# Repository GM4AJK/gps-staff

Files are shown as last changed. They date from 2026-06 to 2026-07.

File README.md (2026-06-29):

# GPS Survey Staff

A DIY RTK GNSS survey staff -- a handheld device for centimetre-level accurate position surveying.

## What is this?

The system consists of two identical handheld units: one set up as a fixed base station, the other carried by the surveyor as a rover. The two communicate wirelessly so the rover can compute corrected, centimetre-accurate positions in real time (RTK -- Real-Time Kinematic positioning).

It's designed to be self-contained and portable -- battery powered, with an onboard display, simple button/encoder controls, and onboard logging of survey data for later processing.

## Project status

Active development. PCB v1.0 ordered 2026-06-25. Firmware bring-up ongoing on Nucleo dev boards.

## Documentation

| Location | Contents |
|---|---|
| [`sdd/`](sdd/) | System design: architecture, unit specs, BLE protocols, UI screen specs |
| [`docs/arch/`](docs/arch/) | Firmware architecture: RTCM3, OTA protocol, SX1262 driver, SD card |
| [`docs/datasheets/`](docs/datasheets/) | Component datasheets and reference documents |
| [`hardware/rtk/`](hardware/rtk/) | PCB electronics design: KiCad files, BOM, design notes |

## License

MIT — see [LICENSE](LICENSE). This project is provided for educational and personal use without warranty of any kind. No liability is accepted for any use of these designs, including use in safety-critical or commercial applications. Use at your own risk.

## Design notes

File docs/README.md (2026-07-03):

# Documents

A catalog of reference documents kept in this repo.

## GNSS coordinate transforms

| Document | Contents |
|---|---|
| [OSGB36_OSTN15_OSGM15.md](OSGB36_OSTN15_OSGM15.md) | How to generate the OSTN15/OSGM15 binary grid, verify it against OS test vectors, deploy it to the tablet SD card, and use `Ostn15Service` to convert ETRS89 → OSGB36/ODN at runtime |

## Future goals

| Document | Contents |
|---|---|
| [TEC.md](TEC.md) | Ionospheric TEC monitoring using the permanent base F9P — dual-frequency geometry-free combination, pierce point calculation, multipath separation, and real-time Three.js globe visualisation. Prerequisite checklist included. |

## Architecture (`arch/`)

System and firmware architecture documentation, with PlantUML diagrams.

| Document | Contents |
|---|---|
| [arch/README.md](arch/README.md) | System overview — hardware roles, data flow, firmware module map |
| [arch/sx1262.md](arch/sx1262.md) | SX1262 driver — bring-up sequence, interrupt model, full API |
| [arch/ota-protocol.md](arch/ota-protocol.md) | OTA protocol — packet format, ota_tx / ota_rx, timing analysis |
| [arch/rtcm3.md](arch/rtcm3.md) | RTCM3 framing — frame format, state machine, buffer pool, CRC24Q |
| [arch/sdcard.md](arch/sdcard.md) | SD card module — state machine, card-detect debounce, DMA transfer model, FatFS integration, D-cache maintenance |

## Datasheets (`datasheets/`)

| Document | Description |
|---|---|
| [Nucleo-F767ZI-Schematic.pdf](datasheets/Nucleo-F767ZI-Schematic.pdf) | Schematic for the Nucleo-F767ZI dev board (STM32F7), used for firmware bring-up before the custom PCB |
| [ANN-MB-00-Datasheet.pdf](datasheets/ANN-MB-00-Datasheet.pdf) | u-blox ANN-MB-00 (UBX-18049862) GNSS antenna datasheet -- the antenna specced for this project. [DigiKey product page](https://www.digikey.co.uk/en/products/detail/u-blox/ANN-MB-00/9817928) |
| [ZED-F9P-05B-Datasheet.pdf](datasheets/ZED-F9P-05B-Datasheet.pdf) | u-blox ZED-F9P-05B GNSS module datasheet -- the GNSS module specced for this project. [DigiKey product page](https://www.digikey.co.uk/en/products/detail/u-blox/ZED-F9P-05B/24708221) |
| [TPS63020-Datasheet.pdf](datasheets/TPS63020-Datasheet.pdf) | TI TPS63020 buck-boost regulator datasheet -- the regulator specced for this project. Order code `TPS63020DSJR` (14-pin VSON exposed-pad, tape-and-reel) confirmed to match. [DigiKey product page](https://www.digikey.co.uk/en/products/detail/texas-instruments/TPS63020DSJR/2353761) |
| [BQ24075-Datasheet.pdf](datasheets/BQ24075-Datasheet.pdf) | TI BQ24075 power path management / battery charger datasheet -- the chip specced for this project. Order code `BQ24075TRGTR` (16-pin VQFN 3x3, tape-and-reel) confirmed to match. [DigiKey product page](https://www.digikey.co.uk/en/products/detail/texas-instruments/BQ24075TRGTR/2202252) |
| [STM32F765VIT6-Datasheet.pdf](datasheets/STM32F765VIT6-Datasheet.pdf) | STMicroelectronics STM32F765VIT6 MCU datasheet -- the MCU specced for this project (LQFP100, base+rover unified design). [DigiKey product page](https://www.digikey.co.uk/en/products/detail/stmicroelectronics/STM32F765VIT6/6137842) |
| [Core1262-LF-Schematic.pdf](datasheets/Core1262-LF-Schematic.pdf) | Waveshare Core1262-LF module schematic (410-510MHz variant) -- the LoRa module specced for this project (covers the 433/434MHz ISM sub-band and 70cm amateur band under GM4AJK licence). Sourced from the [Waveshare wiki](https://www.waveshare.com/wiki/Core1262-868M) (covers the LF/HF family). Note: not available on DigiKey -- ordered via Amazon; double-check the listing is the **LF** (410-510MHz) variant, not the 868M/HF (863-870MHz) variant which does not cover the required bands |
| [SX1262-Datasheet.pdf](datasheets/SX1262-Datasheet.pdf) | Semtech SX1262 LoRa transceiver chip datasheet -- the RF chip on the Core1262-LF module. Sourced from the [Waveshare wiki](https://www.waveshare.com/wiki/Core1262-868M). See also the [libdriver/sx1262](https://github.com/libdriver/sx1262) open-source driver library |
| [um1974-stm32-nucleo144-boards-mb1137-stmicroelectronics-3.pdf](datasheets/um1974-stm32-nucleo144-boards-mb1137-stmicroelectronics-3.pdf) | STMicroelectronics UM1974 -- STM32 Nucleo-144 boards (MB1137) user manual. Reference for power supply options (Section 7.4), JP3/JP1 jumper configuration, and connector pinouts for the Nucleo-F767ZI bench board |
| [um2448-stlinkv3set-debuggerprogrammer-for-stm8-and-stm32-stmicroelectronics-1.pdf](datasheets/um2448-stlinkv3set-debuggerprogrammer-for-stm8-and-stm32-stmicroelectronics-1.pdf) | STMicroelectronics UM2448 -- ST-LINK V3SET debugger/programmer user manual. Reference for CN2/CN3 connector pinouts used when wiring to the Nucleo-F767ZI bench board |
| [SSD1309.pdf](datasheets/SSD1309.pdf) | Solomon Systech SSD1309 OLED display controller datasheet -- the controller for the I2C1 OLED module being added to the Nucleo-F767ZI sandbox |
| [LSM6DSOX.pdf](datasheets/LSM6DSOX.pdf) | STMicroelectronics LSM6DSOX accelerometer + gyroscope datasheet -- the IMU specced for tilt compensation and the bubble-level display, replacing the BNO085 |
| [LSM6DSRX-Datasheet.pdf](datasheets/LSM6DSRX-Datasheet.pdf) | STMicroelectronics LSM6DSRX accelerometer + gyroscope datasheet -- pin-compatible (LGA-14L) alternative to the LSM6DSOX with the same Machine Learning Core/FSM, considered after the LSM6DSOXTR went out of stock. WHO_AM_I reads 0x6B instead of the LSM6DSOX's 0x6C |
| [adafruit_LSM6DSOX_BOB.png](datasheets/adafruit_LSM6DSOX_BOB.png) | Adafruit LSM6DSOX breakout (#4438) schematic -- shows the I2C/SPI signals and address strapping for the breakout board |
| [LIS3MDL.pdf](datasheets/LIS3MDL.pdf) | STMicroelectronics LIS3MDL 3-axis magnetometer datasheet -- the magnetometer originally specced for azimuth/heading. **Now obsolete (no longer available to purchase)**; replaced by the MMC5603NJ -- see below. WHO_AM_I reads 0x3D, I2C address 0x1C or 0x1E depending on the SDO/SA1 pin |
| [MMC5603NJ_RevB_7-12-18.pdf](datasheets/MMC5603NJ_RevB_7-12-18.pdf) | MEMSIC MMC5603NJ 3-axis AMR magnetometer datasheet (Rev B, 2018-07-12) -- replacement for the obsolete LIS3MDL. ±30G FSR, 20-bit resolution (0.0625mG/LSB), 2mG RMS noise, ±1° heading accuracy, I²C fast mode (400kHz) / I3C, 1.62–3.6V supply. **Note:** data-ready interrupt is I3C only -- I²C mode requires polling `Status1.Meas_m_done`. Fixed I²C address (no address-select pin). Package is 0.8×0.8×0.4mm WLP -- requires reflow; see MMC560x-B prototyping board below for the PCB design approach. [DigiKey product page](https://www.digikey.co.uk/en/products/detail/memsic-inc/MMC5603NJ-B/10452797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) |
| [MMC560x-B_UG_RevA.pdf](datasheets/MMC560x-B_UG_RevA.pdf) | MEMSIC MMC560x-B Prototyping Board User Guide (Rev A) -- 22×12mm sub-board with MMC5603NJ pre-assembled and passive components fitted. Breaks out VDDIO, VDD3V, GND, SDA, SCL on 0.1" (2.54mm) pitch headers. Intended PCB design approach for the F765VIT carrier: mount on tall headers to (1) avoid hand-soldering the 0.8mm WLP die and (2) elevate the sensor above PCB-level magnetic interference sources (power traces, inductors) |
| [um1724-stm32-nucleo64-boards-mb1136-stmicroelectronics-4.pdf](datasheets/um1724-stm32-nucleo64-boards-mb1136-stmicroelectronics-4.pdf) | STMicroelectronics UM1724 -- STM32 Nucleo-64 boards (MB1136) user manual. Reference for power supply options (Section 7.5), JP5/JP6 (IDD) jumper configuration, and connector pinouts for the Nucleo-F446RE/G491RE bench boards |
| [Ofcom-IR-2030.pdf](datasheets/Ofcom-IR-2030.pdf) | Ofcom UK Interface Requirement (IR) 2030 -- licence-exempt Short Range Devices (SRDs). Reference for the 433/434MHz power/duty-cycle limits (Table 3.1, IR2030/1/10-12) used to confirm the LoRa link operates under the GM4AJK amateur licence rather than the SRD exemption (see `sdd/README.md`) |
| [um2397-stm32g4-nucleo32-board-mb1430-stmicroelectronics-5.pdf](datasheets/um2397-stm32g4-nucleo32-board-mb1430-stmicroelectronics-5.pdf) | STMicroelectronics UM2397 -- STM32 Nucleo-32 boards (MB1430) user manual. Reference for power supply, jumper configuration, and connector pinouts for the Nucleo-G431KB Fake-F9P boards |
| [USB3300-EZK-TR.pdf](datasheets/USB3300-EZK-TR.pdf) | Microchip USB3300 Hi-Speed USB ULPI PHY datasheet -- the external PHY specced for the rover USB OTG HS interface (480 Mbps MSC + CDC composite). QFN-32 (5x5mm). [DigiKey product page](https://www.digikey.co.uk/en/products/detail/microchip-technology/USB3300-EZK-TR/2355968) |
| [usb4105-spec.pdf](datasheets/usb4105-spec.pdf) | GCT USB4105-GF-A USB-C receptacle datasheet — mid-mount, top-entry, SMD, used as J1 (power/data in). |
| [USBLC6-2SC6.pdf](datasheets/USBLC6-2SC6.pdf) | STMicroelectronics USBLC6-2SC6 dual-line USB ESD protection datasheet — SOT-23-6, 0.5pF/line, 5.25V clamp. Selected for D2 (USB D+/D- protection), replacing the bulk-only PRTR5V0U2X. Single device covers both lines. |
| [KEM_T2076_T52X-530.pdf](datasheets/KEM_T2076_T52X-530.pdf) | Kemet/Yageo T52X/T530 KO-CAP polymer tantalum capacitor datasheet -- covers the T529P series (Miniature, substrate terminal). T529P106M010AAE200 (10µF 10V 0805/EIA-2012-10, 200mΩ ESR) selected for C16/C18/C20 bulk decoupling on STM32F765VIT VDD rails. Fail-open polymer cathode. -- the external PHY specced for the rover USB OTG HS interface (480 Mbps MSC + CDC composite). QFN-32 (5x5mm). [DigiKey product page](https://www.digikey.co.uk/en/products/detail/microchip-technology/USB3300-EZK-TR/2355968) |

## BNO085 (`datasheets/bno085/`)

Out-of-spec side project (not part of the LSM6DSOX+LIS3MDL tilt/azimuth design) -- restored from history for a fresh attempt at the BNO085 over I2C instead of SPI.

| Document | Description |
|---|---|
| [BNO085-Datasheet.pdf](datasheets/bno085/BNO085-Datasheet.pdf) | CEVA/Bosch BNO085 9-DOF IMU datasheet (BNO08X DS 1000-3927 v1.17). [DigiKey product page](https://www.digikey.co.uk/en/products/detail/ceva-technologies-inc/BNO085/9445940) |
| [Adafruit-BNO085-BOB-Schematic.png](datasheets/bno085/Adafruit-BNO085-BOB-Schematic.png) | Adafruit BNO085 9-DOF breakout (#4754, rev C) schematic -- shows the level-shifted SPI/I2C signals (SCK, MOSI, MISO, CS, INT) and P0/P1/BOOTP strapping options. Sourced from the [Adafruit Learning Guide](https://learn.adafruit.com/adafruit-9-dof-orientation-imu-fusion-breakout-bno085) |
| [SH-2-Reference-Manual.pdf](datasheets/bno085/SH-2-Reference-Manual.pdf) | CEVA SH-2 Reference Manual (1000-3625) -- defines the SH-2 sensor hub protocol used over SHTP by the BNO085: Set/Get Feature commands, the full sensor report ID table (e.g. `0x05` Rotation Vector, `0x08` Game Rotation Vector, `0x09` Geomagnetic Rotation Vector), and input report payload layouts (quaternion scaling, accuracy fields, etc.). Sourced from [ceva-ip.com](https://www.ceva-ip.com/wp-content/uploads/SH-2-Reference-Manual.pdf) |

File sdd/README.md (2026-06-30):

# Software and System Design

## Architecture

System-level design: unit roles, technology decisions, data flow, BLE protocols.

| Document | Contents |
|---|---|
| [architecture/SYSTEM.md](architecture/SYSTEM.md) | System overview — unit roles, technology decisions, data flow, RTK concepts |
| [architecture/BASE.md](architecture/BASE.md) | Base unit — implemented capabilities and pending work |
| [architecture/ROVER.md](architecture/ROVER.md) | Rover unit — implemented capabilities and pending work |
| [architecture/HANDHELD.md](architecture/HANDHELD.md) | Handheld/tablet — implemented capabilities and pending work |
| [architecture/GATT.md](architecture/GATT.md) | BLE GATT service and characteristic registry |

## Features

Numbered feature specifications and UI screen specs.

> **When adding a new spec file:** also add it to the `screens` array in
> [`features/00000-Overview.html`](features/00000-Overview.html) so it appears
> in the spec navigator.
>
> **When implementing a screen:** update
> [`features/completed-index.md`](features/completed-index.md) — tick off items
> as they are built and note anything implemented with fake/placeholder data so
> it gets revisited when the real hardware is live.

| Document | Contents |
|---|---|
| [features/00001-wifi-provisioning.md](features/00001-wifi-provisioning.md) | WiFi provisioning — all phases bench-verified |
| [features/00006-OperatingMode.html](features/00006-OperatingMode.html) | Operating Mode selector — 6 modes: Local RF, Rover NTRIP, Base via relay caster, Dual NTRIP, Direct TCP, Fixed Base Station; compact cards with no inline sub-selectors (sub-options live on each mode's config screen) |
| [features/00002-HomeScreen.html](features/00002-HomeScreen.html) | Home screen spec (1024×600 landscape) |
| [features/00003-BaseConfig-0.html](features/00003-BaseConfig-0.html) | Base Config — State 0: top-level mode selector (Survey-in / RTCM Streaming / Satellite View / config strip) |
| [features/00003-BaseConfig-1.html](features/00003-BaseConfig-1.html) | Base Config — State 1: normal view, network table |
| [features/00003-BaseConfig-2.html](features/00003-BaseConfig-2.html) | Base Config — State 2: password entry |
| [features/00003-BaseConfig-2-kbd.html](features/00003-BaseConfig-2-kbd.html) | Base Config — State 2 with virtual keyboard |
| [features/00003-BaseConfig-3.html](features/00003-BaseConfig-3.html) | Base Config — State 3: connecting (spinner) |
| [features/00003-BaseConfig-4.html](features/00003-BaseConfig-4.html) | Base Config — State 4: connection failed |
| [features/00003-BaseConfig-SurveyIn-A.html](features/00003-BaseConfig-SurveyIn-A.html) | Base Config — Survey-in State A: Ready (editable settings, Start button) |
| [features/00003-BaseConfig-SurveyIn-A-kbd.html](features/00003-BaseConfig-SurveyIn-A-kbd.html) | Base Config — Survey-in State A: Numeric keyboard (duration in minutes up to 5 digits; accuracy in metres; tab toggle between both fields) |
| [features/00003-BaseConfig-SurveyIn.html](features/00003-BaseConfig-SurveyIn.html) | Base Config — Survey-in State B: In Progress (progress ring, condition chips, live stats, cancel) |
| [features/00003-BaseConfig-SurveyIn-C.html](features/00003-BaseConfig-SurveyIn-C.html) | Base Config — Survey-in State C: Complete (full green ring, Begin RTCM Streaming button) |
| [features/00003-BaseConfig-Streaming.html](features/00003-BaseConfig-Streaming.html) | Base Config — RTCM Data (broadcast stats, RTCM message activity, rover connection + LoRa link quality) |
| [features/00003-BaseConfig-FixedPos.html](features/00003-BaseConfig-FixedPos.html) | Base Config — Fixed Position entry (monument/benchmark, OSGB36/WGS84) |
| [features/00004-BaseSatelliteView-1.html](features/00004-BaseSatelliteView-1.html) | Base Satellite View — sky plot (az/el, GPS+GLONASS), CN0 bar chart, fix status |
| [features/00005-AboutScreen-1.html](features/00005-AboutScreen-1.html) | About screen — product identity, firmware/hardware versions, the Wizard |
| [features/00007-RoverConfig-Mode1.html](features/00007-RoverConfig-Mode1.html) | Rover Config (Mode 1 — Local RF Link) — pole height entry, live RF link status (RSSI/SNR/frame count), F9P fix type; two dev states: Waiting / Receiving |
| [features/00008-Mode5-RemoteListener.html](features/00008-Mode5-RemoteListener.html) | Mode 5 Direct TCP — Remote Listener (whichever device stays on home WiFi): listen port config, router port-forward reminder, TCP connection status; two dev states: Idle / Connected |
| [features/00009-Mode5-MobileConnector.html](features/00009-Mode5-MobileConnector.html) | Mode 5 Direct TCP — Mobile Connector (whichever device is in the field on hotspot): remote hostname + port entry, Connect/Disconnect button, TCP stream stats; three dev states: Disconnected / Connecting / Connected |
| [features/00013-UsbStorageActive.html](features/00013-UsbStorageActive.html) | Tablet — USB Storage Active: MSC holding screen; SD card info (sessions/size/last file) read before FatFS unmount; amber Connected / green Ejected states; "Disconnect anyway…" confirmation guard; documents CDC↔MSC switching and FatFS mutual exclusion |
| [features/00010-StartSurveySession.html](features/00010-StartSurveySession.html) | Rover — Start Survey Session: filename (auto-suggested, FAT-safe), title (required), description (optional); log written to Tablet SD card directly (ESP32-S3 owns the SD slot — no UART extension needed) |
| [features/00011-RoverWorking.html](features/00011-RoverWorking.html) | Rover — Working Screen: live WGS84 position (7 dp lat/lon, 3 dp height MSL), fix quality block (No Fix / RTK Float / RTK Fix), RF corrections status, scrollable captured-points list (ID/label/lat/lon/hAcc), Capture button grabs next F9P epoch and appends row immediately; three dev states |

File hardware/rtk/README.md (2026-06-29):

# RTK PCB — Electronics Design

## PCB v1.0

- **Ordered:** 2026-06-25, JLCPCB. Tagged `PCB-v1.0` in git.
- **DigiKey BOM** ordered same date.
- **KiCad files:** `hardware/rtk/rtk/`
- **Component BOM:** [BOM.md](BOM.md)

### Board overview

| Property | Value |
|---|---|
| Layers | 4 (JLC04161H-7628 stackup) |
| Layer assignment | L1 top signal + components; L2 solid GND; L3 3.3V power plane; L4 bottom signal |
| RF traces | 50Ω microstrip on L1 (L2 GND reference); ~0.7mm trace width; JLCPCB controlled impedance |
| Design | Unified base + rover — single PCB, role selected by jumper at boot |
| Role-specific DNP | USB-C #1 (base: OTG FS) vs USB-C #2 + ULPI PHY (rover: OTG HS) |

### Unified PCB approach

Both units built from the same PCB. Mode selection:
- `PA0` (BASE_ROVER_MODE_SELECT): internal pull-up, link open = base, link to GND = rover
- Same STM32 firmware binary on both; mode gates peripheral init and code paths at runtime
- ESP32-S3 Zero firmware differs per role (base: WiFi NTRIP + BLE prov; rover: BLE GATT server)

---

## Schematic Connection Checklist

Consolidated list of every system wired on the schematic. Reference against the BOM and KiCad
to verify nothing is missed.

1. **ZED-F9P-05B** — UART1 (pins 42/43) → STM32 UART5 (nav + UBX config); UART2 (pins 26/27)
   → STM32 UART7 (PA8 RX ← F9P TXD2, PA15 TX → F9P RXD2) for RTCM input from LoRa;
   D_SEL (pin 47) → PE14 high (UART/I2C mode); RF_IN → GNSS SMA via 50Ω trace;
   1PPS → STM32 GPIO (log timestamping); power + decoupling.

2. **GNSS antenna (ANN-MB-00)** — SMA female through-hole; bias-T 3.3V LNA feed on RF line.

3. **LoRa (Core1262-LF / SX1262)** — dedicated SPI bus; BUSY checked before every transaction;
   DIO1/IRQ → STM32 GPIO; NRESET; separate SMA (433/434MHz).

4. **STM32F765VIT6** — UART (F9P + spare); 2× dedicated SPI (LoRa, IMU); SDMMC1 4-bit
   (PC8/D0, PC9/D1, PC10/D2, PC11/D3, PC12/CLK, PD2/CMD — fixed AF pins);
   I2C4 (PD12 SCL, PD13 SDA — display + IMU); USB OTG FS (PA11/PA12, base) or
   OTG HS + ULPI (rover); ADC (battery divider PA1); SWD.

5. **Power chain** — TPS63020 with D1 + C_SS soft-start on FB node; BQ24075 power-path
   (EN1/EN2/SYSOFF/nCE → STM32 GPIO outputs; nPGOOD/nCHG → STM32 GPIO inputs; TS → 10K to GND);
   LP103454-PCM-LD 2-wire battery connector (J3); 100K/100K battery voltage divider → PA1 ADC.

6. **USB-C (J1)** — single connector footprint, routed via USB3300 ULPI PHY (U8) to STM32
   OTG HS; CC1/CC2 5.1K pull-downs (R11/R12); USBLC6-2SC6 ESD (D2); USB3300 RST (PC1);
   24MHz TCXO (Y2); 12K RBIAS (R9); full decoupling.
   *(Base build: USB-C #2 + ULPI PHY fitted; USB-C #1 DNP. Both are HS-capable.)*

7. **IMU (LSM6DSOX/DSRX, U7)** — I2C4 (PD12/PD13); INT1 → PD14; INT2 → PD15.
   **Magnetometer (MMC5603NJ)** — sub-board via J11 (6-pin 0.1" header, I2C4 bus).

8. **SD card (J6)** — SDMMC1 4-bit bus (fixed AF pins above); card-detect → GPIO; well-decoupled VCC.

9. **STM32 backup domain (VBAT)** — wired directly to 3.3V rail; no coin cell.

10. **Config storage** — SD card file; no EEPROM fitted.

11. **OLED display (SSD1309)** — via J7 header; I2C4 bus (PD12 SCL, PD13 SDA); 0x3C/0x3D.
    On PCB v1.0. Driver bench-verified on F767ZI (task_display.c, ssd1309.c).

12. **Status LEDs** — LD3 (PD5, green) + LD4 (PD6, red): MCU open-drain + pull-ups R20/R21;
    LD1/LD2 hardwired to BQ24075 nPGOOD/nCHG.

13. **Mode-selection jumper** — PA0 GPIO input, internal pull-up; high = base, low = rover.

14. **BOOT0** — 2-pin header, 10K pull-down to GND; fitted = DFU bootloader.

15. **ESP32-S3 Zero (U5)** — spare STM32 UART; 3.3V power + decoupling; mode-select via
    PE2 (GP1) + PE3 (GP2/MODE_VALID). Base: WiFi NTRIP + BLE prov server.
    Rover: BLE GATT server to handheld.

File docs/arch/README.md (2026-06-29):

# GPS Staff — Firmware Architecture

## Overview

The GPS survey staff is a two-unit RTK GNSS system.  A **base station** is
placed at a known (or surveyed-in) position; a **rover** is the handheld
staff.  The base receives RTCM3 correction data from its ZED-F9P GNSS module
and broadcasts it to the rover over a 434 MHz radio link.  The rover feeds
the corrections to its own ZED-F9P to achieve centimetre-level relative
accuracy.

The target hardware is a unified STM32F765VIT6 PCB — **PCB v1.0 ordered
2026-06-25, ZED-F9P-05B ordered same date**.  Until hardware arrives, firmware
development runs on three Nucleo boards as bench stand-ins.

For system-level design decisions (component choices, data flow, unit roles)
see [`sdd/architecture/SYSTEM.md`](../../sdd/architecture/SYSTEM.md), which
includes the high-level block diagram ([system-overview.png](../../sdd/architecture/system-overview.png)).

---

## Bench Hardware Roles

| Board | Role | Key peripherals active |
|---|---|---|
| Nucleo-G431KB (×2) | **Fake F9P** — streams sample RTCM3 data from `firmware/data/` | UART1 @ 115200 — RTCM3 out (base mode) / in (rover mode) |
| Nucleo-F767ZI | **Base station** — bench-tethered, UART debug via PuTTY | UART2 @ 115200 RTCM3 in from G431; SPI2 → SX1262 GFSK TX; SDMMC SD card; I2C1 SSD1309 OLED |
| Nucleo-F446RE | **Rover** — portable, battery-powered, OLED-only UI | SPI2 → SX1262 GFSK RX; UART3 @ 115200 RTCM3 out to G431; I2C1 SSD1309 OLED |

The G431 boards talk to the "big" boards over UART patch cables, simulating
the UART link between the ZED-F9P and STM32F765 on the finished PCB.

---

## System Data Flow

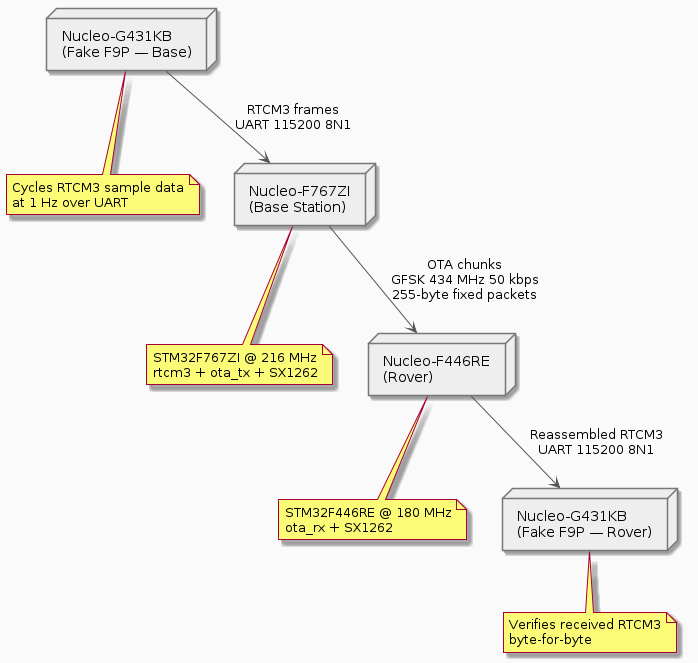
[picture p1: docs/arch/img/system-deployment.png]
System deployment


> **ToDo:** `img/system-deployment.puml` and `img/firmware-modules.puml` were drawn against the
> Nucleo bench stand-in configuration. Both need to be redrawn once PCB v1.0 is in hand and the
> bench boards retire. The replacement high-level block diagram is
> [`sdd/architecture/system-overview.png`](../../sdd/architecture/system-overview.png).

---

## Firmware Module Map

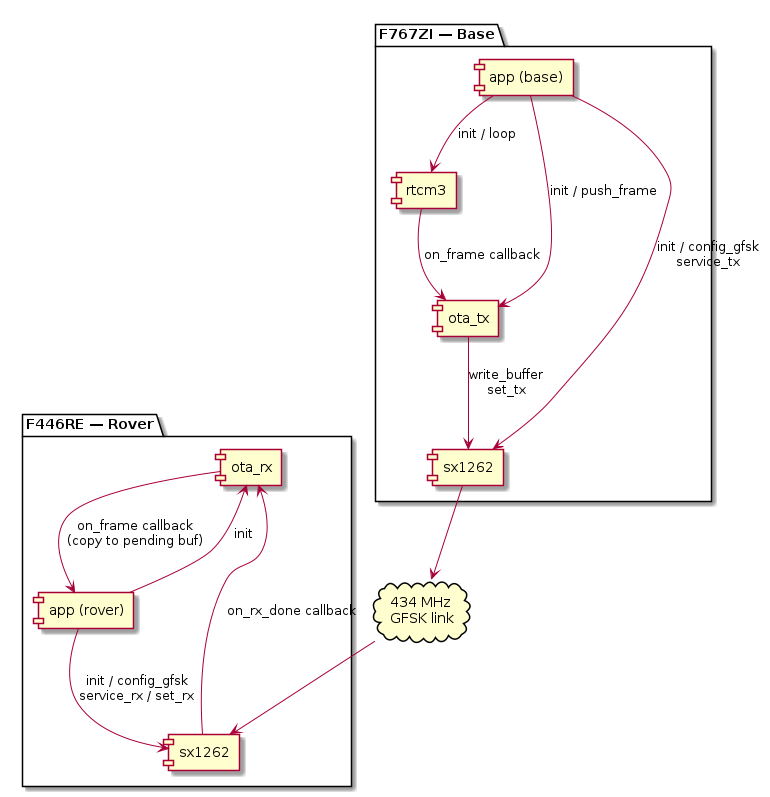
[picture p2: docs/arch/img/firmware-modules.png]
Firmware modules


---

## OTA Packet Format (summary)

Every radio packet is exactly **255 bytes** (fixed-length GFSK).  The first
five bytes are a header; the remaining 250 carry RTCM3 payload bytes.  See
[ota-protocol.md](ota-protocol.md) for the full description.

| Byte | Field | Notes |
|---|---|---|
| 0 | `type` | `0x01` = RTCM3 chunk |
| 1 | `seq` | Frame sequence number, 0–255 wrapping |
| 2 | `chunk_idx` | 0-based chunk index within the frame |
| 3 | `chunk_count` | Total chunks for this frame |
| 4 | `data_len` | Valid RTCM3 bytes in this chunk (1–250) |
| 5–254 | `data` | RTCM3 payload bytes; last chunk zero-padded |

---

## Document Index

| Document | Contents |
|---|---|
| **[sx1262.md](sx1262.md)** | SX1262 driver — architecture, GFSK bring-up, interrupt model, full API |
| **[ota-protocol.md](ota-protocol.md)** | OTA protocol — packet format, ota_tx chunking, ota_rx reassembly, timing |
| **[rtcm3.md](rtcm3.md)** | RTCM3 module — frame format, state machine, buffer pool, IRQ/loop split |
| **[sdcard.md](sdcard.md)** | SD card module — state machine, card-detect debounce, DMA transfer model, FatFS integration |

---

## Bench Status (as of 2026-06-25)

**Radio / RTCM link** — bench-verified and stable:
- GFSK link at 434 MHz, 50 kbps, 25 kHz deviation — 7–8× less air time per cycle than the earlier LoRa SF7/BW500 configuration
- G431 Fake-F9P-Rover holds **SYNCED** indefinitely, zero accumulating mismatches at 1064 bytes/cycle (1005 + 1074 + 1084 + 1094 + 1124 bytes)
- `SX1262_WITH_LOGGING` disabled on rover (F446RE) to keep the post-reception blocking window short; enabled on base (F767ZI) where timing pressure is absent

**SD card** — bench-verified on F767ZI:
- FatFS + SDMMC DMA, sequentially-numbered session files
- `FF_FS_NORTC` set — file timestamps will be wired to ZED-F9P UTC when F9P arrives

**IMU / magnetometer** — bench-verified on F446RE I2C1:
- LSM6DSOX accelerometer + gyroscope driver (PR #124)
- MMC5603NJ magnetometer driver replaces obsolete LIS3MDL (PR #129, heading unvalidated)
- Tilt fusion and soft-iron calibration: deferred pending PCB delivery

**Awaiting hardware:**
- ZED-F9P UART driver — ordered 2026-06-25
- PE2/PE3 mode-select GPIO — PCB v1.0 ordered 2026-06-25

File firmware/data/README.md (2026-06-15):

# Firmware Data

A catalog of binary/data files used by firmware for testing or simulation.

| File | Description |
|---|---|
| [CambridgeSensoriisSample.bin](CambridgeSensoriisSample.bin) | Recorded RTCM3 stream (2728 bytes, 39 frames: 1005/1074/1084 cycle, GPS+GLONASS MSM4), captured from the `CambridgeSensoriis` RTK2GO NTRIP mount. Intended as a canned playback payload for a Nucleo-based "fake F9P" base, to test the base->LoRa->rover transport pipeline without real GNSS hardware |

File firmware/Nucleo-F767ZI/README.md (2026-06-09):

# Nucleo-F767ZI Sandbox

A bare CubeMX project targeting the STM32F767ZI Nucleo board, used as a
"play pen" for developing and bench-testing modules before porting them
into `rtk-base`/`rtk-rover` (pin assignments, peripherals, etc. will
differ slightly between boards).

## Programming / debugging

The on-board ST-LINK has been physically cut away from this board (freed
up to program other STM32 targets). An external **ST-LINK V3 programmer**
is wired directly to the Morpho headers instead:

| MCU Pin | Signal | Role | Header / Pin | Prog |
|---|---|---|---|---|
| 3V3  | PWR | Power | CN11 pin 12 | CN2 Pin 1 |
| GND  | GND | Ground | CN11 pin 20 | CN2 Pin 20 |
| PA13 | SWDIO (TMS) | SWD data | CN11 pin 13 | CN2 Pin 7 |
| PA14 | SWCLK (TCK) | SWD clock | CN11 pin 15 | CN2 Pin 9 |
| NRST | Reset | SWD reset | CN11 pin 14 | CN2 Pin 15 |
| PB10 | USART3_TX → ST-LINK RX | VCP UART, MCU TX -> probe RX | CN10 pin 32 | CN3 Pin 2 |
| PD9  | USART3_RX ← ST-LINK TX | VCP UART, probe TX -> MCU RX | CN11 pin 67 | CN3 Pin 1 |

PA13/PA14/NRST are the MCU's native SWD pins. USART3_TX is on PB10
(CN10 pin 32) and USART3_RX is on PD9 (CN11 pin 67); both route through
to the external ST-LINK V3 VCP UART.

## Power supply (bench PSU)

With the ST-LINK section cut away there is no USB power. Two external
options (UM1974 Table 7):

| Input | Pin | Voltage | Max current | JP3 setting |
|---|---|---|---|---|
| E5V | CN11 pin 6 | 4.75–5.25 V | 500 mA | Pins 1–2 bridged |
| V_IN | CN8 pin 15 | 7–12 V | 800 mA @ 7 V | Pins 5–6 bridged |

**Use V_IN (CN8 pin 15)** — JP3 pins 5–6 are already bridged on this board
(confirmed from physical inspection), and CN8 pin 15 is the pin that has
previously been used.

Required jumper state before applying power:
- **JP3**: pins 5–6 bridged (V_IN position — already set)
- **JP1**: remove jumper (OFF)

Set bench PSU to **7.0 V, 500 mA** current limit. The onboard LD1117
regulates this to 5 V, which then feeds the 3.3 V LDO. The green LED LD6
lights when the board is correctly powered.

Full reference: UM1974 STM32 Nucleo-144 boards user manual,
Section 7.4 — `docs/datasheets/um1974-stm32-nucleo144-boards-mb1137-stmicroelectronics-3.pdf`

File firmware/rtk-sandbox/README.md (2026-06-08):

# rtk-sandbox

A CubeMX/CubeIDE reference project targeting the **STM32F765VIT6** — the exact MCU used on
the custom GPS staff PCB.

## Purpose

This project is **never flashed to a device**. Its sole purpose is to serve as a CubeMX
code-generation reference for the real target chip. When writing register-level peripheral
drivers for `rtk-base`, use this project to ask "what would CubeMX generate for this
peripheral on this exact MCU?" and read the output as a reference.

Useful for:
- Deriving register init sequences for peripherals not yet in `rtk-base`
- Checking pin alternate-function assignments on the F765VIT6 specifically
- Exploring clock configuration options via the CubeMX clock tree GUI
- Any other "what does the HAL do here?" questions before writing bare-metal code

## Relationship to other firmware projects

| Project | Target | Role |
|---|---|---|
| `rtk-base` | STM32F765VIT6 (custom PCB) | **Real firmware** — the only project ever flashed |
| `rtk-sandbox` | STM32F765VIT6 (custom PCB) | **CubeMX code reference** — this project |
| `Nucleo-F767ZI` | STM32F767ZI (Nucleo-144 board) | **Physical hardware sandbox** — bench bring-up of peripheral modules before porting to PCB |

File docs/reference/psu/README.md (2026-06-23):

# BOM and links

| Ref | PartNum | Link | Descr |
|-----|---|---|---|
| Rfbb | [CRCW0402137KFKED](https://www.vishay.com/docs/20035/dcrcwe3.pdf) | [DigiKey](https://www.digikey.co.uk/en/products/detail/vishay-dale/CRCW0402137KFKED/1178249) | Resistor 137k 1% 1/16W 0402 |
||| [Mouser](https://www.mouser.co.uk/ProductDetail/Vishay/CRCW0402137KFKED?qs=8wskyPz2qw2oEbG%2FMX%2Ft%2FQ%3D%3D) |
| C4 (CvinA) | EMK107B7104KA-T | [DigiKey](https://www.digikey.co.uk/en/products/detail/taiyo-yuden/emk107b7104ka-t/930592) | cap 100n 16v 0603 |
||| [Mouser](https://www.mouser.co.uk/ProductDetail/TAIYO-YUDEN/EMK107B7104KA-T?qs=I6KAKw0tg2ybqzX8hKPgfw%3D%3D) |
| Cin | [C1608X5R1A226M080AC](https://product.tdk.com/ja/search/capacitor/ceramic/mlcc/info?part_no=C1608X5R1A226M080AC) | [DigiKey](https://www.digikey.co.uk/en/products/detail/tdk/C1608X5R1A226M080AC/3661560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) | Cap 22uF 10v 0603 |
||| [Mouser](https://www.mouser.co.uk/ProductDetail/TDK/C1608X5R1A226M080AC?qs=dfay7wIA1uED3Fb1o4f9Dg%3D%3D) |
| Cout | [MSASJ21GBB5476MTNA01](https://ds.yuden.co.jp/TYCOMPAS/ut/detail?pn=MSASJ21GBB5476MTNA01&u=M) | [DigiKey](https://www.digikey.co.uk/en/products/detail/taiyo-yuden/MSASJ21GBB5476MTNA01/16662576) | Cap 47uF 6.3v 0805 (2012 metric) |
||| [Mouser](https://www.mouser.co.uk/ProductDetail/TAIYO-YUDEN/MSASJ21GBB5476MTNA01?qs=tlsG%2FOw5FFieGPnwRR3k%2FA%3D%3D) |
| L1 | [DFE201610E-1R0M=P2](https://pim.murata.com/en-eu/pim/details/?productCategoryId=inductor&partNum=DFE201610E-1R0M%23) | [DigiKey](https://www.digikey.co.uk/en/products/detail/murata-electronics/DFE201610E-1R0M-P2/7430535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) | Ind 1uH 2.7A 57mOhm 0806 (2016 metric) |
||| [Mouser](https://www.mouser.co.uk/ProductDetail/Murata-Electronics/DFE201610E-1R0M%3dP2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) |
| U1 | [TPS63020DSJR](https://www.ti.com/lit/ds/symlink/tps63020.pdf?ts=1782098349380) | [DigiKey](https://www.digikey.co.uk/en/products/detail/texas-instruments/TPS63020DSJR/2353761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) | IC TPS63020DSJR |
||| [Mouser](https://www.mouser.co.uk/ProductDetail/Texas-Instruments/TPS63020DSJR?qs=C44r%252BX3hXgL3LjjgiOMWew%3D%3D) |
| Rfbt | [CRCW0402768KFKED](https://www.vishay.com/docs/20035/dcrcwe3.pdf) | [DigiKey](https://www.digikey.co.uk/en/products/detail/vishay-dale/CRCW0402768KFKED/1178336) | Resistor 768K 1% 1/16W 0402 (1005 metric) Thick film |
||| [Mouser](https://www.mouser.co.uk/ProductDetail/Vishay/CRCW0402768KFKED?qs=CrYM0bloiFJM%252Bg4a2Fs2hQ%3D%3D) |
| J1,J2 | [USB4105-GF-A-060](https://gct.co/files/specs/usb4105-spec.pdf) | [DigiKey](https://www.digikey.co.uk/en/products/detail/gct/USB4105-GF-A-060/14559036) | USB C Recp |
| J3 | [B2B-PH-SM4-TB](https://www.jst-mfg.com/product/pdf/eng/ePH.pdf) | [DigiKey](https://www.digikey.co.uk/en/products/detail/jst-sales-america-inc/B2B-PH-SM4-TB/926641) | Connector JST Battery |
| C1 | [TAJR105M016RNJ](https://datasheets.kyocera-avx.com/TAJ.pdf) | [DigiKey](https://www.digikey.co.uk/en/products/detail/kyocera-avx/TAJR105M016RNJ/808789) | CAP 1u 16v Tant 0805 |
| C2, C3 | [TAJP475K016RNJ](https://datasheets.kyocera-avx.com/TAJ.pdf) | [DigiKey](https://www.digikey.co.uk/en/products/detail/kyocera-avx/TAJP475K016RNJ/3660895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) | CAP 4u7 16V tant 0805 |
| U2 | [TPS63020DSJR](https://www.ti.com/general/docs/suppproductinfo.tsp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) | [DigiKey](https://www.digikey.co.uk/en/products/detail/texas-instruments/TPS63020DSJR/2353761) | IC Buck TPS63020DSJR  |
| J6 | [MEM2052-00-195-00-A](https://gct.co/files/specs/mem2052-spec.pdf) | [DigiKey](https://www.digikey.co.uk/en/products/detail/gct/MEM2052-00-195-00-A/18091687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) | SD card Mini |
| PHY | [USB3300-EZK-TR](https://ww1.microchip.com/downloads/aemDocuments/documents/OTH/ProductDocuments/DataSheets/00001783C.pdf) | [DigiKey](https://www.digikey.co.uk/en/products/detail/microchip-technology/USB3300-EZK-TR/3873181) | PHU USB3300-EZK-TR |
| TCXO | [ASTX-H11-16.000MHZ-T](https://abracon.com/Oscillators/ASTX-H11.pdf) | [DigiKey](https://www.digikey.co.uk/en/products/detail/abracon-llc/ASTX-H11-16-000MHZ-T/3641095) | TCXO |
| D_ESD | PRTR5V0U2X,215 | DigiKey/Mouser — search PRTR5V0U2X | USB D+/D- dual-line ESD TVS, SOT-363, Nexperia. Clamp 5V, fits between USB-C connector and USB3300 DP/DM pins |

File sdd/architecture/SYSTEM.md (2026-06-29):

# System Architecture — GPS Survey Staff

## Overview

A DIY RTK GNSS survey staff built around the u-blox ZED-F9P-05B module on a custom carrier PCB.
Two identical PCBs — one configured as base station, one as rover — communicate via LoRa.
Centimetre-level relative accuracy is the target.

---

## System Diagram

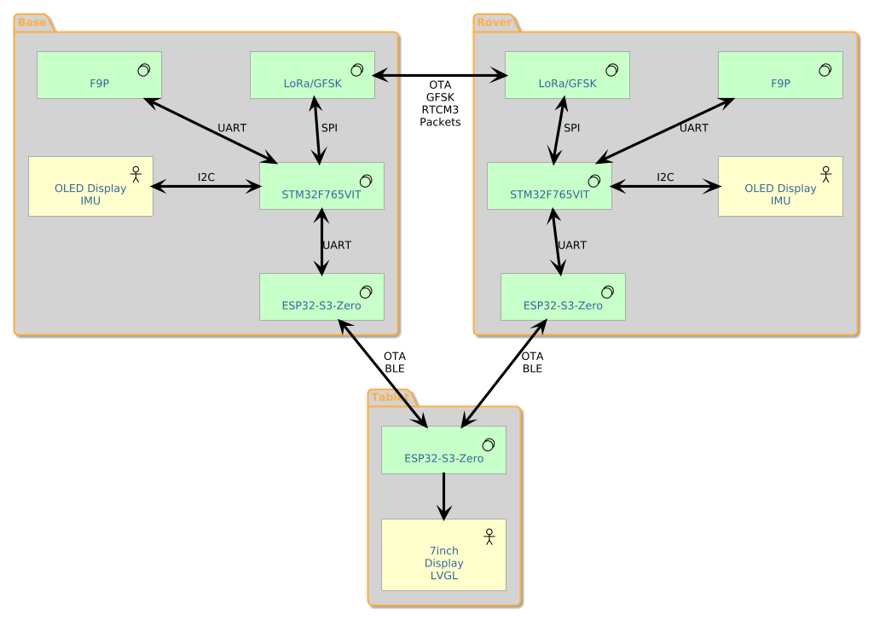
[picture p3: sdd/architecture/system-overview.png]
System overview block diagram


```
BASE STATION [identical PCB]          ROVER (staff/pole) [identical PCB]
+-------------------------+           +-------------------------+
|  ZED-F9P (base mode)    |           |  ZED-F9P (rover mode)   |
|  RTCM out on UART       |           |  receives RTCM, RTK fix |
+--------+----------------+           +--------+----------------+
         | UART                                | UART
+--------v----------------+  LoRa RTCM -->   +--------v----------------+
|   STM32F765VIT6         |  <-- LoRa CMD    |   STM32F765VIT6         |
|   RTCM reader, LoRa TX  |                  |   RTCM->F9P, SD log     |
|   survey-in control     |                  |   OLED: tilt/fix/status |
+--------+----------------+                  +--------+----------------+
         | UART (RTCM)                                | UART
+--------v----------------+                +----------v--------------+
|   ESP32-S3 Zero         |                |   ESP32-S3 Zero         |
|   WiFi → NTRIP caster   |                |   BLE 5.0 GATT server   |
|   BLE WiFi provisioning |                |   (position, status,    |
+--------+----------------+                |    command channel)     |
         v                                 +----------+--------------+
  NTRIP caster                                        | BLE
  (RTK2GO, Emlid, etc.)                   +----------v--------------+
                                          |   Handheld data         |
                                          |   collector             |
                                          |   4.3" ESP32-S3 (HH)   |
                                          |   7" ESP32-S3 (tablet)  |
                                          +-------------------------+
```

- Single PCB design; identical STM32 firmware on both units; mode (base/rover) selected by hardware jumper at boot
- Different ESP32-S3 Zero firmware per role — same module on both PCBs
- F9P handles all RTK computation onboard — STM32F7 is smart pipe + data logger

---

## Unit Roles

| Unit | Firmware | Role |
|---|---|---|
| Base station | `rtk-base` + `esp32-base` | Surveys-in, enters fixed mode, TX RTCM over LoRa; streams RTCM to NTRIP caster over WiFi in gateway mode |
| Rover (staff) | `rtk-base` (rover mode) + `esp32-base` (rover role) | Receives RTCM from Base, passes to F9P, logs RTK-corrected positions to SD card |
| Handheld (4.3") | `esp32-handheld` | Survey UI: position readout, WiFi provisioning for Base, session management |
| Tablet (7") | `esp32-tablet` (TBD, arriving ~2026-07-01) | Full-resolution survey UI on 1024×600 display |

For detailed implemented capabilities, see:
[BASE.md](BASE.md) · [ROVER.md](ROVER.md) · [HANDHELD.md](HANDHELD.md)

---

## Key Technology Decisions

### GNSS: ZED-F9P-05B

L1/L2 dual-frequency RTK module. Handles all RTK computation onboard; STM32 is a data pipe.
RTCM constellation: GPS + GLONASS only — reduces 1Hz stream from ~700 bytes (4-GNSS) to
~255-325 bytes, fitting 2 SX1262 LoRa packets instead of 3-4.

### MCU: STM32F765VIT6

100-pin LQFP, 2MB flash, 512KB RAM, 216MHz Cortex-M7. Same F7 family as the Nucleo-F767ZI
dev board — firmware port to PCB is pin reassignment only. Single unified PCB for both
base and rover; mode selected by jumper.

### Radio: SX1262 (Waveshare Core1262-LF, 410-510MHz)

22dBm output, -148dBm sensitivity — massively over-specified for 100m working range.
SF7/BW500: ~25ms time-on-air, ~2.5% duty cycle at 1Hz — within ISM no-duty-cycle sub-band
(434.04-434.79MHz, 10mW). Full 22dBm available under GM4AJK amateur licence on 70cm band.

**Regulatory basis:** The project at SF7/BW500/+22dBm does not fit IR2030/1/10 (10mW limit),
IR2030/1/11 (1mW limit), or IR2030/1/12 (BW ≤ 25kHz required for 100% duty cycle). Operation
is under the GM4AJK amateur radio licence on the 70cm band. See `docs/datasheets/Ofcom-IR-2030.pdf`.

### BLE / WiFi Coprocessor: ESP32-S3 Zero

Fitted on both PCBs (identical build); firmware differs by role.
Base: WiFi NTRIP gateway + BLE WiFi provisioning server.
Rover: BLE 5.0 GATT server to handheld (position, status, command channel).

### Power: TPS63020 + BQ24075

TPS63020 buck-boost gives stable 3.3V across full LiPo discharge curve.
BQ24075 provides power-path management — USB-C 5V charging and operation simultaneously,
no glitch on hot-plug. EN1/EN2 firmware-controlled for USB current negotiation.

### IMU: LSM6DSRX + MMC5603NJ

LSM6DSRX (6-DOF) for tilt; MMC5603NJ for magnetic heading.
Combined purpose: pole lean correction — computes horizontal offset of ground contact point
when pole is not perfectly vertical.

Lean correction (simplified):
```
gravity = normalize(accel_xyz)
tilt_angle = arccos(gravity.z)
tilt_azimuth = heading + arctan2(gravity.y, gravity.x)
offset = pole_height × sin(tilt_angle)
```

At 2m pole height: 1° lean = 35mm uncorrected error; IMU correction reduces residual to ~3.5mm.

MMC5603NJ replaces the obsolete LIS3MDL (no longer purchasable). Connected via MMC560x-B
sub-board (J11) — avoids hand-soldering the 0.8mm WLP die.

### Data Logging: SDMMC 4-bit + FatFS

SDMMC1 on fixed AF pins (PC8-12/PD2). 4-bit bus chosen for USB MSC read path throughput;
SD write at 1Hz is trivially low for any interface. FatFS + STM32 HAL SDMMC + DMA.

### Configuration Storage: SD Card

Config file on SD card (pole height, LoRa band, calibration coefficients). No EEPROM.
VBAT wired directly to 3.3V — backup domain available while powered, lost on power-off;
no cross-power-cycle retention needed since config is on SD.

---

## System Architecture — Three-Tier, Split-Brain App

### Three-tier hardware abstraction

Each field unit (Base and Rover) has the same two-chip structure:

```
┌─────────────────────────────────────────────────────────────────┐
│  HARDWARE LAYER — STM32F765VIT6                                  │
│  Owns all hardware buses. Exposes services and accepts commands  │
│  via UART protocol. Has no knowledge of BLE, app state or UI.   │
│                                                                  │
│  F9P (2× UART) · SX1262 (SPI) · SDMMC · I2C (OLED + IMU)      │
│  Power mgmt GPIO · Battery ADC · LEDs · USB OTG                 │
└───────────────────────┬─────────────────────────────────────────┘
                        │ UART — hardware abstraction protocol
┌───────────────────────▼─────────────────────────────────────────┐
│  APPLICATION LAYER — ESP32-S3-Zero                               │
│  Owns all application state and logic. Commands the STM32.      │
│  Consumes telemetry forwarded by STM32 (UBX parsed to simple    │
│  binary messages). Serves BLE GATT to the Tablet.               │
│                                                                  │
│  BASE: operating mode state machine · survey-in control ·       │
│        WiFi NTRIP gateway · BLE GATT server (Base Config)       │
│  ROVER: position/fix state · RTCM lock status ·                 │
│         BLE GATT server (Rover status to Tablet)                │
└─────────────────────────────────────────────────────────────────┘
```

The STM32 UART protocol is a **hardware abstraction boundary** — not byte-passing.
The STM32 exposes services (parsed GNSS data, LoRa TX, OLED rendering, IMU readings)
and accepts commands (start survey-in, send RTCM packet, show display message),
hiding all bus-level complexity (UBX framing, SPI timing, SDMMC DMA, I2C) from the
application layer entirely.

---

### Split-brain application across three ESP32-S3 devices

The application as experienced by the user is distributed across three ESP32-S3s:

```
┌──────────────────────────────────────────────────────────────┐
│  TABLET ESP32-S3  (4.3" handheld or 7" tablet)              │
│  UI layer — LVGL display, user interaction, screen routing.  │
│  Connects to Base ESP32 (BLE, temporary) for config.        │
│  Connects to Rover ESP32 (BLE, permanent) for live data.    │
└───────────┬──────────────────────────────┬───────────────────┘
            │ BLE (temporary, UI-driven)   │ BLE (permanent)
┌───────────▼───────────────┐  ┌───────────▼───────────────────┐
│  BASE ESP32-S3-Zero       │  │  ROVER ESP32-S3-Zero           │
│  App layer — base side.   │  │  App layer — rover side.       │
│  Operating mode s/m.      │  │  Fix quality, RTCM lock.       │
│  Survey-in control.       │  │  Position data relay.          │
│  GATT: Base Config svc.   │  │  GATT: Rover status svc.       │
│  WiFi NTRIP gateway.      │  │  Receives Base battery %       │
│                           │  │  via GFSK → STM32 → UART.     │
└───────────────────────────┘  └───────────────────────────────┘
```

No single ESP32 holds the complete application state — it is intentionally split:
- **Base ESP32** knows what the Base is doing (mode, survey-in progress, NTRIP status).
- **Rover ESP32** knows what the Rover is doing (RTK fix quality, RTCM lock, battery).
- **Tablet ESP32** knows what the user is doing (which screen, what they last tapped).

The Tablet is the only device that sees the full picture, assembled at runtime from
BLE data received from both field units. Each field unit's ESP32 is authoritative for
its own state only; neither talks directly to the other's ESP32.

State is held in ESP32 RAM only. All three units share power with their respective
STM32 (or have no STM32 in the Tablet's case). Power cycle = clean start on any unit;
no NVS persistence is required or expected.

---

## Firmware Projects

Three CubeIDE projects (STM32 hardware layer):

| Project | Target | Role |
|---|---|---|
| `rtk-base` | STM32F765VIT6 (custom PCB) | Hardware layer — base and rover mode in one binary |
| `rtk-sandbox` | STM32F765VIT6 (custom PCB) | CubeMX code reference — never flashed |
| `Nucleo-F767ZI` | STM32F767ZI (Nucleo-144) | Hardware sandbox — bench-test peripherals before porting |

Three IDF projects (ESP32 application layer):

| Project | Target | Role |
|---|---|---|
| `esp32-base` | ESP32-S3-Zero | Base application layer — GATT server, WiFi NTRIP, mode state machine |
| `esp32-handheld` | ESP32-S3 4.3" | Tablet UI layer — LVGL, BLE client to Base + Rover |
| `esp32-tablet` | ESP32-S3 7" | Tablet UI layer (higher resolution) — same role as handheld |

Note: there is no separate `esp32-rover` project yet — Rover ESP32 firmware is TBD.

CubeMX owns in `rtk-base`: clock tree, mode-select GPIO, debug UART, SWO. Everything
else is application-owned, initialised at register level. No `MX_*_Init()` beyond
those four. The app reads the mode jumper at boot and brings up only the peripherals
the physical assembly has.

Full STM32 firmware module documentation: [`docs/arch/`](../../docs/arch/)

---

## Status Beacon Protocol

**Terminology used throughout this section:**
- **Long-haul link** — the link the remote device uses to send data (RF in Mode 1, TCP internet in Mode 5). Carries RTCM and status beacons.
- **Short-haul link** — local BLE between a field unit's ESP32 and the Tablet.

The remote device (Base in Mode 1 / Mode 5A, Rover in Mode 5B) sends a small
status packet every **10 seconds** over the long-haul link. This is the mechanism
by which the Tablet's status bar shows remote battery %.

### Transport

| Mode | Direction | Mechanism |
|---|---|---|
| Mode 1 (RF) | Base → Rover (long-haul) | Interleaved in GFSK stream alongside RTCM. Rover STM32 deframes it and routes to Rover ESP32 via UART (`MSG_STATUS_BEACON`). Rover ESP32 forwards to Tablet over short-haul BLE GATT notify. |
| Mode 5 (TCP) | Remote → Mobile (long-haul) | Sent in reverse direction on the same open TCP socket. Mobile ESP32 receives directly — no STM32 involvement. Tablet reads via short-haul BLE from the mobile ESP32. |
| Modes 2/3/4 | — | No long-haul link between devices. Status bar shows `—` for remote device. |

### Framing

Status packets are interleaved with RTCM bytes on the same byte stream (RF or TCP).
RTCM3 packets are identified by sync byte `0xD3`. Status packets use a distinct magic
that cannot occur as a valid RTCM3 sync:

```
┌────────┬────────┬────────┬──────────────────────┬────────┐
│ 0xAA   │ 0x55   │ LEN    │ PAYLOAD (LEN bytes)  │ CRC-8  │
│ magic0 │ magic1 │ uint8  │                      │        │
└────────┴────────┴────────┴──────────────────────┴────────┘
```

The RTCM/status deframer checks each sync byte: `0xD3` → RTCM path, `0xAA` (+`0x55` confirmation) → status path.

### Payload (~8 bytes)

| Offset | Field | Type | Notes |
|---|---|---|---|
| 0 | `device_id` | uint8 | `0x01` = Base, `0x02` = Rover |
| 1 | `battery_pct` | uint8 | 0–100, from STM32 ADC |
| 2 | `fix_type` | uint8 | `0` = none, `1` = float, `2` = RTK fix |
| 3–4 | `hacc_mm` | uint16 LE | Horizontal accuracy from UBX-NAV-PVT (mm) |
| 5 | `rtcm_rate` | uint8 | RTCM messages/sec output (0 if not streaming) |
| 6–7 | `uptime_s` | uint16 LE | Seconds since power-on |

Total wire size: 2 (magic) + 1 (len) + 8 (payload) + 1 (CRC) = **12 bytes**.

### Local battery — same path, different source

The local device (Rover in Mode 1 / Mode 5A, Base in Mode 5B) also has a battery
that needs to reach the Tablet. It runs the same `task_battery` on its own STM32 and
the value travels via the **short-haul** path only:

```
Local STM32  →  UART  →  Local ESP32  →  BLE  →  Tablet
(g_battery_pct)         (stores as local_batt_pct)
```

The local ESP32 therefore holds **two** battery values for the Tablet:

| Field | Source |
|---|---|
| `local_batt_pct` | Own STM32 `g_battery_pct` via intra-board UART |
| `remote_batt_pct` | Long-haul status beacon → own STM32 → intra-board UART |

Both are exposed as separate fields in the BLE GATT characteristic so the Tablet
can populate the Base and Rover battery slots in the status bar independently.

### Timing and fault tolerance

- Transmitted every 10 s in the inter-epoch gap (RTCM is 1 Hz; ≥900 ms of dead air available).
- Tablet status bar goes grey and shows `—` if 3 consecutive packets are missed (30 s timeout).
- A missed packet does not trigger any alert or retry.

---

## RTK Concepts

- **Code-phase** (consumer GPS): ~1-5m — noise floor cannot be corrected below ~1m
- **Carrier-phase** (RTK): mm measurement noise — resolves integer ambiguity for cm positions
- **RTK base position**: affects *absolute* accuracy only, not *relative* accuracy between points
  - Unknown base: cm relative accuracy, offset absolute position
  - Known base (benchmark / NTRIP): cm absolute accuracy in OS datum
- **NTRIP**: UK correction networks available (OS Net) for absolute coordinate accuracy

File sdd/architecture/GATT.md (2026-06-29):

# GATT Service Registry

All BLE services and characteristics used across the GPS Staff system.
Assign new UUIDs here first to avoid collisions.

---

## UUID Registry

| UUID | Assigned to |
|---|---|
| 0xAB00 | ~~RTCM Bridge Service~~ — retired; RTCM flows over GFSK (SX1262), not BLE |
| 0xAB01 | ~~RTCM Bridge — data characteristic~~ — retired |
| 0xAC00 | WiFi Provisioning Service |
| 0xAC01 | WiFi Provisioning — AP list characteristic |
| 0xAC02 | WiFi Provisioning — credential write characteristic |
| 0xAC03 | WiFi Provisioning — connection result characteristic |
| 0xAD00 | Base Telemetry Service |
| 0xAD01 | Base Telemetry — BASE_OPERATING_MODE characteristic |
| 0xAD02 | Base Telemetry — SURVEY_IN_STATUS characteristic |
| 0xAD03 | Base Telemetry — SURVEY_IN_COMMAND characteristic |
| 0xAD04 | Base Telemetry — SET_SURVEY_PARAMS characteristic |
| 0xAD05 | Base Telemetry — GNSS_SAT_DATA characteristic |
| 0xAD06 | Base Telemetry — GNSS_FIX_STATUS characteristic |
| 0xAD07 | Base Telemetry — RTCM_STREAM_STATUS characteristic |
| 0xAD08 | ~~ROVER_LINK_STATUS~~ — removed; Base is a pure broadcaster, rover status flows Base←→Handheld directly |
| 0xAD09 | Base Telemetry — RTCM_STREAM_COMMAND characteristic |
| 0xAD0A | Base Telemetry — GFSK_RADIO_CONFIG characteristic |
| 0xAE00 | *reserved — next service block* |

---

## Service Definitions

### 0xAC00 — WiFi Provisioning

**Purpose:** Base advertises visible WiFi APs to the Handheld; Handheld returns selected SSID + password.

| Role | Device | Firmware |
|---|---|---|
| Peripheral (GATT server) | ESP32-S3 Zero — base role | `firmware/esp32-base` (`wifi_prov.c`) |
| Central (GATT client) | ESP32-S3 4.3" Handheld | `firmware/esp32-handheld` (`ble_base_client.c`) |

> Refactor note: changes to this service require updates to both `wifi_prov.c` (peripheral) on the base and `ble_base_client.c` + `wifi_provision.c` (central + UI) on the handheld.

#### 0xAC01 — AP List (Base → Handheld)

Properties: **NOTIFY**

Sent every 3 seconds. An AP count of 0 means no networks were found.

```
Byte 0:     AP count (uint8_t)
Per AP (repeated count times):
  Byte:     ssid_len (uint8_t, 0–32)
  N bytes:  SSID (not null-terminated)
  Byte:     rssi (int8_t cast to uint8_t)
  Byte:     auth_mode (uint8_t, see Auth Mode Values below)
```

#### 0xAC02 — Credentials (Handheld → Base)

Properties: **WRITE** (confirmed)

Sent once when the user taps Connect. Empty password string = open network.

```
Byte 0:     ssid_len (uint8_t, 0–32)
N bytes:    SSID
Byte:       pwd_len (uint8_t, 0–64)
M bytes:    password
```

#### 0xAC03 — Connection Result (Base → Handheld)

Properties: **NOTIFY**

Sent once when a connection attempt completes (success or failure). Re-sent as a 3-second heartbeat while Base remains connected (allows Handheld to detect already-provisioned Base on connect).

```
Byte 0:     status
              0 = connected (success)
              1 = wrong password
              2 = network not found
              3 = connection timed out
              4 = other error
Bytes 1–33: SSID null-terminated (32 chars max + null; zero-filled if shorter)
Byte 34:    RSSI of connected AP (int8_t as uint8_t; 0 if status ≠ 0)
Bytes 35–38: IP address (uint32_t little-endian; 0.0.0.0 if status ≠ 0)
```

#### Auth Mode Values

Mirrors `wifi_auth_mode_t` from ESP-IDF. Defined as `PROV_AUTH_*` in `ble_base_client.h`.

| Value | Meaning |
|---|---|
| 0 | Open (no password) |
| 1 | WEP |
| 2 | WPA |
| 3 | WPA2 |
| 4 | WPA/WPA2 mixed |
| 5 | Enterprise |
| 6 | WPA3 |
| 7 | WPA2/WPA3 mixed |

---

---

## 0xAD00 — Base Telemetry Service

**Purpose:** Exposes live Base operating state, GNSS telemetry, and survey-in
control to the Handheld. All readable characteristics must be polled on every
fresh BLE connection (see Reconnect / State Discovery below).

| Role | Device | Firmware |
|---|---|---|
| Peripheral (GATT server) | ESP32-S3 Zero — base role | `firmware/esp32-base` |
| Central (GATT client) | ESP32-S3 Tablet / Handheld | `firmware/esp32-tablet` / `esp32-handheld` |

### State ownership

**All application state lives in the ESP32-S3-Zero — not the STM32.**

The STM32F765 is a smart pipe: it parses UBX frames from the F9P and forwards
condensed binary messages to the ESP32 over UART, and executes commands the ESP32
sends back (start/cancel SVIN, write UBX-CFG-TMODE3, enable LoRa TX). It has no
knowledge of BLE, GATT, or operating mode.

The ESP32 synthesises `BASE_OPERATING_MODE` from two inputs:
  1. F9P telemetry forwarded by the STM32 (SVIN active/valid, fix type, etc.)
  2. Its own command state (e.g. "I sent Start SVIN → mode = 0x01").

State is held in ESP32 RAM only. The STM32 and ESP32 share the same power supply;
if the Base is switched off, all state is lost and the system performs a clean start
on next power-on. No NVS persistence is required or expected.

---

### Reconnect / State Discovery

The HH ↔ Base BLE connection is **temporary and UI-driven** — it is established
when the user opens Base Config and dropped on exit. The tablet may also have been
powered off entirely. Either way, the tablet has no knowledge of what the Base has
been doing since the connection was last open.

**On every fresh connection, the tablet must:**
1. Read `BASE_OPERATING_MODE` (0xAD01) — single byte, immediate.
2. Navigate to the appropriate screen based on the value (see table below).
3. Subscribe to notifications for whichever characteristics the current screen needs.
4. Read those characteristics immediately after subscribing to get current values
   (do not wait for the first notify; it may take up to 1 s).

This sequence handles tablet power cycles, normal UI re-entry, and long gaps between
Base Config visits identically — no special "reconnect" code path is needed.

**Do NOT** infer Base state by combining multiple characteristics and applying logic.
`BASE_OPERATING_MODE` is the single source of truth; the Base STM32/ESP32 owns it.

---

### 0xAD01 — BASE_OPERATING_MODE

Properties: **READ + NOTIFY** (notify on mode transition)

Single byte. Owned and updated by the Base ESP32 application layer. The ESP32
synthesises the value from F9P telemetry forwarded by the STM32 (SVIN active/valid,
fix type) combined with its own command state (e.g. "I sent Start SVIN"). The STM32
has no knowledge of this characteristic.

```
0x00  Idle            No active mode, no valid position held.
                      → BaseConfig-0: all cards enabled, position banner = None
0x01  Survey-in active  F9P SVIN running.
                      → Navigate to BaseConfig-SurveyIn.html, State B (in progress)
                      → BaseConfig-0: RTCM Data card disabled
0x02  Survey-in complete  Valid surveyed position held (SVIN valid=1).
                      → Navigate to BaseConfig-SurveyIn.html, State C (complete)
                      → BaseConfig-0: position banner = Survey-in, RTCM Data enabled
0x03  Fixed position set  Monument/benchmark coordinates stored.
                      → BaseConfig-0: position banner = Monument, RTCM Data enabled
0x04  RTCM streaming active  Base is broadcasting corrections over LoRa.
                      → BaseConfig-0: RTCM Data card highlighted / active
0xFF  Initialising    STM32 not yet reported mode (ESP32 just booted).
                      → Show spinner; retry read after 2 s
```

---

### 0xAD02 — SURVEY_IN_STATUS

Properties: **READ + NOTIFY** (1 Hz while active; last value readable at any time)

```
Byte  0     active   uint8   1 = survey-in currently running on F9P
Byte  1     valid    uint8   1 = survey-in complete (both conditions met)
Bytes 2–5   dur      uint32  elapsed duration, seconds (little-endian)
Bytes 6–9   obs      uint32  position observations accumulated
Bytes 10–13 meanAcc  uint32  current mean position accuracy, mm
Bytes 14–15 minDur   uint16  configured target duration, seconds
Bytes 16–19 minAcc   uint32  configured target accuracy, mm
```

**minDur and minAcc must be included** so a freshly-connected tablet can display
the correct targets without a separate parameter read. The STM32 echoes the values
it last wrote to the F9P via UBX-CFG-VALSET.

Source: UBX-NAV-SVIN from Base F9P, parsed by Base STM32, forwarded over UART to ESP32.

---

### 0xAD03 — SURVEY_IN_COMMAND

Properties: **WRITE NO RESPONSE**

```
0x01  Start   Begin survey-in with parameters from SET_SURVEY_PARAMS (0xAD04).
              STM32 writes UBX-CFG-VALSET to F9P then enables TMODE3.
              Ignored if active=1 already.
0x02  Cancel  Stop survey-in. STM32 sends UBX-CFG-TMODE3 mode=0 to F9P.
              BASE_OPERATING_MODE transitions to 0x00 (Idle) or 0x02 if valid.
```

---

### 0xAD04 — SET_SURVEY_PARAMS

Properties: **WRITE NO RESPONSE** (send before SURVEY_IN_COMMAND 0x01)

```
Bytes 0–1   minDur   uint16  target duration, seconds (180–600 recommended)
Bytes 2–5   minAcc   uint32  target accuracy, mm (e.g. 3000 = 3.0 m)
```

---

### 0xAD05 — GNSS_SAT_DATA

Properties: **NOTIFY** (1 Hz; not readable — too large, always from latest notify)

One record per tracked satellite (up to 20). Each record is 7 bytes:

```
Byte 0   gnssId    uint8   0=GPS, 6=GLONASS
Byte 1   svId      uint8   satellite number within constellation
Byte 2   elev      uint8   elevation, degrees (0–90)
Bytes 3–4 azim     uint16  azimuth, degrees (0–359, little-endian)
Byte 5   cno       uint8   carrier-to-noise, dBHz (0–50 typical)
Byte 6   flags     uint8   bit 0 = usedInFix
```

Source: UBX-NAV-SAT from Base F9P. F9P must have NAV-SAT enabled at 1 Hz.

---

### 0xAD06 — GNSS_FIX_STATUS

Properties: **READ + NOTIFY** (1 Hz)

```
Byte  0     fixType   uint8   0=no fix, 3=3D, 4=GNSS+DR, 5=Time only
Byte  1     carrSoln  uint8   0=none, 1=RTK float, 2=RTK fixed
Byte  2     numSV     uint8   satellites used in fix
Bytes 3–4   pDOP      uint16  pDOP × 100 (little-endian)
Bytes 5–6   hDOP      uint16  hDOP × 100
Bytes 7–10  iTOW      uint32  GPS time of week, ms
```

RTK float = fixType≥3 + carrSoln=1. RTK fixed = fixType≥3 + carrSoln=2.
Source: UBX-NAV-PVT from Base F9P.

---

### 0xAD07 — RTCM_STREAM_STATUS

Properties: **READ + NOTIFY** (1 Hz while streaming; single READ returns current snapshot)

```
Byte  0     streaming   uint8   1 = actively broadcasting over LoRa; 0 = idle
Byte  1     msg_mask    uint8   bit 0 = RTCM 1005 seen in last 2 s
                                bit 1 = RTCM 1074 seen in last 2 s
                                bit 2 = RTCM 1084 seen in last 2 s
Bytes 2–3   byte_rate   uint16  bytes/sec forwarded to LoRa (5 s rolling average)
Byte  4     pkt_rate    uint8   RTCM packets/sec (5 s rolling average)
Byte  5     _pad        uint8   reserved, 0
Bytes 6–9   total_pkts  uint32  total packets forwarded since Base boot (little-endian)
Bytes 10–13 total_bytes uint32  total bytes forwarded since Base boot (little-endian)
```

Source: Base STM32 counters (RTCM framer / LoRa TX path), forwarded to ESP32 over UART.
Session counters reset on power cycle (not persisted).

---

### 0xAD08 — ~~ROVER_LINK_STATUS~~ (removed)

Removed: the Base is a pure GFSK broadcaster with no concept of connected rovers —
there may be zero, one, or many, or the receiver may be an NTRIP caster rather than
a rover. Rover status (fix quality, RSSI, battery) flows directly between the Rover
ESP32 and the Handheld over BLE; it does not route through the Base.

---

### 0xAD09 — RTCM_STREAM_COMMAND

Properties: **WRITE NO RESPONSE**

```
0x01  Stop streaming    BASE_OPERATING_MODE → 0x02 (position held, not streaming).
                        STM32 stops forwarding RTCM packets to LoRa TX.
0x02  Resume streaming  BASE_OPERATING_MODE → 0x04. Valid only if mode was 0x02.
                        Ignored if no valid position is held.
```

---

### 0xAD0A — GFSK_RADIO_CONFIG

Properties: **READ + WRITE** (no notify — config changes are infrequent)

Same 18-byte layout for both READ response and WRITE command.
On WRITE, STM32 reconfigures SX1262 immediately and persists to STM32 flash.
Tablet confirms the write by issuing a READ after ~200 ms and updating the display.

```
Bytes  0–3   freq_hz    uint32   carrier frequency, Hz (e.g. 434000000 = 434.000 MHz)
Byte   4     tx_power   int8     TX power, dBm. UI presents 6 fixed levels:
                                 −17 (min/test), 0 (1 mW, default), +10 (10 mW),
                                 +14 (25 mW), +17 (50 mW), +22 (158 mW, max batt drain).
                                 Wire value is raw dBm int8; SX1262 PA_CONFIG limits apply.
Bytes  5–8   bit_rate   uint32   GFSK bit rate, bps (e.g. 9600)
Bytes  9–12  sync_word  uint32   sync word, big-endian
                                 e.g. 0x00906F26 for the 3-byte word 0x906F26
                                 Base and Rover must share the same value.
Bytes 13–14  freq_dev   uint16   frequency deviation, Hz (READ only; STM32 calculates
                                 as bit_rate / 2 for BT=0.5 Gaussian, modulation index β=1.0;
                                 ignored on WRITE)
Bytes 15–18  rx_bw      uint32   SX1262 RX bandwidth, Hz (READ only; STM32 selects the
                                 nearest available step above 2×freq_dev + bit_rate;
                                 ignored on WRITE)
```

**GFSK collision note:** The F9P outputs RTCM on the GPS timepulse (~1 Hz, UTC-aligned).
Two nearby base stations therefore transmit simultaneously with GPS-clock precision,
causing repeated RF collisions regardless of sync word. Sync word prevents a rover
accepting packets from the wrong base; it does not prevent the RF collision itself.
Mitigation: assign different frequencies to co-located bases.
LoRa spread-spectrum would be more collision-tolerant; GFSK is used here for duty-cycle
efficiency (7–8× less airtime, critical under ETSI EN 300 220 10% limit on 433/434 MHz).

---

## Planned Services (not yet assigned)

| Proposed service | Peripheral | Central | Connection lifetime | Notes |
|---|---|---|---|---|
| Rover status + Base battery relay | ESP32 Rover | Handheld | Permanent (always in proximity) | Position fix, RTCM lock, rover battery; Base battery % piggybacked after arriving over GFSK from Base → Rover STM32 → Rover ESP32 → BLE → HH. RTCM flowing = Base operational; battery is the only health data RTCM doesn't carry |
| Base Config channel | ESP32 Base | Handheld | Temporary — HH connects on entering Base Config UI, drops on exit | WiFi provisioning (0xAC00 already exists), future config commands; user must be in proximity by definition |

### Connection lifetime notes

- **HH ↔ Rover**: permanent connection while HH is powered. Rover is always in the user's hand/pocket.
- **HH ↔ Base**: temporary, UI-driven. `ble_base_client.c` must suppress auto-rescan outside of Base Config screen — reconnect is always initiated by the user entering that UI section, never automatic.
- **Base battery in the field**: Base battery % flows Base STM32 → GFSK → Rover STM32 → Rover ESP32 → BLE → HH. RTCM flowing already confirms Base is alive; battery % is the only additional data needed.

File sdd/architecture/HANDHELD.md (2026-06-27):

# Handheld Unit — Implemented Capabilities

Covers `firmware/esp32-handheld`.

> BLE services: see [GATT.md](GATT.md) for UUIDs, wire formats, and peripheral/central roles.

---

## ESP32-S3 4.3" Touch Display (firmware/esp32-handheld)

| Capability | Status | Notes |
|---|---|---|
| RGB LCD display | Done PR #190 | 800×480, portrait via LVGL 270° rotation, 480×800 in software |
| GT911 touch | Done PR #191 | I2C GPIO8/9, addr 0x5D, bench verified |
| LVGL 8.4 stack | Done PR #190 | Tear-avoidance mode 3, core 1, lvgl_port_lock/unlock |
| Widget pattern | Done PR #199 | One widget per .c/.h, state in struct, timer context via user_data |
| Battery indicator widget | Done PR #199 | Charging animation, LV_SYMBOL_CHARGE bolt, batt_indicator.c/h |
| WiFi scanner widget | Done PR #200 | AP list sorted by RSSI, channel + auth type, 15s scan cycle (sandbox only — not in main build) |
| Partition table (1.5MB app) | Done PR #200 | SINGLE_APP_LARGE — sufficient for NimBLE + LVGL (792KB) |
| VS Code IntelliSense | Done PR #197 | c_cpp_properties.json → build/compile_commands.json |
| NimBLE central (BLE client) | Done PR #209 | Scans for GPS-Base, subscribes to 0xAC01 AP list, writes creds to 0xAC02 |
| WiFi provisioning UI | Done PR #209 | AP list from Base, password entry via LVGL keyboard, credential send; bench-verified |
| Connection result UI | Done PR #215 | Subscribes to 0xAC03; success shows green SSID+RSSI+IP; failure shows red reason + restores AP list |
| Home screen | Done PR #218 | GPS-Staff logo (400×600 RGB565, centred on white background), "Base" and "Rover" buttons at bottom; permanent start screen |
| Base Config menu | Done PR #218 | Dark header bar + back-to-home navigation; "WiFi Settings" (active), "Survey-in Settings" and "Fix Selection" (greyed stubs, TBD) |
| Panel navigation | Done PR #218 | Panel-based: home → base_config → wifi_provision; batt indicator created last, floats above all panels; BLE background callbacks no longer force wifi_provision visible |

---

## Pending / In Spec

| Feature | Spec |
|---|---|
| BLE connection to Rover (position/status display) | Future spec |
| BLE command/config channel to Rover | Future spec |
| Survey-in Settings screen | Awaiting F9P delivery |
| Fix Selection screen | Awaiting F9P delivery |
| Main survey UI screens | Pending UI design |

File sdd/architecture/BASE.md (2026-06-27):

# Base Unit — Implemented Capabilities

Covers both `firmware/esp32-base` (base role) and `firmware/Nucleo-F767ZI-FreeRTOS` / `firmware/rtk-base` (STM32 base role).

> BLE services: see [GATT.md](GATT.md) for UUIDs, wire formats, and peripheral/central roles.

---

## ESP32-S3 Zero (firmware/esp32-base)

| Capability | Status | Notes |
|---|---|---|
| Role selection at boot | Done | GP1 open = base, GP1 GND = rover; 500ms timeout then direct GPIO read |
| BLE peripheral (GPS-Base) | Done PR #216 | Advertises "GPS-Base"; GAP connect/disconnect hooks wifi_prov; RTCM bridge removed — RTCM flows over GFSK |
| WiFi scan + BLE advertise (unprovisioned) | Done PR #206 | GATT svc 0xAC00 chr 0xAC01 NOTIFY; AP list every 3s sorted by RSSI; empty list when no APs found |
| Credential receive from HH | Done PR #209 | 0xAC02 WRITE; decodes SSID+password |
| WiFi connect + NVS storage | Done PR #215 | State machine: SCANNING→CONNECTING→CONNECTED; credentials in NVS namespace wifi_prov; reconnects on boot |
| Connection result notify | Done PR #215 | 0xAC03 NOTIFY; one-shot result + 3s heartbeat when connected; SSID+RSSI+IP on success |

## STM32 (firmware/Nucleo-F767ZI-FreeRTOS / rtk-base)

| Capability | Status | Notes |
|---|---|---|
| FreeRTOS scaffold | Done | app_init/app_loop/app_1ms hooks, flags.c IRQ bridge |
| SSD1309 OLED display | Done | Queue-driven task_display.c; clear/string/flush API; I2C1 mutex-protected |
| SX1262 GFSK TX | Done | Interrupt-driven DIO1, active bench mode |
| RTCM3 framing + OTA | Done | RTCM3_BUF_COUNT=4; bump to 8 before adding display driver |
| FatFS SD card | Done | F767ZI bench-proven; FF_FS_NORTC set — needs GPS UTC when F9P arrives |
| LSM6DSOX IMU driver | Done PR #124 | I2C1 on F446RE bench |

---

## Pending / In Spec

| Feature | Spec |
|---|---|
| NTRIP RTCM streaming over WiFi | Future spec |
| PE2/PE3 mode-select GPIO (PCB) | Awaiting PCB delivery |
| ZED-F9P UART driver | Awaiting F9P delivery |

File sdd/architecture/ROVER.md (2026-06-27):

# Rover Unit — Implemented Capabilities

Covers both `firmware/esp32-base` (rover role) and `firmware/rtk-rover` (STM32 rover role).

> BLE services: see [GATT.md](GATT.md) for UUIDs, wire formats, and peripheral/central roles.

---

## ESP32-S3 Zero (firmware/esp32-base — rover role)

| Capability | Status | Notes |
|---|---|---|
| Role selection at boot | Done | GP1 GND = rover; same binary as base |
| BLE role | Pending | BLE central to Handheld (status/position stream) — future spec; RTCM bridge over BLE removed, RTCM flows over GFSK |

## STM32 (firmware/rtk-rover)

| Capability | Status | Notes |
|---|---|---|
| FreeRTOS scaffold | Done | Mirrors rtk-base structure |
| SX1262 GFSK RX | Done | Interrupt-driven DIO1 |
| RTCM3 receive + framing | Done | |
| SSD1309 OLED display | Done | Status display, I2C |

---

## Pending / In Spec

| Feature | Spec |
|---|---|
| BLE link to Handheld (position/status stream) | Future spec |
| BLE link to Handheld (command/config channel) | Future spec |
| ZED-F9P UART driver + RTCM feed | Awaiting F9P delivery |
| MMC5603NJ magnetometer driver | Needed (LIS3MDL discontinued) |
| Tilt fusion / soft-iron calibration | Deferred |

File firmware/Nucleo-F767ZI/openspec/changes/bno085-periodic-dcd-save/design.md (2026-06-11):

## Context

`bno085_send_command()` already builds and sends the generic 12-byte SH-2
Command Request (0xF2) payload `{0xF2, cmd_seq, command, P0..P8}` on
`BNO085_CHANNEL_CONTROL`. `bno085_save_dcd()` and
`bno085_set_me_calibration()` both follow the pattern: send the command,
then call `bno085_read_command_response()` to wait for and parse the
matching Command Response (0xF1).

Per SH-2 Reference Manual section 6.4.7, Configure Periodic DCD Save
(0x09) is different: "There is no response to this command." The command
takes a single parameter byte P0 (`0x00` = enable, `0x01` = disable
periodic DCD save); P1..P8 are reserved.

## Goals / Non-Goals

**Goals:**
- Provide `bno085_set_periodic_dcd_save()` to enable/disable periodic DCD
  save, following the existing `bno085_send_command()` pattern.
- Enable periodic DCD save at startup in `app_init()`, alongside the
  existing ME calibration enable, as part of the forum-suggested
  calibration recipe.

**Non-Goals:**
- Not attempting the "Simple Calibration" (turntable, 0x0C) command in
  this change - that requires a structured 180-degree motion sequence
  that's impractical with the current breadboard bench setup.
- Not adding a way to read back whether periodic DCD save is enabled
  (the SH-2 manual gives no response/query for this command).

## Decisions

- **No response read**: unlike `bno085_save_dcd()` and
  `bno085_set_me_calibration()`, `bno085_set_periodic_dcd_save()` does
  not call `bno085_read_command_response()` - per the manual, the device
  sends nothing back. The function returns as soon as
  `bno085_send_command()` succeeds.
- **Function signature**: `bno085_set_periodic_dcd_save(bno085_t *p,
  uint8_t enable)` mirrors `bno085_set_me_calibration()`'s style of
  taking plain enable flags. `enable` is mapped to P0 as `enable ? 0x00 :
  0x01` (note the inverted sense vs. a typical "1 = on" flag, matching
  the SH-2 command encoding directly, documented in the Doxygen comment).
- **Wiring**: `app_init()` calls `bno085_set_periodic_dcd_save(&bno, 1)`
  right after the existing `bno085_set_me_calibration()` call, printing
  `bno085_set_periodic_dcd_save OK` or the failure status over USART3,
  matching the style of the other `app_init()` feature-enable blocks.

## Risks / Trade-offs

- [No response means a failed/ignored command is indistinguishable from
  success at the protocol level] -> Mitigation: `bno085_send_command()`'s
  return value still confirms the SPI transfer succeeded; deeper
  verification (e.g. confirming calibration data was actually persisted)
  is out of scope and would require power-cycling and re-checking
  `bno085_get_me_calibration()` status, which can be a manual bench step.
- [This may not resolve the underlying stuck `status=0` issue] ->
  Mitigation: this is an incremental diagnostic step per the forum
  recipe; if it doesn't help, the finding will be documented (as with
  prior changes) and further options (e.g. Simple Calibration 0x0C)
  considered separately.

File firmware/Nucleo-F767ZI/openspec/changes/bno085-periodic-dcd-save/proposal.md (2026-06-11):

## Why

The bno085-magnetic-field-report change confirmed that both the Rotation
Vector's and Magnetic Field Calibrated report's `status` fields remain
stuck at `0` (Unreliable), despite plausible sensor readings and motion,
with ME calibration enabled via `bno085_set_me_calibration()`. Community
research (Adafruit BNO085 forum thread on calibration/performance) points
to ME calibration enable plus Configure Periodic DCD Save (0x09) together
as a working recipe for getting the calibration accuracy/status classifier
to progress. We want to add the periodic DCD save command as the next
diagnostic step.

## What Changes

- Add `BNO085_COMMAND_DCD_PERIODIC_SAVE` (`0x09`) constant to `bno085.h`.
- Add `bno085_set_periodic_dcd_save(bno085_t *p, uint8_t enable)` to
  `bno085.c`, sending a Configure Periodic DCD Save command via
  `bno085_send_command()`. Per SH-2 Reference Manual section 6.4.7, this
  command has **no response** - `bno085_read_command_response()` is not
  called.
- Wire a call enabling periodic DCD save (`enable=1`) into `app_init()`,
  alongside the existing ME calibration enable call, printing the send
  result over USART3.

## Capabilities

### New Capabilities
- `bno085-periodic-dcd-save`: enabling the SH-2 Configure Periodic DCD
  Save (0x09) command to automatically persist dynamic calibration data.

### Modified Capabilities
(none)

## Impact

- `Core/Inc/bno085.h`: new constant and function declaration.
- `Core/Src/bno085.c`: new `bno085_set_periodic_dcd_save()` function.
- `Core/Src/app.c`: `app_init()` enables periodic DCD save at startup.

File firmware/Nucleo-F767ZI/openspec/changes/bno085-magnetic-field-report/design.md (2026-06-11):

## Context

The driver already implements the same pattern for the Rotation Vector
(0x05) report (`bno085-rotation-vector-report`):
`bno085_set_feature()` enables a report at a given interval,
`bno085_read_rotation_vector()` reads input reports via
`bno085_read_response()` and matches on a Base Timestamp Reference
(0xFB, §7.2.1, 5 bytes) followed by the Rotation Vector report (0x05),
and `bno085_print_rotation_vector()` prints the parsed fields using the
fixed-point `bno085_format_q()` helper (newlib-nano lacks `%f`
support).

The Magnetic Field Calibrated (0x03) input report (§6.5.16.2) has the
same shape: `{Report ID, sequence, status, delay, X LSB/MSB, Y LSB/MSB,
Z LSB/MSB}` - 10 bytes, Q point 4, units uTesla. Preceded by the same
5-byte Base Timestamp Reference, the full SHTP packet is `4 (header) +
5 (base timestamp) + 10 (mag field) = 19` bytes, with the report ID
byte at `cmd_buf[9] == 0x03`.

## Goals / Non-Goals

**Goals:**
- Enable and read the Magnetic Field Calibrated report alongside the
  existing Rotation Vector report, using the same driver patterns.
- Print field magnitude (x/y/z in uT) and `status` so it can be
  compared against the phone-magnetometer baseline (~25-65 uT, "High"
  accuracy) and against the Rotation Vector's `status`/`accuracy`.

**Non-Goals:**
- No new SH-2 command plumbing - this reuses
  `bno085_set_feature()`/`bno085_read_response()` exactly as-is.
- No automatic interpretation/diagnosis in firmware (e.g. flagging
  "interference detected") - this is a manual bench diagnostic, the
  human reads the printed values.
- Magnetic Field Uncalibrated (0x0F) is out of scope.

## Decisions

- **Mirror the Rotation Vector struct/function shapes exactly**: add
  `bno085_magnetic_field_t` (`sequence`, `status`, `x`/`y`/`z` as
  `int16_t`, plus `x_f`/`y_f`/`z_f` floats) and a `magnetic_field`
  field on `bno085_t`, matching `bno085_rotation_vector_t`'s layout and
  naming conventions.
- **Reuse `bno085_format_q()`** for printing x/y/z (Q point 4) - no new
  formatting helper needed.
- **Single combined Q point constant** `BNO085_MAGNETIC_FIELD_Q_POINT`
  (4), matching the naming of `BNO085_ROTATION_VECTOR_Q_POINT`.
- **Separate `bno085_set_feature()` call** for report ID 0x03 in
  `app_init()`, same 50000us (20Hz) interval as Rotation Vector, added
  immediately after the existing Rotation Vector Set Feature call.
- **Print format**: `mag: x=<uT> y=<uT> z=<uT> seq=<n> status=<0-3>\r\n`,
  matching the `rv: ...` line's style, printed directly after the `rv:`
  line in `app_loop()`.

## Risks / Trade-offs

- [Risk] Enabling a second 20Hz report doubles the SPI/INT traffic the
  driver must service in `app_loop()`, which already reads Rotation
  Vector every iteration → Mitigation: both reads happen in the same
  500ms loop iteration as before; if INT/SPI throughput becomes an
  issue this would surface as `HAL_ERROR`/`HAL_TIMEOUT` returns, which
  are already handled by skipping the print for that iteration.
- [Risk] The diagnostic may show the magnetometer itself is fine
  (status reaching 2/3, plausible field magnitude) while Rotation
  Vector's status/accuracy remains stuck - in which case the root cause
  lies elsewhere (e.g. accel/gyro calibration, or a fusion-level issue)
  → Mitigation: this change's purpose is exactly to narrow down which
  case applies; either outcome is a useful result and will inform the
  next follow-up.

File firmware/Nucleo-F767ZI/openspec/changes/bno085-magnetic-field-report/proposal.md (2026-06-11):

## Why

The `bno085-me-calibration` change enabled accel/gyro/mag dynamic
calibration and confirmed (via `bno085_get_me_calibration()`) that the
enables persist on-chip. Despite this, and despite ~1 minute of varied
3D motion on the bench, the Rotation Vector (0x05) report's `status`
and `accuracy` fields stayed pinned at `0` ("Unreliable") and `pi`
radians (the worst-case/default value) throughout - never fluctuating
even briefly, which is more "stuck" than reports of bad setups in the
community (where `status` is typically observed to fluctuate between
0-3 with motion).

A community thread (Adafruit forums, "BNO085 calibration and
performance") repeatedly points to the magnetometer as the limiting
factor for Rotation Vector accuracy, and recommends independently
reading the Magnetic Field Calibrated (0x03) report - both its field
magnitude (Earth's field is ~25-65 uT) and its own `status` byte - to
diagnose whether the issue is magnetometer-specific (e.g. local
magnetic interference from nearby ferrous/metal components) versus a
broader fusion/calibration problem.

This change adds that diagnostic: reading and printing the Magnetic
Field Calibrated report alongside the existing Rotation Vector output,
so the two can be compared directly on the bench.

## What Changes

- Enable the Magnetic Field Calibrated (0x03) report via the existing
  `bno085_set_feature()` in `app_init()`, at the same 20 Hz interval
  used for Rotation Vector.
- Add `bno085_read_magnetic_field()`: reads an SH-2 Magnetic Field
  Calibrated (0x03) input report (preceded by a Base Timestamp
  Reference, as with Rotation Vector) and parses `status` and the
  x/y/z field components (Q point 4, units uT) into a new
  `bno085_magnetic_field_t` struct on `bno085_t`.
- Add `bno085_print_magnetic_field()`: prints the parsed status and
  x/y/z field values (in uT, to 4 decimal places using the existing
  `bno085_format_q()`-style fixed-point formatting) over USART3.
- Wire `bno085_read_magnetic_field()` /
  `bno085_print_magnetic_field()` into `app_loop()` alongside the
  existing Rotation Vector read/print.

## Capabilities

### New Capabilities
- `bno085-magnetic-field-report`: enabling, reading, and printing the
  SH-2 Magnetic Field Calibrated (0x03) input report.

### Modified Capabilities
- (none)

## Impact

- `Core/Inc/bno085.h` / `Core/Src/bno085.c`: new
  `BNO085_REPORT_ID_MAGNETIC_FIELD` constant, new
  `bno085_magnetic_field_t` struct and `magnetic_field` field on
  `bno085_t`, new `bno085_read_magnetic_field()` and
  `bno085_print_magnetic_field()` functions.
- `Core/Src/app.c`: `app_init()` enables the Magnetic Field Calibrated
  report; `app_loop()` reads and prints it alongside Rotation Vector.

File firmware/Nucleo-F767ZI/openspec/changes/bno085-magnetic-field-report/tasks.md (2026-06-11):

## 1. Constants and struct fields

- [x] 1.1 Add `BNO085_REPORT_ID_MAGNETIC_FIELD` (`0x03`) and
      `BNO085_MAGNETIC_FIELD_Q_POINT` (`4`) constants to `bno085.h`.
- [x] 1.2 Add `bno085_magnetic_field_t` struct (`sequence`, `status`,
      `x`/`y`/`z` as `int16_t`, `x_f`/`y_f`/`z_f` as `float`) and a
      `magnetic_field` field on `bno085_t` to `bno085.h`.

## 2. Read and print

- [x] 2.1 Implement `bno085_read_magnetic_field()` in `bno085.c`,
      mirroring `bno085_read_rotation_vector()`'s structure: loop
      `bno085_read_response()`, match on `cmd_len >= 19`,
      `cmd_buf[4] == BNO085_REPORT_ID_BASE_TIMESTAMP`, `cmd_buf[9] ==
      BNO085_REPORT_ID_MAGNETIC_FIELD`, then parse `cmd_buf[10..19)`.
- [x] 2.2 Implement `bno085_print_magnetic_field()` in `bno085.c`,
      mirroring `bno085_print_rotation_vector()` and reusing
      `bno085_format_q()`.
- [x] 2.3 Document both functions in `bno085.h` following the existing
      Doxygen-style comment conventions.

## 3. Wire-up and review

- [x] 3.1 In `Core/Src/app.c`'s `app_init()`, after the existing
      Rotation Vector `bno085_set_feature()` call, add a
      `bno085_set_feature()` call enabling report `0x03` at the same
      50000us interval, and print its result.
- [x] 3.2 In `Core/Src/app.c`'s `app_loop()`, call
      `bno085_read_magnetic_field()` and, on `HAL_OK`, call
      `bno085_print_magnetic_field()` alongside the existing Rotation
      Vector read/print.
- [x] 3.3 Bench-test on hardware: verify `mag: x=... y=... z=...
      seq=... status=...` lines are printed, that the field magnitude
      is plausible (~25-65 uT for Earth's field, comparable to the
      phone-magnetometer baseline), and observe whether `status`
      changes with motion (compare against the Rotation Vector's
      `status`/`acc`, which remained stuck at `0`/`pi`).

      Result: `mag:` lines print correctly; field magnitude settled
      around ~40-45uT (e.g. x=-41.6 y=1.8 z=-15.8), consistent with
      Earth's field and the phone-magnetometer baseline (~45-50uT).
      However `mag: status` is also stuck at `0`, exactly mirroring
      `rv: status`. Cross-checked our byte offsets/Q points and the
      ME calibration enable call against Adafruit's
      `sh2_SensorValue.c`/`sh2.c` (Adafruit_BNO08x library) — both
      match exactly, so this isn't a driver bug. Since the readings
      themselves are physically plausible, the stuck status=0 looks
      like a calibration-confidence-classifier issue rather than bad
      magnetometer data; left as a further follow-up investigation.

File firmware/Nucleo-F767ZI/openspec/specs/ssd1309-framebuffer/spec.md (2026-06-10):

## Purpose

SSD1309 OLED panel framebuffer, drawing primitives, and text rendering for
the Nucleo-F767ZI sandbox: a 1bpp RAM framebuffer mirroring the panel's
GDDRAM layout, pixel-level set/get and clear/fill operations, a dirty-flag
flush to push the framebuffer to the panel over I2C, and multi-font
monospace text rendering.

## Requirements

### Requirement: Framebuffer storage
The driver SHALL provide a 1bpp RAM framebuffer within `ssd1309_t`, organized
in the same page-major layout as SSD1309 GDDRAM (one byte per 8 vertical
pixels of a single column, bit 0 = top row of the page), sized to support
panels up to 128x64.

#### Scenario: Buffer sized for the configured panel
- **WHEN** a handle is initialized via `ssd1309_init()` with `height` and
  `width`
- **THEN** the driver uses the first `width * (height / 8)` bytes of the
  framebuffer for all drawing/flush operations on that handle

### Requirement: Clear and fill
The driver SHALL provide `ssd1309_clear()` to set every pixel in the
framebuffer to off, and `ssd1309_fill()` to set every pixel to a given
on/off color. Both operations SHALL mark the framebuffer dirty
unconditionally.

#### Scenario: Clear sets all pixels off
- **WHEN** `ssd1309_clear(p)` is called
- **THEN** `ssd1309_get_pixel(p, x, y)` returns "off" for every `x`, `y`
  within the panel bounds
- **AND** the framebuffer is marked dirty

#### Scenario: Fill sets all pixels to a color
- **WHEN** `ssd1309_fill(p, color)` is called with color "on"
- **THEN** `ssd1309_get_pixel(p, x, y)` returns "on" for every `x`, `y`
  within the panel bounds
- **AND** the framebuffer is marked dirty

### Requirement: Pixel set/get
The driver SHALL provide `ssd1309_set_pixel(p, x, y, color)` to set or clear
a single framebuffer pixel, and `ssd1309_get_pixel(p, x, y)` to read it back.
Coordinates outside the panel's `width`/`height` SHALL be silently ignored
(for `set_pixel`) or treated as off (for `get_pixel`), without modifying
out-of-bounds memory or returning garbage. `ssd1309_set_pixel()` SHALL mark
the framebuffer dirty only when it actually changes a pixel's value.

#### Scenario: Set and read back an in-bounds pixel
- **WHEN** `ssd1309_set_pixel(p, x, y, on)` is called with `0 <= x < width`
  and `0 <= y < height`
- **THEN** a subsequent `ssd1309_get_pixel(p, x, y)` returns "on"

#### Scenario: Setting a pixel to a new value marks the framebuffer dirty
- **WHEN** `ssd1309_set_pixel(p, x, y, color)` is called with an in-bounds
  `x`, `y` whose current value differs from `color`
- **THEN** the pixel's value is updated
- **AND** the framebuffer is marked dirty

#### Scenario: Setting a pixel to its current value does not mark dirty
- **WHEN** `ssd1309_set_pixel(p, x, y, color)` is called with an in-bounds
  `x`, `y` whose current value already equals `color`, and the framebuffer
  is not already dirty
- **THEN** the framebuffer remains not dirty

#### Scenario: Out-of-bounds set is a no-op
- **WHEN** `ssd1309_set_pixel(p, x, y, on)` is called with `x >= width` or
  `y >= height`
- **THEN** the framebuffer contents are unchanged
- **AND** the dirty state is unchanged

#### Scenario: Out-of-bounds get returns off
- **WHEN** `ssd1309_get_pixel(p, x, y)` is called with `x >= width` or
  `y >= height`
- **THEN** the function returns "off" without reading out-of-bounds memory

### Requirement: Flush framebuffer to panel
The driver SHALL provide `ssd1309_flush(p)`, which writes the entire
framebuffer to GDDRAM via page-addressing mode (one I2C data write per page,
preceded by a column-address-reset command write per page), using the
handle's stored I2C peripheral and 7-bit address, but only when the
framebuffer is marked dirty. `ssd1309_flush()` SHALL be callable any number
of times after `ssd1309_bringup()` has completed successfully.

#### Scenario: Flush is a no-op when not dirty
- **WHEN** `ssd1309_flush(p)` is called and the framebuffer is not marked
  dirty
- **THEN** no I2C transfers are performed
- **AND** the function returns `HAL_OK`

#### Scenario: Successful flush returns HAL_OK and clears dirty
- **WHEN** `ssd1309_flush(p)` is called while the framebuffer is marked
  dirty, after `ssd1309_bringup(p)` has returned `HAL_OK`, and the panel
  acknowledges all I2C transfers
- **THEN** for each page (0 to `height/8 - 1`) the driver resets the column
  address to 0 and writes that page's `width` framebuffer bytes to GDDRAM
  with the I2C data control byte (`0x40`)
- **AND** returns `HAL_OK`
- **AND** the framebuffer is no longer marked dirty

#### Scenario: I2C failure during flush is propagated and dirty remains set
- **WHEN** any I2C transfer during `ssd1309_flush(p)` fails (NACK, bus
  error, or timeout) while the framebuffer is marked dirty
- **THEN** `ssd1309_flush(p)` returns the corresponding non-`HAL_OK`
  `HAL_StatusTypeDef` from the failing `HAL_I2C_*` call without sending
  further pages
- **AND** the framebuffer remains marked dirty

### Requirement: Line drawing
The driver SHALL provide
`ssd1309_draw_line(p, x0, y0, x1, y1, color)` to draw a 1px-wide line
between `(x0, y0)` and `(x1, y1)` inclusive, using Bresenham's algorithm and
`ssd1309_set_pixel()` for each point along the line (so out-of-bounds points
are clipped per `ssd1309_set_pixel()` semantics).

#### Scenario: Draw a horizontal line
- **WHEN** `ssd1309_draw_line(p, 10, 5, 20, 5, on)` is called
- **THEN** `ssd1309_get_pixel(p, x, 5)` returns "on" for every `x` from 10 to
  20 inclusive

#### Scenario: Draw a vertical line
- **WHEN** `ssd1309_draw_line(p, 10, 5, 10, 15, on)` is called
- **THEN** `ssd1309_get_pixel(p, 10, y)` returns "on" for every `y` from 5 to
  15 inclusive

#### Scenario: Draw a diagonal line
- **WHEN** `ssd1309_draw_line(p, 0, 0, 5, 5, on)` is called
- **THEN** `ssd1309_get_pixel(p, n, n)` returns "on" for every `n` from 0 to
  5 inclusive

#### Scenario: Draw a line in either direction
- **WHEN** `ssd1309_draw_line(p, 20, 5, 10, 5, on)` is called (endpoints
  reversed relative to the horizontal-line scenario)
- **THEN** `ssd1309_get_pixel(p, x, 5)` returns "on" for every `x` from 10 to
  20 inclusive

#### Scenario: Draw a single-point line
- **WHEN** `ssd1309_draw_line(p, 10, 10, 10, 10, on)` is called
- **THEN** `ssd1309_get_pixel(p, 10, 10)` returns "on"

#### Scenario: Line endpoints outside the panel are clipped
- **WHEN** `ssd1309_draw_line(p, x0, y0, x1, y1, on)` is called with one or
  both endpoints outside `0..width-1` / `0..height-1`
- **THEN** only the in-bounds points along the line are set, per
  `ssd1309_set_pixel()`'s out-of-bounds-is-no-op behavior, and no
  out-of-bounds memory is written

### Requirement: Rectangle drawing
The driver SHALL provide
`ssd1309_draw_rect(p, x0, y0, x1, y1, fill, color)` to draw a rectangle with
corners `(x0, y0)` and `(x1, y1)` inclusive, in any corner order. When
`fill` is `false`, only the 1px-wide outline (four edges) is drawn. When
`fill` is `true`, every pixel within the rectangle is set to `color`. Both
cases are clipped per `ssd1309_set_pixel()` semantics.

#### Scenario: Draw a rectangle outline
- **WHEN** `ssd1309_draw_rect(p, 10, 10, 20, 15, false, on)` is called
- **THEN** `ssd1309_get_pixel(p, x, y)` returns "on" for every point on the
  four edges of the rectangle from `(10,10)` to `(20,15)`
- **AND** returns "off" for points strictly inside the rectangle (e.g.
  `(15, 12)`)

#### Scenario: Draw a filled rectangle
- **WHEN** `ssd1309_draw_rect(p, 10, 10, 20, 15, true, on)` is called
- **THEN** `ssd1309_get_pixel(p, x, y)` returns "on" for every `x` from 10
  to 20 and every `y` from 10 to 15 inclusive

#### Scenario: Corners given in reverse order
- **WHEN** `ssd1309_draw_rect(p, 20, 15, 10, 10, fill, color)` is called
  (corners reversed relative to the previous scenarios)
- **THEN** the result is identical to calling
  `ssd1309_draw_rect(p, 10, 10, 20, 15, fill, color)`

#### Scenario: Single-point rectangle
- **WHEN** `ssd1309_draw_rect(p, 10, 10, 10, 10, fill, on)` is called (with
  `fill` either `true` or `false`)
- **THEN** `ssd1309_get_pixel(p, 10, 10)` returns "on"

#### Scenario: Rectangle partially outside the panel is clipped
- **WHEN** `ssd1309_draw_rect(p, x0, y0, x1, y1, fill, on)` is called with
  one or more corners outside `0..width-1` / `0..height-1`
- **THEN** only the in-bounds points are set, per `ssd1309_set_pixel()`'s
  out-of-bounds-is-no-op behavior, and no out-of-bounds memory is written

### Requirement: Circle drawing
The driver SHALL provide
`ssd1309_draw_circle(p, x0, y0, r, fill, color)` to draw a circle centered at
`(x0, y0)` with radius `r`, using the midpoint circle algorithm. When `fill`
is `false`, only the 1px-wide outline is drawn. When `fill` is `true`, every
pixel within the disc is set to `color`. Both cases are clipped per
`ssd1309_set_pixel()` semantics.

#### Scenario: Draw a circle outline
- **WHEN** `ssd1309_draw_circle(p, 32, 32, 10, false, on)` is called
- **THEN** `ssd1309_get_pixel(p, x, y)` returns "on" for points on the
  circle's circumference (e.g. `(42, 32)`, `(22, 32)`, `(32, 42)`,
  `(32, 22)`)
- **AND** returns "off" for the center point `(32, 32)`

#### Scenario: Draw a filled circle
- **WHEN** `ssd1309_draw_circle(p, 32, 32, 10, true, on)` is called
- **THEN** `ssd1309_get_pixel(p, x, y)` returns "on" for the center point
  `(32, 32)` and for every point within the disc of radius 10 centered on
  `(32, 32)`

#### Scenario: Zero-radius circle draws a single point
- **WHEN** `ssd1309_draw_circle(p, 10, 10, 0, fill, on)` is called (with
  `fill` either `true` or `false`)
- **THEN** `ssd1309_get_pixel(p, 10, 10)` returns "on"
- **AND** no other pixels are set

#### Scenario: Circle partially outside the panel is clipped
- **WHEN** `ssd1309_draw_circle(p, x0, y0, r, fill, on)` is called with the
  circle's bounding box partially outside `0..width-1` / `0..height-1`
- **THEN** only the in-bounds points are set, per `ssd1309_set_pixel()`'s
  out-of-bounds-is-no-op behavior, and no out-of-bounds memory is written

### Requirement: Arrow drawing
The driver SHALL provide
`ssd1309_draw_arrow(p, x0, y0, x1, y1, size, color)` to draw a 1px-wide line
from `(x0, y0)` to `(x1, y1)` (as `ssd1309_draw_line()` does), plus a filled
triangular arrowhead at `(x1, y1)`. The arrowhead's two base corners are
located at approximately ±30° from the shaft's direction and at a distance
of `size + 2` pixels from the tip, giving an arrowhead base width of
approximately `size + 2` pixels. The arrowhead points away from
`(x0, y0)`, in any direction. All drawing is clipped per
`ssd1309_set_pixel()` semantics.

#### Scenario: Draw a horizontal arrow pointing right
- **WHEN** `ssd1309_draw_arrow(p, 10, 32, 30, 32, 6, on)` is called
- **THEN** `ssd1309_get_pixel(p, x, 32)` returns "on" for every `x` from 10
  to 30 inclusive
- **AND** pixels above and below `(30, 32)` near `x` slightly less than 30
  are also "on" (the filled arrowhead)

#### Scenario: Arrow direction follows the line in any orientation
- **WHEN** `ssd1309_draw_arrow(p, x0, y0, x1, y1, size, on)` is called with
  `(x1, y1)` in any direction relative to `(x0, y0)` (e.g. up, down,
  diagonal)
- **THEN** the shaft is drawn from `(x0, y0)` to `(x1, y1)`
- **AND** the filled arrowhead's apex is at `(x1, y1)`, with its base
  corners on `(x0, y0)`'s side, at approximately ±30° from the shaft
  direction

#### Scenario: Zero or negative size draws only the shaft
- **WHEN** `ssd1309_draw_arrow(p, x0, y0, x1, y1, size, on)` is called with
  `size <= 0`
- **THEN** the result is identical to calling
  `ssd1309_draw_line(p, x0, y0, x1, y1, on)`

#### Scenario: Arrow partially outside the panel is clipped
- **WHEN** `ssd1309_draw_arrow(p, x0, y0, x1, y1, size, on)` is called with
  the shaft or arrowhead partially outside `0..width-1` / `0..height-1`
- **THEN** only the in-bounds points are set, per `ssd1309_set_pixel()`'s
  out-of-bounds-is-no-op behavior, and no out-of-bounds memory is written

### Requirement: Triangle drawing
The driver SHALL provide
`ssd1309_draw_triangle(p, x0, y0, x1, y1, x2, y2, fill, color)` to draw a
triangle with vertices `(x0,y0)`, `(x1,y1)`, `(x2,y2)`. When `fill` is
`false`, only the 1px-wide outline (three edges) is drawn. When `fill` is
`true`, every pixel within the triangle is set to `color`. Both cases are
clipped per `ssd1309_set_pixel()` semantics.

#### Scenario: Draw a triangle outline
- **WHEN** `ssd1309_draw_triangle(p, 10, 10, 20, 10, 10, 20, false, on)` is
  called
- **THEN** `ssd1309_get_pixel(p, x, y)` returns "on" for every point on the
  three edges connecting `(10,10)`, `(20,10)`, and `(10,20)`
- **AND** returns "off" for points strictly inside the triangle (e.g.
  `(13, 13)`)

#### Scenario: Draw a filled triangle
- **WHEN** `ssd1309_draw_triangle(p, 10, 10, 20, 10, 10, 20, true, on)` is
  called
- **THEN** `ssd1309_get_pixel(p, x, y)` returns "on" for every point within
  the triangle bounded by `(10,10)`, `(20,10)`, and `(10,20)`, including its
  edges

#### Scenario: Vertex order does not matter
- **WHEN** `ssd1309_draw_triangle(p, x2, y2, x0, y0, x1, y1, fill, color)` is
  called with the same three vertices in a different order
- **THEN** the result is identical to calling
  `ssd1309_draw_triangle(p, x0, y0, x1, y1, x2, y2, fill, color)`

#### Scenario: Degenerate triangle with collinear or repeated vertices
- **WHEN** `ssd1309_draw_triangle(p, x0, y0, x1, y1, x2, y2, fill, on)` is
  called with all three vertices collinear (including the case where two or
  three vertices are identical)
- **THEN** the pixels along the line(s) connecting the distinct vertices are
  set to "on"
- **AND** no out-of-bounds memory is written

#### Scenario: Triangle partially outside the panel is clipped
- **WHEN** `ssd1309_draw_triangle(p, x0, y0, x1, y1, x2, y2, fill, on)` is
  called with one or more vertices outside `0..width-1` / `0..height-1`
- **THEN** only the in-bounds points are set, per `ssd1309_set_pixel()`'s
  out-of-bounds-is-no-op behavior, and no out-of-bounds memory is written

### Requirement: Polygon drawing
The driver SHALL provide a `ssd1309_point_t` struct
(`{ int16_t x; int16_t y; }`) describing a single vertex, and
`ssd1309_draw_polygon(p, points, num_points, fill, color)` to draw a closed
polygon through `points[0]..points[num_points-1]` (`num_points >= 3`). When
`fill` is `false`, only the 1px-wide outline is drawn: an edge between each
consecutive pair of points, plus a closing edge from `points[num_points-1]`
back to `points[0]`. When `fill` is `true`, every pixel within the polygon
(per the even-odd scanline fill rule) is set to `color`. Both cases are
clipped per `ssd1309_set_pixel()` semantics. Polygons with more than
`SSD1309_POLYGON_MAX_POINTS` vertices are not supported.

#### Scenario: Draw a polygon outline
- **WHEN** `ssd1309_draw_polygon(p, points, 4, false, on)` is called with
  `points` describing a square `(10,10)`, `(20,10)`, `(20,20)`, `(10,20)`
- **THEN** `ssd1309_get_pixel(p, x, y)` returns "on" for every point on the
  four edges of the square, including the closing edge from `(10,20)` back
  to `(10,10)`
- **AND** returns "off" for points strictly inside the square (e.g.
  `(15, 15)`)

#### Scenario: Draw a filled polygon
- **WHEN** `ssd1309_draw_polygon(p, points, 4, true, on)` is called with the
  same square as above
- **THEN** `ssd1309_get_pixel(p, x, y)` returns "on" for every point within
  the square, including its edges

#### Scenario: Filled non-convex polygon
- **WHEN** `ssd1309_draw_polygon(p, points, num_points, true, on)` is called
  with a non-convex (e.g. star or "L"-shaped) but non-self-intersecting
  polygon
- **THEN** the even-odd scanline fill sets pixels "on" for every point
  inside the polygon and leaves pixels in concave notches "off"

#### Scenario: Polygon partially outside the panel is clipped
- **WHEN** `ssd1309_draw_polygon(p, points, num_points, fill, on)` is called
  with one or more vertices outside `0..width-1` / `0..height-1`
- **THEN** only the in-bounds points are set, per `ssd1309_set_pixel()`'s
  out-of-bounds-is-no-op behavior, and no out-of-bounds memory is written

### Requirement: Monospace text rendering
The driver SHALL provide a `ssd1309_font_t` descriptor type describing a
fixed-width font: a flat glyph bitmap table, glyph pixel width, glyph pixel
height, per-character advance (in pixels), and the inclusive printable
character range it covers (`first_char`..`last_char`). Glyph bitmaps SHALL
be stored column-major, with `(glyph_height + 7) / 8` bytes per column, bit 0
of each byte being the top row of its 8-row chunk.

The driver SHALL provide at least three built-in fonts, each covering
printable ASCII `0x20`-`0x7E`:
- `font5x7`: 5x7 glyphs, 6px advance (the glyph bitmaps are unchanged from
  the original single-font implementation).
- `font8x8`: 8x8 glyphs, 9px advance.
- `font10x14`: 10x14 glyphs, 12px advance.

The driver SHALL provide
`ssd1309_draw_char(p, font, x, y, c, color)` to draw a single glyph from the
given font into the framebuffer with its top-left corner at `(x, y)`, and
`ssd1309_draw_string(p, font, x, y, str, color)` to draw a NUL-terminated
string using the given font, advancing the x position by `font->advance`
pixels per character with no wrapping.

#### Scenario: Draw a printable character in a given font
- **WHEN** `ssd1309_draw_char(p, font, x, y, c, on)` is called with `c`
  within `font->first_char`..`font->last_char`
- **THEN** the corresponding glyph bitmap from `font` is written into the
  framebuffer at `(x, y)` using `ssd1309_set_pixel()` semantics (including
  clipping at panel edges), covering `font->glyph_width` x
  `font->glyph_height` pixels

#### Scenario: Draw a string advances by the font's advance per character
- **WHEN** `ssd1309_draw_string(p, font, x, y, "AB", on)` is called
- **THEN** the glyph for `'A'` is drawn at `(x, y)` and the glyph for `'B'`
  is drawn at `(x + font->advance, y)`

#### Scenario: Out-of-range characters render blank
- **WHEN** `ssd1309_draw_char(p, font, x, y, c, color)` is called with `c`
  outside `font->first_char`..`font->last_char`
- **THEN** the framebuffer region for that character cell is left unchanged
  (no glyph pixels are set)

#### Scenario: The 5x7 font matches the original single-font glyphs
- **WHEN** `ssd1309_draw_char(p, &font5x7, x, y, c, on)` is called with `c`
  in `0x20`-`0x7E`
- **THEN** the glyph drawn is pixel-identical to the original single-font
  implementation's 5x7 bitmap for that character, drawn within a 6x8 cell

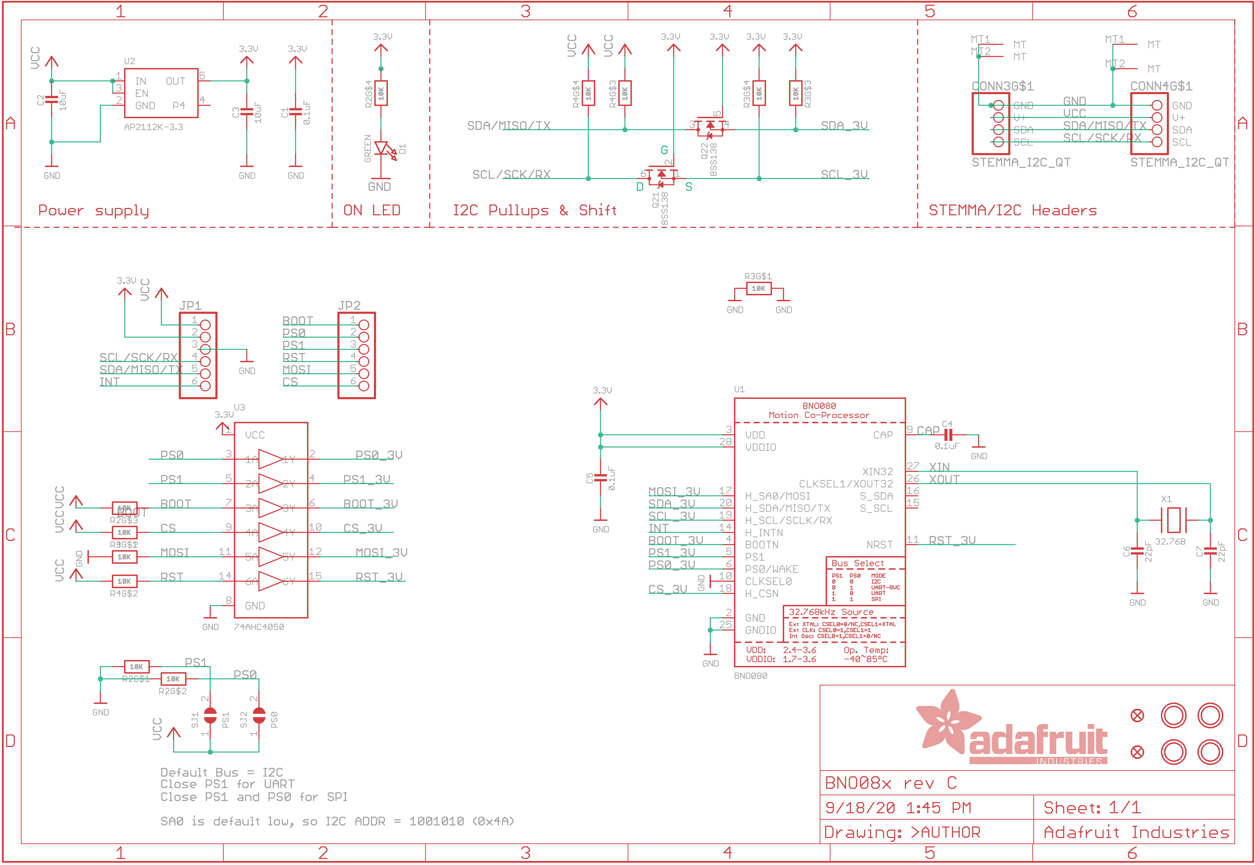
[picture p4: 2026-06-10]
docs/datasheets/bno085/Adafruit-BNO085-BOB-Schematic.png

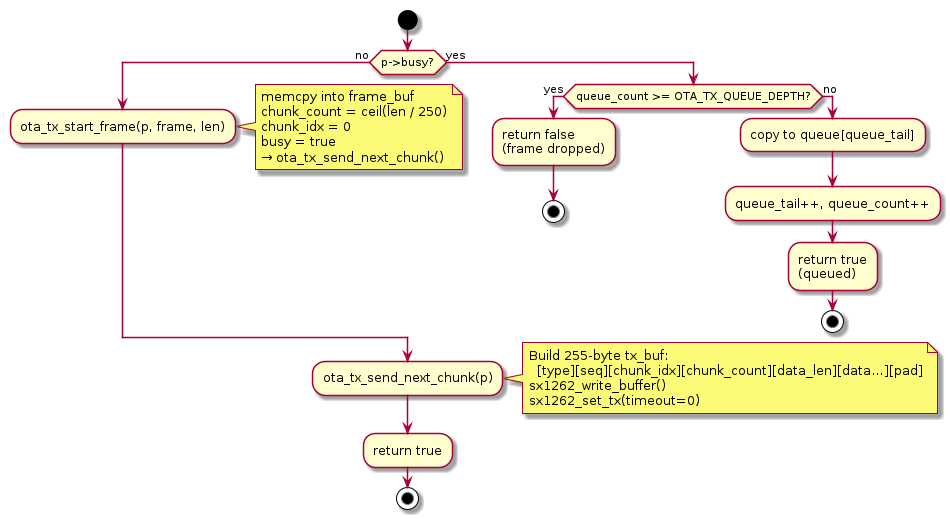
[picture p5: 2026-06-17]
docs/arch/img/ota-tx-push.png

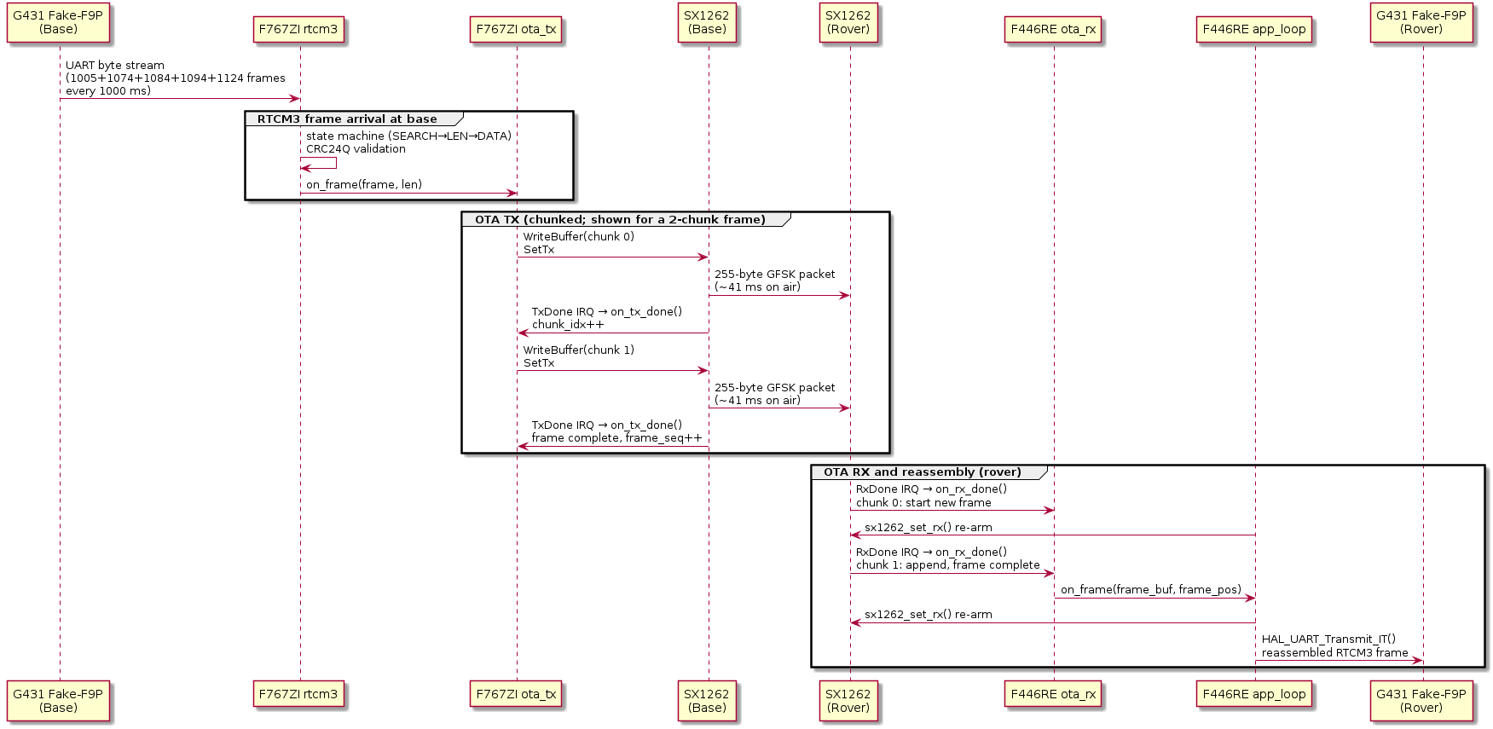
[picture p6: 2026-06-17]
docs/arch/img/ota-e2e.png

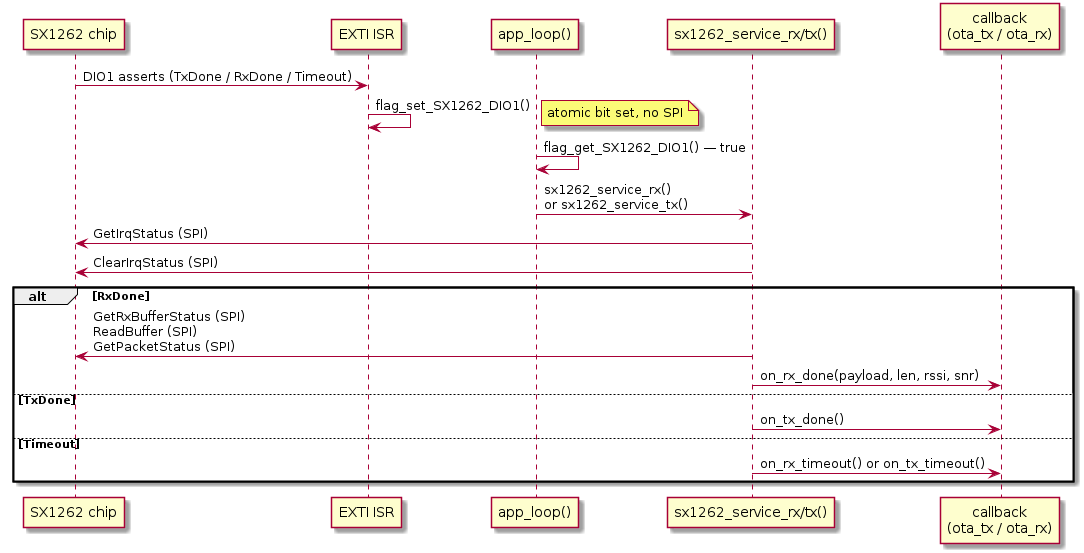
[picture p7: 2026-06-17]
docs/arch/img/dio1-interrupt-model.png

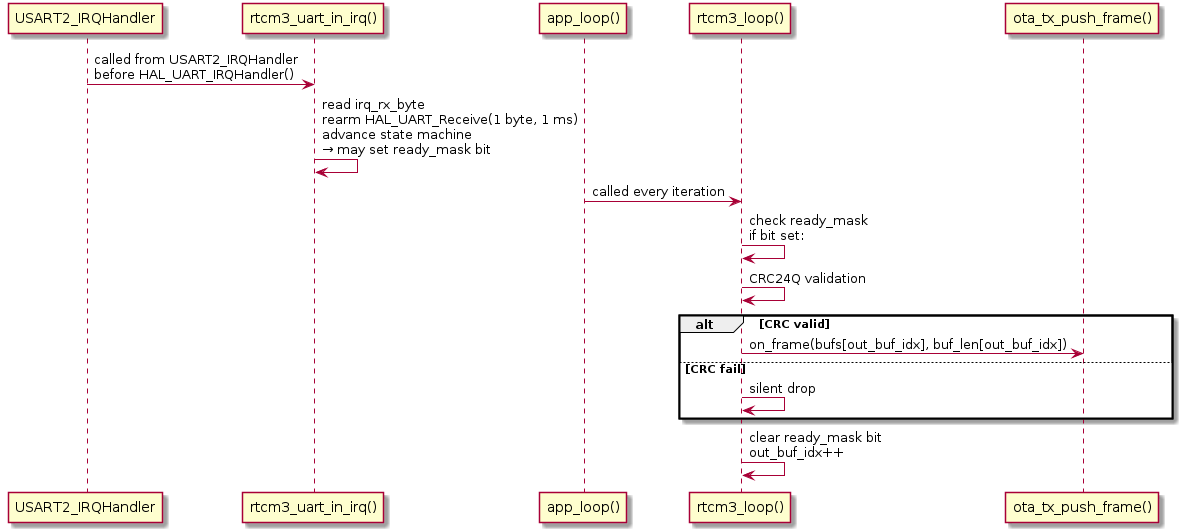
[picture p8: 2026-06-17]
docs/arch/img/rtcm3-irq-loop.png

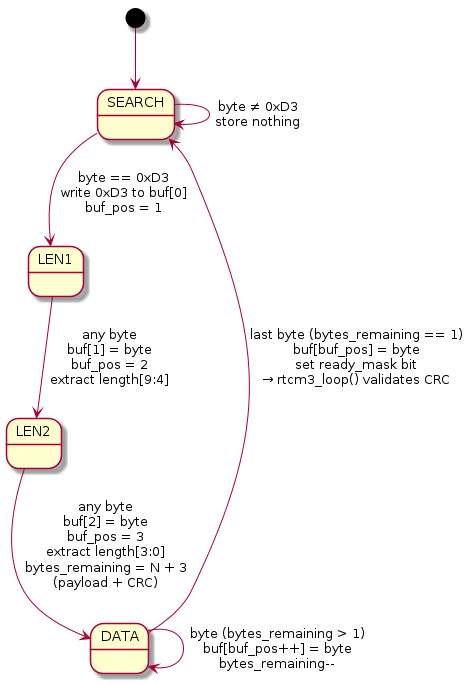
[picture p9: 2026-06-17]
docs/arch/img/rtcm3-state-machine.png

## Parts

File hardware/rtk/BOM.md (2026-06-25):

# Schematic BOM — rtk PCB

Generated from KiCad schematics. One row per reference designator.
**Purpose:** footprint audit before PCB layout — verify every footprint against the actual part's datasheet land pattern.

Key:
- **Footprint** — KiCad library:footprint as currently assigned in the schematic
- **⚠** — suspected issue, needs checking before layout

---

## Capacitors

| Ref | Value | Footprint | Sheet | Notes |
|-----|---|---|---|---|
| C1 | 1u | `C_0805_2012Metric_Pad1.18x1.45mm_HandSolder` | power | Tantallum (TAJR105M016RNJ) — verify 0805 land pattern matches AVX/Kyocera footprint |
| C2 | 4u7 | `C_0805_2012Metric_Pad1.18x1.45mm_HandSolder` | power | Tantalum (TAJP475K016RNJ) — same as C1 |
| C3 | 4u7 | `C_0805_2012Metric_Pad1.18x1.45mm_HandSolder` | power | Tantalum (TAJP475K016RNJ) — same as C1 |
| C4 | 100n | `C_0603_1608Metric_Pad1.08x0.95mm_HandSolder` | power | TPS63020 CvinA decoupling |
| C5 | 22u | `C_0603_1608Metric_Pad1.08x0.95mm_HandSolder` | power | TPS63020 Cin — part is C1608X5R1A226M080AC (0603/1608 metric) ✓ |
| C6 | 47u | `C_0805_2012Metric_Pad1.18x1.45mm_HandSolder` | power | TPS63020 Cout — part is MSASJ21GBB5476MTNA01 (0805/2012 metric) ✓ |
| C7 | 10n | `C_0603_1608Metric_Pad1.08x0.95mm_HandSolder` | zed-f9p-05b | VCC_RF decoupling |
| C8 | 100n | `C_0805_2012Metric_Pad1.18x1.45mm_HandSolder` | stm32f765vit | VDD decoupling |
| C9 | 100n | `C_0805_2012Metric_Pad1.18x1.45mm_HandSolder` | stm32f765vit | VDD decoupling |
| C10 | 100n | `C_0805_2012Metric_Pad1.18x1.45mm_HandSolder` | stm32f765vit | VDD decoupling |
| C11 | 100n | `C_0805_2012Metric_Pad1.18x1.45mm_HandSolder` | stm32f765vit | VDD decoupling |
| C12 | 100n | `C_0805_2012Metric_Pad1.18x1.45mm_HandSolder` | stm32f765vit | VDD decoupling |
| C13 | 100n | `C_0805_2012Metric_Pad1.18x1.45mm_HandSolder` | stm32f765vit | VDD decoupling |
| C14 | 100n | `C_0805_2012Metric_Pad1.18x1.45mm_HandSolder` | stm32f765vit | VDD decoupling |
| C15 | 100n | `C_0805_2012Metric_Pad1.18x1.45mm_HandSolder` | stm32f765vit | VDD decoupling |
| C16 | 10u | `C_0805_2012Metric_Pad1.18x1.45mm_HandSolder` | stm32f765vit | **T529P106M010AAE200** — Kemet KO-CAP polymer tant, 10µF 10V 0805, 200mΩ. Polarised symbol (C_Polarized_Small). ✓ |
| C17 | 100n | `C_0805_2012Metric_Pad1.18x1.45mm_HandSolder` | stm32f765vit | VDD decoupling |
| C18 | 10u | `C_0805_2012Metric_Pad1.18x1.45mm_HandSolder` | stm32f765vit | **T529P106M010AAE200** — same as C16 ✓ |
| C19 | 100n | `C_0805_2012Metric_Pad1.18x1.45mm_HandSolder` | stm32f765vit | VDD decoupling |
| C20 | 10u | `C_0805_2012Metric_Pad1.18x1.45mm_HandSolder` | stm32f765vit | **T529P106M010AAE200** — same as C16 ✓ |
| C21 | 100n | `C_0805_2012Metric_Pad1.18x1.45mm_HandSolder` | stm32f765vit | VDD decoupling |
| C22 | 100n | `C_0805_2012Metric_Pad1.18x1.45mm_HandSolder` | usb2hs | USB3300 decoupling |
| C23 | 100n | `C_0805_2012Metric_Pad1.18x1.45mm_HandSolder` | usb2hs | USB3300 decoupling |
| C24 | 100n | `C_0805_2012Metric_Pad1.18x1.45mm_HandSolder` | usb2hs | USB3300 decoupling |
| C25 | 100n | `C_0805_2012Metric_Pad1.18x1.45mm_HandSolder` | usb2hs | USB3300 decoupling |
| C26 | 100n | `C_0805_2012Metric_Pad1.18x1.45mm_HandSolder` | stm32f765vit | Decoupling |
| C27 | 100n | `C_0805_2012Metric_Pad1.18x1.45mm_HandSolder` | usb2hs | USB3300 decoupling |
| C28 | 470n | `C_0805_2012Metric_Pad1.18x1.45mm_HandSolder` | usb2hs | USB3300 VDD1.8 bulk |
| C29 | 470n | `C_0805_2012Metric_Pad1.18x1.45mm_HandSolder` | usb2hs | USB3300 VDD1.8 bulk |
| C30 | 100n | `C_0805_2012Metric_Pad1.18x1.45mm_HandSolder` | usb2hs | USB3300 decoupling |
| C31 | 10n | `C_0805_2012Metric_Pad1.18x1.45mm_HandSolder` | power | TPS63020 soft-start / inrush (C_SS) |
| C32 | 1u | `C_0805_2012Metric_Pad1.18x1.45mm_HandSolder` | stm32f765vit | STM32 VCAP_1 (internal LDO) |
| C33 | 1u | `C_0805_2012Metric_Pad1.18x1.45mm_HandSolder` | stm32f765vit | STM32 VCAP_2 (internal LDO) |
| C34 | 100n | `C_0603_1608Metric_Pad1.08x0.95mm_HandSolder` | zed-f9p-05b | V_BCKP decoupling |

---

## Resistors

| Ref | Value | Footprint | Sheet | Notes |
|-----|---|---|---|---|
| R1 | 1k13 | `R_0805_2012Metric_Pad1.20x1.40mm_HandSolder` | power | BQ24075 ISET |
| R2 | 1K5 | `R_0805_2012Metric_Pad1.20x1.40mm_HandSolder` | power | BQ24075 nPGOOD LED pull-up |
| R3 | 1K5 | `R_0805_2012Metric_Pad1.20x1.40mm_HandSolder` | power | BQ24075 nCHG LED pull-up |
| R4 | 1k18 | `R_0805_2012Metric_Pad1.20x1.40mm_HandSolder` | power | BQ24075 — check function |
| R5 | 46k4 | `R_0805_2012Metric_Pad1.20x1.40mm_HandSolder` | power | BQ24075 TMR |
| R6 | 1k | `R_0805_2012Metric_Pad1.20x1.40mm_HandSolder` | power | LED current limit |
| R7 | 768k | `R_0805_2012Metric_Pad1.20x1.40mm_HandSolder` | power | TPS63020 Rfbt (FB top) |
| R8 | 137k | `R_0805_2012Metric_Pad1.20x1.40mm_HandSolder` | power | TPS63020 Rfbb (FB bottom) |
| R9 | 12k | `R_0805_2012Metric_Pad1.20x1.40mm_HandSolder` | usb2hs | USB3300 RBIAS |
| R10 | 10K | `R_0805_2012Metric_Pad1.20x1.40mm_HandSolder` | usb2hs | USB3300 VBUS protect |
| R11 | 5k1 | `R_0805_2012Metric_Pad1.20x1.40mm_HandSolder` | power | USB-C CC1 pull-down |
| R12 | 5k1 | `R_0805_2012Metric_Pad1.20x1.40mm_HandSolder` | power | USB-C CC2 pull-down |
| R13 | NF or 82k5 | `R_0805_2012Metric_Pad1.20x1.40mm_HandSolder` | power | TPS63020 TS pin (NF or 82k5 to set threshold) |
| R14 | NF or 1M | `R_0805_2012Metric_Pad1.20x1.40mm_HandSolder` | power | TPS63020 bleed resistor (NF or 1M) |
| R15 | 1k | `R_0805_2012Metric_Pad1.20x1.40mm_HandSolder` | stm32f765vit | BOOT0 pull-down |
| R16 | 4k7 | `R_0805_2012Metric_Pad1.20x1.40mm_HandSolder` | stm32f765vit | I2C4 SDA pull-up |
| R17 | 4k7 | `R_0805_2012Metric_Pad1.20x1.40mm_HandSolder` | stm32f765vit | I2C4 SCL pull-up |
| R18 | 10k | `R_0805_2012Metric_Pad1.20x1.40mm_HandSolder` | zed-f9p-05b | ZED-F9P SAFEBOOT_N pull-up |
| R19 | 10k | `R_0805_2012Metric_Pad1.20x1.40mm_HandSolder` | zed-f9p-05b | ZED-F9P RESET_N pull-up |
| R20 | 1k5 | `R_0805_2012Metric_Pad1.20x1.40mm_HandSolder` | stm32f765vit | LD3 pull-up (PD5) |
| R21 | 1k5 | `R_0805_2012Metric_Pad1.20x1.40mm_HandSolder` | stm32f765vit | LD4 pull-up (PD6) |
| R22 | 100k | `R_0805_2012Metric_Pad1.20x1.40mm_HandSolder` | power | VBAT divider top — VBAT to VBAT_2 |
| R23 | 100k | `R_0805_2012Metric_Pad1.20x1.40mm_HandSolder` | power | VBAT divider bottom — VBAT_2 to GND → PA1 ADC1_IN1 |

---

## Inductors

| Ref | Value | Footprint | Sheet | Notes |
|-----|---|---|---|---|
| L1 | 1uH | `IND_DFE2016_2X1P6_MUR` | power | TPS63020 switching inductor — verify custom footprint matches DFE201610E-1R0M |
| L2 | 8n | `L_0402_1005Metric` | zed-f9p-05b | Bias-T RF choke — LQW15AN8N0G8ZD (Murata, 8.0nH ±2%, wire-wound 0402) [DigiKey](https://www.digikey.co.uk/en/products/detail/murata-electronics/LQW15AN8N0G8ZD/6799012) |

---

## Diodes / ESD / LED

| Ref | Value | Footprint | Sheet | Notes |
|-----|---|---|---|---|
| D1 | 1N4148W | `D_SOD-123` | power | TPS63020 inrush diode |
| D2 | USBLC6-2SC6 | `SOT-23-6` | usb2hs | USB D+/D- dual-line ESD TVS — replaced PRTR5V0U2X (bulk only). D3 removed (one chip covers both lines) ✓ |
| LD1 | LED | `LED_0805_2012Metric_Pad1.15x1.40mm_HandSolder` | power | **Green** — nPGOOD status |
| LD2 | LED | `LED_0805_2012Metric_Pad1.15x1.40mm_HandSolder` | power | **Red** — nCHG status |
| LD3 | LED | `LED_0805_2012Metric_Pad1.15x1.40mm_HandSolder` | stm32f765vit | **Green** — debug/status, PD5, open-drain, on at startup |
| LD4 | LED | `LED_0805_2012Metric_Pad1.15x1.40mm_HandSolder` | stm32f765vit | **Red** — debug/status, PD6, open-drain, on at startup |

---

## ICs / Modules

| Ref | Value | Footprint | Sheet | Notes |
|-----|---|---|---|---|
| U1 | BQ24075RGT | `VQFN-16-1EP_3x3mm_P0.5mm_EP1.6x1.6mm` | power | Battery charger / power path |
| U2 | TPS63020DSJR | `DSJ14_2P85X1P58` | power | Buck-boost — verify custom footprint matches VSON-14 land pattern in TPS63020 datasheet |
| U3 | STM32F765VITx | `LQFP-100_14x14mm_P0.5mm` | stm32f765vit | Main MCU |
| U4 | ZED-F9H-01B | `MOD54_ZED-F9H_UBL` | zed-f9p-05b | ⚠ **Part number: schematic says ZED-F9H-01B, project spec says ZED-F9P-05B** — confirm correct module |
| U5 | ESP32-S3-ZERO | `MODULE_ESP32-S3-ZERO` | stm32f765vit | BLE bridge module |
| U6 | CORE1262-868M | `XCVR_CORE1262-868M` | stm32f765vit | LoRa module — note: project uses LF (410-510 MHz) variant, confirm symbol/footprint match |
| U7 | LSM6DSOX | `PQFN50P250X300X86-14N` | stm32f765vit | IMU (accel + gyro) — order LSM6DSRXTR (Last Time Buy); LSM6DSOXTR is pin-compatible fallback when DSR unavailable |
| U8 | USB3300-EZK | `QFN-32-1EP_5x5mm_P0.5mm_EP3.45x3.45mm` | usb2hs | ULPI USB PHY |

---

## Connectors

| Ref | Value | Footprint | Sheet | Notes |
|-----|---|---|---|---|
| J1 | USB4105-GF-A | `USB4105_GCT` | power | USB-C receptacle (power in) |
| J3 | B2B-PH-SM4-TBLFSN | `CONN_B2B-PH-SM4-TBLFSN_JST` | power | Battery connector (JST PH 2-pin) |
| J4 | Conn_01x02_Pin | `PinHeader_1x02_P2.54mm_Vertical` | power | On/off switch header ✓ |
| J5 | Conn_Coaxial | `SMA_BAT_Wireless_BWSMA-KWE-Z001` | zed-f9p-05b | GNSS SMA |
| J6 | MEM2052-00-195-00-A_REVA | `GCT_MEM2052-00-195-00-A_REVA` | stm32f765vit | microSD card socket |
| J7 | Conn_01x04_Pin | `PinHeader_1x04_P2.54mm_Vertical` | stm32f765vit | Debug header |
| J8 | Conn_01x01_Pin | `PinHeader_1x01_P2.54mm_Vertical` | stm32f765vit | BOOT0 test point / header |
| J9 | Conn_01x08_Pin | `PinHeader_1x08_P2.54mm_Vertical` | stm32f765vit | Expansion / debug |
| J10 | Conn_01x02_Pin | `PinHeader_1x02_P2.54mm_Vertical` | stm32f765vit | Header |
| J11 | Conn_01x06_Pin | `PinHeader_1x06_P2.54mm_Vertical` | usb2hs | MMC5603NJ sub-board connector |

---

## Crystals / TCXOs

| Ref | Value | Footprint | Sheet | Notes |
|-----|---|---|---|---|
| Y1 | ASTX-H11-16.000MHZ-T | `XTAL_ASTX-H11-16.000MHZ-T` | stm32f765vit | STM32 HSE TCXO (16 MHz) |
| Y2 | ASTX-H11-24.000MHZ-T | `XTAL_ASTX-H11-16.000MHZ-T` | usb2hs | USB3300 TCXO (24 MHz) — footprint is the 16 MHz variant name but same physical package ✓ |

---

## Items not in schematic (expected from project spec)

| Part | Notes |
|---|---|
| MMC5603NJ | On MMC560x-B sub-board, connects via J11 — not placed as symbol |

---

## Issues to resolve before layout

| # | Ref | Issue |
|---|-----|---|
| 1 | D2 | ~~PRTR5V0U2X SOT-143~~ **Fixed** — USBLC6-2SC6 SOT-23-6, D3 removed ✓ |
| 2 | C16, C18, C20 | ~~Through-hole electrolytic footprint~~ **Fixed** — T529P106M010AAE200 polymer tant, 0805 HandSolder ✓ |
| 3 | U4 | ~~Symbol says ZED-F9H-01B~~ **Confirmed OK** — same symbol and footprint as ZED-F9P-05B ✓ |
| 4 | J4 | ~~No footprint~~ **Fixed** — on/off switch, PinHeader_1x02_P2.54mm_Vertical ✓ |
| 5 | R2, R3 | ~~Value query~~ **Confirmed OK** — BQ24075 nPGOOD/nCHG open-drain LED pull-ups, 1K5 correct ✓ |

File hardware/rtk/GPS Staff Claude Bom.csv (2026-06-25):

Country of Origin may be different at time of shipment.
The HTSUS and ECCN information shown is for informational purposes only and is not a representation or warranty as to the accuracy or reliability of these classifications. All information is provided "as is" and is subject to change without notice. Any use made of the information provided is without recourse to Digi-Key and at the user's risk.
Index | Manufacturer Part Number | Manufacturer Name | Description | Lead Time | Availability | Stock Status | Attrition % | Requested Quantity 1 | Pack Quantity 1 | Pack Type 1 | Digi-Key Part Number 1 | Unit Price 1 | Extended Price 1 | Minimum Order Quantity 1 | Customer Reference | Requested Part Number | Lead Weeks | Datasheet | Reference Designator | US Import Tariff | Note | Part Status | RoHS Status | REACH Status | Moisture Sensitivity Level (MSL) | ECCN | HTSUS | Country of Origin | Environmental Information | Original Part numbers | Unit of Measure | Image | Product Notes
1 | TAJR105M016RNJ | KYOCERA AVX | CAP TANT 1UF 20% 16V 0805 |  | 20,737 | In Stock |  | 1 | 1 | Cut Tape (CT) | 478-3050-1-ND | 0.30000 | £0.30 | 1 | C1 | TAJR105M016RNJ | 13 | https://datasheets.kyocera-avx.com/TAJ.pdf |  | - |  | Active | ROHS3 Compliant | REACH Unaffected | 1 (Unlimited) | EAR99 | 8532.21.0050 | El Salvador |  | C1 | Each | https://mm.digikey.com/Volume0/opasdata/d220001/medias/images/5557/478_Capacitor-Tan-Case-Code-R.jpg
2 | TAJP475K016RNJ | KYOCERA AVX | CAP TANT 4.7UF 10% 16V 0805 |  | 6,135 | In Stock |  | 2 | 2 | Cut Tape (CT) | 478-TAJP475K016RNJCT-ND | 0.80000 | £1.60 | 1 | C2, C3 | TAJP475K016RNJ | 25 | https://datasheets.kyocera-avx.com/TAJ.pdf |  | - |  | Active | ROHS3 Compliant | REACH Unaffected | 1 (Unlimited) | EAR99 | 8532.21.0050 | Czech Republic |  | C2,C3 | Each | https://mm.digikey.com/Volume0/opasdata/d220001/medias/images/2490/CERAMIC%20NULL%20SERIES%200805.jpg
3 | C1608X5R1A226M080AC | TDK | CAP CER 22UF 10V X5R 0603 |  | 1,530,197 | In Stock |  | 1 | 1 | Cut Tape (CT) | 445-9077-1-ND | 0.22000 | £0.22 | 1 | C5 | C1608X5R1A226M080AC | 24 | https://product.tdk.com/system/files/dam/doc/product/capacitor/ceramic/mlcc/catalog/mlcc_commercial_general_en.pdf |  | - |  | Active | ROHS3 Compliant | REACH Unaffected | 1 (Unlimited) | EAR99 | 8532.24.0020 | Japan | https://product.tdk.com/system/files/dam/doc/product/capacitor/ceramic/mlcc/rohs/mlccrohs_commercial_general_en.pdf|https://product.tdk.com/en/environment/index.html | C5 | Each | https://mm.digikey.com/Volume0/opasdata/d220001/derivates/6/003/121/213/cut-tape-render_web%28640x640%29.jpg
4 | MSASJ21GBB5476MTNA01 | Taiyo Yuden | CAP CER 47UF 6.3V X5R 0805 |  | 1,817 | In Stock |  | 1 | 1 | Cut Tape (CT) | 587-MSASJ21GBB5476MTNA01CT-ND | 0.24000 | £0.24 | 1 | C6 | MSASJ21GBB5476MTNA01 | 14 | https://mm.digikey.com/Volume0/opasdata/d220001/medias/docus/5731/MSR01_e.pdf |  | - |  | Active | ROHS3 Compliant | REACH Unaffected | 1 (Unlimited) | EAR99 | 8532.24.0020 | Malaysia |  | C6 | Each | https://mm.digikey.com/Volume0/opasdata/d220001/medias/images/4198/MFG_MSASJ21GBB5476MTNA01.jpg
5 | T529P106M010AAE200 | KEMET | CAP TANT POLY 10UF 10V 0805 |  | 84,669 | In Stock |  | 3 | 3 | Cut Tape (CT) | 399-17689-1-ND | 1.03000 | £3.09 | 1 | C16,C18,C20 | T529P106M010AAE200 | 18 | https://yageogroup.com/content/datasheet/asset/file/KEM_T2076_T52X-530 |  | - |  | Active | ROHS3 Compliant | REACH Unaffected | 3 (168 Hours) | EAR99 | 8532.21.0050 | Thailand |  | C16,C18,C20 | Each | https://mm.digikey.com/Volume0/opasdata/d220001/medias/images/533/MFG_T529.jpg
6 | STM32F765VIT6 | STMicroelectronics | IC MCU 32BIT 2MB FLASH 100LQFP |  | 4,652 | In Stock |  | 1 | 1 | Tray | 497-16631-ND | 15.94000 | £15.94 | 1 | U3 | STM32F765VIT6 | 30 | https://www.st.com/content/ccc/resource/technical/document/datasheet/group3/c5/37/9c/1d/a6/09/4e/1a/DM00273119/files/DM00273119.pdf/jcr:content/translations/e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 |  | - |  | Active | ROHS3 Compliant | REACH Unaffected | 3 (168 Hours) | 3A991A2 | 8542.31.0025 | Philippines |  | STM32F765VIT6 | Each | https://mm.digikey.com/Volume0/opasdata/d220001/medias/images/6249/497%7E1L_ME%7ET%7E100.jpg
7 | LSM6DSRXTR | STMicroelectronics | CONSUMER MEMS |  | 971 | In Stock |  | 2 | 2 | Cut Tape (CT) | 497-LSM6DSRXCT-ND | 3.67000 | £7.34 | 1 |  | LSM6DSRXTR | 24 | https://www.st.com/resource/en/datasheet/lsm6dsrx.pdf |  | - |  | Last Time Buy | ROHS3 Compliant | REACH Unaffected | 3 (168 Hours) | EAR99 | 8542.39.0070 | Italy |  | LSM6DSRXTR | Each | https://mm.digikey.com/Volume0/opasdata/d220001/derivates/6/003/237/368/497%7E14LGA-.86-2.5X3%7E%7E14_web%28640x640%29.jpg
8 | ZED-F9P-05B | u-blox | HIGH PRECISION GNSS MODULE W RTK |  | 577 | In Stock |  | 1 | 1 | Cut Tape (CT) | 672-ZED-F9P-05BCT-ND | 97.68000 | £97.68 | 1 | U4 | ZED-F9P-05B | 20 | https://content.u-blox.com/sites/default/files/documents/ZED-F9P-05B_DataSheet_UBXDOC-963802114-12824.pdf |  | - |  | Active | Unknown |  | 4 (72 Hours) | 7A994 | 8526.91.0020 | Austria |  | ZED-F9P-05B | Each | https://mm.digikey.com/Volume0/opasdata/d220001/derivates/6/003/214/065/MFG_ZED-F9P-05B-top-bottom_web%28640x640%29.jpg
9 | ASTX-H11-16.000MHZ-T | Abracon LLC | XTAL OSC TCXO 16.0000MHZ HCMOS |  | 1,443 | In Stock |  | 1 | 1 | Cut Tape (CT) | 535-12044-1-ND | 3.37000 | £3.37 | 1 | Y1 | ASTX-H11-16.000MHZ-T | 12 | https://abracon.com/Oscillators/ASTX-H11.pdf |  | - |  | Active | ROHS3 Compliant | REACH Unaffected | Not Applicable | EAR99 | 8542.39.0090 | Taiwan | https://abracon.com/uploads/resources/REACH-224-SVHC-Certificate-Rev-S-2022-06-17-ABRACON-LLC.pdf | ASTX-H11-16.000MHZ-T | Each | https://mm.digikey.com/Volume0/opasdata/d220001/derivates/6/002/633/817/ASTX-H11%20SERIES_web%28640x640%29.jpg
10 | ASTX-H11-24.000MHZ-T | Abracon LLC | XTAL OSC TCXO 24.0000MHZ HCMOS |  | 995 | In Stock |  | 1 | 1 | Cut Tape (CT) | 535-12046-1-ND | 3.37000 | £3.37 | 1 | Y2 | ASTX-H11-24.000MHZ-T | 12 | https://abracon.com/Oscillators/ASTX-H11.pdf |  | - |  | Active | ROHS3 Compliant | REACH Unaffected | Not Applicable | EAR99 | 8542.39.0090 | Taiwan | https://abracon.com/uploads/resources/REACH-224-SVHC-Certificate-Rev-S-2022-06-17-ABRACON-LLC.pdf | ASTX-H11-24.000MHZ-T | Each | https://mm.digikey.com/Volume0/opasdata/d220001/derivates/6/002/633/817/ASTX-H11%20SERIES_web%28640x640%29.jpg
11 | MEM2052-00-195-00-A | GCT | CONN MICRO SD CARD R/A SMD |  | 26,536 | In Stock |  | 1 | 1 | Cut Tape (CT) | 2073-MEM2052-00-195-00-ACT-ND | 0.85000 | £0.85 | 1 | J6 | MEM2052-00-195-00-A | 12 | https://gct.co/files/specs/mem2052-spec.pdf |  | - |  | Active | ROHS3 Compliant | REACH Unaffected | 1 (Unlimited) | EAR99 | 8536.69.4040 | China | https://gct.co/files/info/gct_certificate_of_compliance.pdf | MEM2052-00-195-00-A | Each | https://mm.digikey.com/Volume0/opasdata/d220001/medias/images/5022/MFG_MEM2052-00-195-00-A.jpg
12 | USB4105-GF-A | GCT | CONN RCP USB2.0 TYP C 16P SMD RA |  | 151,149 | In Stock |  | 1 | 1 | Cut Tape (CT) | 2073-USB4105-GF-ACT-ND | 0.59000 | £0.59 | 1 | J1 | USB4105-GF-A | 9 | https://gct.co/files/specs/usb4105-spec.pdf |  | - |  | Active | ROHS3 Compliant | REACH Unaffected | 1 (Unlimited) | EAR99 | 8536.69.4040 | China | https://gct.co/files/info/gct_certificate_of_compliance.pdf | USB4105-GF-A | Each | https://mm.digikey.com/Volume0/opasdata/d220001/medias/images/199/MFG_USB4105-GF-A.jpg
13 | B2B-PH-SM4-TB | JST Sales America Inc. | CONN HEADER SMD 2POS 2MM |  | 51,956 | In Stock |  | 1 | 1 | Cut Tape (CT) | 455-B2B-PH-SM4-TBCT-ND | 0.35000 | £0.35 | 1 | J3 | B2B-PH-SM4-TB | 25 | https://www.jst-mfg.com/product/pdf/eng/ePH.pdf |  | - |  | Active | ROHS3 Compliant | REACH Unaffected | 1 (Unlimited) | EAR99 | 8536.69.4040 | Malaysia |  | B2B-PH-SM4-TB | Each | https://mm.digikey.com/Volume0/opasdata/d220001/derivates/6/002/717/717/MFG_B2B-PH-SM4-TB%28LF%29%28SN%29_web%28640x640%29.jpg
14 | RNCP0805FTD1K50 | Stackpole Electronics Inc | RES 1.5K OHM 1% 1/4W 0805 |  | 27,807 | In Stock |  | 100 | 100 | Cut Tape (CT) | RNCP0805FTD1K50CT-ND | 0.00880 | £0.88 | 1 | R20, R21 | RNCP0805FTD1K50 | 21 | https://www.seielect.com/catalog/SEI-RNCP.pdf |  | - |  | Active | ROHS3 Compliant | REACH Unaffected | 1 (Unlimited) | EAR99 | 8533.21.0030 | Taiwan | https://www.seielect.com/catalog/SEI-RoHS_Compliance_Status.pdf|https://www.seielect.com/catalog/reach.pdf|https://www.seielect.com/catalog/sei-coc%20prop%2065.pdf | RNCP0805FTD1K50 | Each | https://mm.digikey.com/Volume0/opasdata/d220001/medias/images/4842/RNCP-Thin-Film-Chip-Resistor.jpg
15 | RNCP0805FTD1K00 | Stackpole Electronics Inc | RES 1K OHM 1% 1/4W 0805 |  | 155,577 | In Stock |  | 100 | 100 | Cut Tape (CT) | RNCP0805FTD1K00CT-ND | 0.00880 | £0.88 | 1 | R6 | RNCP0805FTD1K00 | 21 | https://www.seielect.com/catalog/SEI-RNCP.pdf |  | - |  | Active | ROHS3 Compliant | REACH Unaffected | 1 (Unlimited) | EAR99 | 8533.21.0030 | Taiwan | https://www.seielect.com/catalog/SEI-RoHS_Compliance_Status.pdf|https://www.seielect.com/catalog/reach.pdf|https://www.seielect.com/catalog/sei-coc%20prop%2065.pdf | RNCP0805FTD1K00 | Each | https://mm.digikey.com/Volume0/opasdata/d220001/derivates/6/003/121/213/cut-tape-render_web%28640x640%29.jpg
16 | CR0805-FX-4642ELF | Bourns Inc. | RES SMD 46.4K OHM 1% 1/8W 0805 |  | 19,479 | In Stock |  | 10 | 10 | Cut Tape (CT) | 118-CR0805-FX-4642ELFCT-ND | 0.02800 | £0.28 | 1 | R5 | CR0805-FX-4642ELF | 21 | https://bourns.com/docs/product-datasheets/cr.pdf?sfvrsn=574d41f6_14 |  | - |  | Active | ROHS3 Compliant | REACH Unaffected | 1 (Unlimited) | EAR99 | 8533.21.0030 | Taiwan | https://www.bourns.com/docs/Product-MDS/cr0805_mds.pdf|https://mm.digikey.com/Volume0/opasdata/d220001/medias/docus/6657/Bourns%20REACH%20247%20Jan%202025%20Statement.pdf|https://www.bourns.com/docs/rohs-cofc/crx_coc.pdf?sfvrsn=db3a74f6_10 | CR0805-FX-4642ELF | Each | https://mm.digikey.com/Volume0/opasdata/d220001/medias/images/505/CR0805-%282012-Metric%29.jpg
17 | CR0805-FX-1181ELF | Bourns Inc. | RES SMD 1.18K OHM 1% 1/8W 0805 |  | 24,792 | In Stock |  | 10 | 10 | Cut Tape (CT) | 118-CR0805-FX-1181ELFCT-ND | 0.02800 | £0.28 | 1 | R4 | CR0805-FX-1181ELF | 21 | https://bourns.com/docs/product-datasheets/cr.pdf?sfvrsn=574d41f6_14 |  | - |  | Active | ROHS3 Compliant | REACH Unaffected | 1 (Unlimited) | EAR99 | 8533.21.0030 | Taiwan | https://www.bourns.com/docs/Product-MDS/cr0805_mds.pdf|https://mm.digikey.com/Volume0/opasdata/d220001/medias/docus/6657/Bourns%20REACH%20247%20Jan%202025%20Statement.pdf|https://www.bourns.com/docs/rohs-cofc/crx_coc.pdf?sfvrsn=db3a74f6_10 | CR0805-FX-1181ELF | Each | https://mm.digikey.com/Volume0/opasdata/d220001/medias/images/505/CR0805-%282012-Metric%29.jpg
18 | CR0805-FX-1131ELF | Bourns Inc. | RES SMD 1.13K OHM 1% 1/8W 0805 |  | 23,449 | In Stock |  | 10 | 10 | Cut Tape (CT) | 118-CR0805-FX-1131ELFCT-ND | 0.02800 | £0.28 | 1 | R1 | CR0805-FX-1131ELF | 21 | https://bourns.com/docs/product-datasheets/cr.pdf?sfvrsn=574d41f6_14 |  | - |  | Active | ROHS3 Compliant | REACH Unaffected | 1 (Unlimited) | EAR99 | 8533.21.0030 | Taiwan | https://www.bourns.com/docs/Product-MDS/cr0805_mds.pdf|https://mm.digikey.com/Volume0/opasdata/d220001/medias/docus/6657/Bourns%20REACH%20247%20Jan%202025%20Statement.pdf|https://www.bourns.com/docs/rohs-cofc/crx_coc.pdf?sfvrsn=db3a74f6_10 | CR0805-FX-1131ELF | Each | https://mm.digikey.com/Volume0/opasdata/d220001/medias/images/505/CR0805-%282012-Metric%29.jpg
19 | CR0805-JW-512ELF | Bourns Inc. | RES SMD 5.1K OHM 5% 1/8W 0805 |  | 113,541 | In Stock |  | 10 | 10 | Cut Tape (CT) | 118-CR0805-JW-512ELFCT-ND | 0.01900 | £0.19 | 1 | R11, R12 | CR0805-JW-512ELF | 21 | https://bourns.com/docs/product-datasheets/cr.pdf?sfvrsn=574d41f6_14 |  | - |  | Active | ROHS3 Compliant | REACH Unaffected | 1 (Unlimited) | EAR99 | 8533.21.0030 | Taiwan | https://www.bourns.com/docs/Product-MDS/cr0805_mds.pdf|https://mm.digikey.com/Volume0/opasdata/d220001/medias/docus/6657/Bourns%20REACH%20247%20Jan%202025%20Statement.pdf|https://www.bourns.com/docs/rohs-cofc/crx_coc.pdf?sfvrsn=db3a74f6_10 | CR0805-JW-512ELF | Each | https://mm.digikey.com/Volume0/opasdata/d220001/medias/images/505/CR0805-%282012-Metric%29.jpg
20 | CR0805-FX-1003ELF | Bourns Inc. | RES SMD 100K OHM 1% 1/8W 0805 |  | 92,197 | In Stock |  | 10 | 10 | Cut Tape (CT) | CR0805-FX-1003ELFCT-ND | 0.02000 | £0.20 | 1 | R22, R23 | CR0805-FX-1003ELF | 21 | https://bourns.com/docs/product-datasheets/cr.pdf?sfvrsn=574d41f6_14 |  | - |  | Active | ROHS3 Compliant | REACH Unaffected | 1 (Unlimited) | EAR99 | 8533.21.0030 | Taiwan | https://www.bourns.com/docs/Product-MDS/cr0805_mds.pdf|https://mm.digikey.com/Volume0/opasdata/d220001/medias/docus/6657/Bourns%20REACH%20247%20Jan%202025%20Statement.pdf|https://www.bourns.com/docs/rohs-cofc/crx_coc.pdf?sfvrsn=db3a74f6_10 | CR0805-FX-1003ELF | Each | https://mm.digikey.com/Volume0/opasdata/d220001/medias/images/505/CR0805-%282012-Metric%29.jpg
21 | CR0603-FX-7683ELF | Bourns Inc. | RES SMD 768K OHM 1% 1/10W 0603 |  | 22,600 | In Stock |  | 10 | 10 | Cut Tape (CT) | 118-CR0603-FX-7683ELFCT-ND | 0.02000 | £0.20 | 1 | R7 | CR0603-FX-7683ELF | 21 | https://bourns.com/docs/product-datasheets/cr.pdf?sfvrsn=574d41f6_14 |  | - |  | Active | ROHS3 Compliant | REACH Unaffected | 1 (Unlimited) | EAR99 | 8533.21.0030 | Taiwan | https://www.bourns.com/docs/Product-MDS/cr0603_mds.pdf|https://mm.digikey.com/Volume0/opasdata/d220001/medias/docus/6657/Bourns%20REACH%20247%20Jan%202025%20Statement.pdf|https://www.bourns.com/docs/rohs-cofc/crx_coc.pdf?sfvrsn=db3a74f6_10 | CR0603-FX-7683ELF | Each | https://mm.digikey.com/Volume0/opasdata/d220001/medias/images/505/CR0603-%281608-Metric%29.jpg
22 | CR0805-FX-1373ELF | Bourns Inc. | RES SMD 137K OHM 1% 1/8W 0805 |  | 19,743 | In Stock |  | 10 | 10 | Cut Tape (CT) | 118-CR0805-FX-1373ELFCT-ND | 0.02800 | £0.28 | 1 | R8 | CR0805-FX-1373ELF | 21 | https://bourns.com/docs/product-datasheets/cr.pdf?sfvrsn=574d41f6_14 |  | - |  | Active | ROHS3 Compliant | REACH Unaffected | 1 (Unlimited) | EAR99 | 8533.21.0030 | Taiwan | https://www.bourns.com/docs/Product-MDS/cr0805_mds.pdf|https://mm.digikey.com/Volume0/opasdata/d220001/medias/docus/6657/Bourns%20REACH%20247%20Jan%202025%20Statement.pdf|https://www.bourns.com/docs/rohs-cofc/crx_coc.pdf?sfvrsn=db3a74f6_10 | CR0805-FX-1373ELF | Each | https://mm.digikey.com/Volume0/opasdata/d220001/medias/images/505/CR0805-%282012-Metric%29.jpg
23 | 1N4148W | SMC Diode Solutions | DIODE STANDARD 75V 250MA SOD123 |  | 233,593 | In Stock |  | 1 | 1 | Cut Tape (CT) | 1655-1N4148WCT-ND | 0.10000 | £0.10 | 1 | D1 | 1655-1N4148WTR-ND | 8 | https://www.smc-diodes.com/propdf/1N4148W%20N0571%20REV.E.pdf |  | - |  | Active | ROHS3 Compliant | REACH Affected | 1 (Unlimited) | EAR99 | 8541.10.0070 | China | https://www.smc-diodes.com/uploadfile/Declaration%20Letter%20for%20EU%20REACH-3.pdf|https://www.smc-diodes.com/uploadfile/ROHS%20Declaration%20Letter-4.pdf | 1655-1N4148WTR-ND | Each | https://mm.digikey.com/Volume0/opasdata/d220001/medias/images/6155/1655%7ESOD123%7E%7E2.jpg
24 | CR0805-FX-4701ELF | Bourns Inc. | RES SMD 4.7K OHM 1% 1/8W 0805 |  | 181,702 | In Stock |  | 10 | 10 | Cut Tape (CT) | CR0805-FX-4701ELFCT-ND | 0.02000 | £0.20 | 1 | R16, R17 | CR0805-FX-4701ELF | 21 | https://bourns.com/docs/product-datasheets/cr.pdf?sfvrsn=574d41f6_14 |  | - |  | Active | ROHS3 Compliant | REACH Unaffected | 1 (Unlimited) | EAR99 | 8533.21.0030 | Taiwan | https://www.bourns.com/docs/Product-MDS/cr0805_mds.pdf|https://mm.digikey.com/Volume0/opasdata/d220001/medias/docus/6657/Bourns%20REACH%20247%20Jan%202025%20Statement.pdf|https://www.bourns.com/docs/rohs-cofc/crx_coc.pdf?sfvrsn=db3a74f6_10 | CR0805-FX-4701ELF | Each | https://mm.digikey.com/Volume0/opasdata/d220001/medias/images/505/CR0805-%282012-Metric%29.jpg
25 | LQW15AN8N0G8ZD | Murata Electronics | FIXED IND 8NH 1.7A 50 MOHM SMD |  | 6,338 | In Stock |  | 1 | 1 | Cut Tape (CT) | 490-15587-1-ND | 0.13000 | £0.13 | 1 | L2 | LQW15AN8N0G8ZD | 21 | https://pim.murata.com/asset/pim4/inductor/JELF243A-9138_PDF_INDUCTOR |  | - |  | Active | ROHS3 Compliant | REACH Unaffected | 1 (Unlimited) | EAR99 | 8504.50.8000 | Japan |  | LQW15AN8N0G8ZD | Each | https://mm.digikey.com/Volume0/opasdata/d220001/medias/images/2323/LQW15A.jpg
26 | DFE201610E-1R0M=P2 | Murata Electronics | FIXED IND 1UH 2.7A 57 MOHM SMD |  | 54,354 | In Stock |  | 1 | 1 | Cut Tape (CT) | 490-18106-1-ND | 0.19000 | £0.19 | 1 | L1 | DFE201610E-1R0M=P2 | 21 | https://search.murata.co.jp/Ceramy/image/img/P02/J(E)TE243A-0001.pdf |  | - |  | Active | ROHS3 Compliant | REACH Unaffected | 1 (Unlimited) | EAR99 | 8504.50.8000 | Vietnam |  | DFE201610E-1R0M=P2 | Each | https://mm.digikey.com/Volume0/opasdata/d220001/derivates/6/002/840/747/LQM2MP%200806_web%28640x640%29.jpg
27 | USB3300-EZK | Microchip Technology | IC USB HOST/OTG PHY ULPI 32-QFN |  | 3,230 | In Stock |  | 1 | 1 | Tray | 638-1034-ND | 1.29000 | £1.29 | 1 | U8 | USB3300-EZK | 8 | https://ww1.microchip.com/downloads/aemDocuments/documents/OTH/ProductDocuments/DataSheets/00001783C.pdf |  | - |  | Active | ROHS3 Compliant | REACH Unaffected | 3 (168 Hours) | 3A991A2 | 8542.39.0070 | Taiwan | https://ww1.microchip.com/downloads/aemDocuments/documents/corporate-responsibilty/environmental/product-regulatory-information/Semiconductor_EnvCoC.pdf|https://ww1.microchip.com/downloads/aemDocuments/documents/corporate-responsibilty/environmental/product-regulatory-information/Microchip_REACH_Statement.pdf | USB3300-EZK | Each | https://mm.digikey.com/Volume0/opasdata/d220001/medias/images/4849/150_32-QFN.jpg
28 | GRM21BR72A474KA73L | Murata Electronics | CAP CER 0.47UF 100V X7R 0805 |  | 15,974 | In Stock |  | 10 | 10 | Cut Tape (CT) | 490-3326-1-ND | 0.17100 | £1.71 | 1 | C28, C29 | GRM21BR72A474KA73L | 17 | https://search.murata.co.jp/Ceramy/image/img/A01X/G101/ENG/GRM21BR72A474KA73-01.pdf |  | - |  | Active | ROHS3 Compliant | REACH Unaffected | 1 (Unlimited) | EAR99 | 8532.24.0020 | Japan |  | GRM21BR72A474KA73L | Each | https://mm.digikey.com/Volume0/opasdata/d220001/medias/images/5447/490-Ceramic-Capacitor-Tan-Field.jpg
29 | BQ24075RGTR | Texas Instruments | IC BATT CHG LI-ION 1CELL 16QFN |  | 1,894 | In Stock |  | 1 | 1 | Cut Tape (CT) | 296-38874-1-ND | 1.81000 | £1.81 | 1 | U1 | BQ24075RGTR | 6 | https://www.ti.com/general/docs/suppproductinfo.tsp?distId=10 |  | - |  | Active | ROHS3 Compliant | REACH Unaffected | 2 (1 Year) | EAR99 | 8542.39.0070 | China |  | BQ24075RGTR | Each | https://mm.digikey.com/Volume0/opasdata/d220001/medias/images/4117/296%7E4222419%7ERGT%7E16.JPG
30 | TPS63020DSJR | Texas Instruments | IC REG BUCK BST ADJ 3.5A 14VSON |  | 11,665 | In Stock |  | 1 | 1 | Cut Tape (CT) | 296-36491-1-ND | 2.48000 | £2.48 | 1 | U2 | TPS63020DSJR | 12 | https://www.ti.com/general/docs/suppproductinfo.tsp?distId=10 |  | - |  | Active | ROHS3 Compliant | REACH Unaffected | 1 (Unlimited) | EAR99 | 8542.39.0070 | China |  | TPS63020DSJR | Each | https://mm.digikey.com/Volume0/opasdata/d220001/medias/images/6295/296%7E4208212-3%7EDSJ%7E14.jpg
31 | RFPC-SMA27-F | GCT | SMA PCB MOUNT RA JACK |  | 7,522 | In Stock |  | 1 | 1 | Tray | 2073-RFPC-SMA27-F-ND | 1.69000 | £1.69 | 1 | J5 | RFPC-SMA27-F | 6 | https://mm.digikey.com/Volume0/opasdata/d220001/medias/docus/6130/RFPC-SMA27-F.pdf |  | - |  | Active | ROHS3 Compliant |  | Not Applicable | EAR99 | 8536.69.4010 | China |  | RFPC-SMA27-F | Each | https://mm.digikey.com/Volume0/opasdata/d220001/derivates/6/001/170/290/MFG_RFPC-SMA27-F_web%28640x640%29.jpg
32 | C0805C104K8RACTU | KEMET | CAP CER 0.1UF 10V X7R 0805 |  | 104,274 | In Stock |  | 100 | 100 | Cut Tape (CT) | 399-C0805C104K8RACTUCT-ND | 0.03800 | £3.80 | 1 |  | C0805C104K8RACTU | 21 | https://yageogroup.com/content/datasheet/asset/file/KEM_C1002_X7R_SMD |  | - |  | Active | ROHS3 Compliant | REACH Unaffected | 1 (Unlimited) | EAR99 | 8532.24.0020 | China |  | C0805C104K8RACTU | Each | https://mm.digikey.com/Volume0/opasdata/d220001/derivates/6/003/121/213/cut-tape-render_web%28640x640%29.jpg
33 | C0805C103K8RACTU | KEMET | CAP CER 10000PF 10V X7R 0805 |  | 10,909 | In Stock |  | 100 | 100 | Cut Tape (CT) | 399-14549-1-ND | 0.03730 | £3.73 | 1 |  | C0805C103K8RACTU | 21 | https://yageogroup.com/content/datasheet/asset/file/KEM_C1002_X7R_SMD |  | - |  | Active | ROHS3 Compliant | REACH Unaffected | 1 (Unlimited) | EAR99 | 8532.24.0020 | Mexico |  | C0805C103K8RACTU | Each | https://mm.digikey.com/Volume0/opasdata/d220001/derivates/6/003/121/213/cut-tape-render_web%28640x640%29.jpg
34 | SRV05-4A | SMC Diode Solutions | TVS DIODE 5VWM 17.5VC SOT23-6 |  | 56,131 | In Stock |  |  |  |  |  |  |  |  | U9 | 1655-SRV05-4ATR-ND | 24 | https://www.smc-diodes.com/propdf/SRV05-4A%20N1763%20REV.A.pdf |  | - |  | Active | ROHS3 Compliant | REACH Affected | 1 (Unlimited) | EAR99 | 8541.10.0080 | China | https://www.smc-diodes.com/uploadfile/Declaration%20Letter%20for%20EU%20REACH-3.pdf|https://www.smc-diodes.com/uploadfile/ROHS%20Declaration%20Letter-4.pdf | 1655-SRV05-4ATR-ND | Each | https://mm.digikey.com/Volume0/opasdata/d220001/medias/images/4955/1655%3BSOT23%3B%3B6.jpg
35 | CR0805-FX-1202ELF | Bourns Inc. | RES SMD 12K OHM 1% 1/8W 0805 |  | 22,709 | In Stock |  | 100 | 100 | Cut Tape (CT) | 118-CR0805-FX-1202ELFCT-ND | 0.00980 | £0.98 | 1 |  | CR0805-FX-1202ELF | 21 | https://bourns.com/docs/product-datasheets/cr.pdf?sfvrsn=574d41f6_14 |  | - |  | Active | ROHS3 Compliant | REACH Unaffected | 1 (Unlimited) | EAR99 | 8533.21.0030 | Taiwan | https://www.bourns.com/docs/Product-MDS/cr0805_mds.pdf|https://mm.digikey.com/Volume0/opasdata/d220001/medias/docus/6657/Bourns%20REACH%20247%20Jan%202025%20Statement.pdf|https://www.bourns.com/docs/rohs-cofc/crx_coc.pdf?sfvrsn=db3a74f6_10 | CR0805-FX-1202ELF | Each | https://mm.digikey.com/Volume0/opasdata/d220001/medias/images/505/CR0805-%282012-Metric%29.jpg

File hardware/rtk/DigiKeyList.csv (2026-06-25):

Quantity | Manufacturer Part Number | Customer Reference | Description
1 | TAJR105M016RNJ | C1 | Tantalum 1uF 16V 0805
2 | TAJP475K016RNJ | C2,C3 | Tantalum 4u7 16V 0805
1 | C1608X5R1A226M080AC | C5 | MLCC 22uF 10V X5R 0603
1 | MSASJ21GBB5476MTNA01 | C6 | MLCC 47uF 0805
3 | T529P106M010AAE200 | C16,C18,C20 | Kemet KO-CAP polymer tant 10uF 10V 0805
1 | DFE201610E-1R0M | L1 | TPS63020 switching inductor 1uH
1 | LQW15AN8N0G8ZD | L2 | Bias-T RF choke 8.0nH wire-wound 0402
1 | 1N4148W | D1 | Switching diode SOD-123
1 | USBLC6-2SC6 | D2 | USB ESD protection SOT-23-6
1 | BQ24075RGTR | U1 | Battery charger / power path VQFN-16
1 | TPS63020DSJR | U2 | Buck-boost regulator VSON-14
1 | STM32F765VIT6 | U3 | MCU Cortex-M7 2MB flash LQFP-100
1 | ZED-F9P-05B-00 | U4 | GNSS RTK module
1 | USB3300-EZK-TR | U8 | ULPI USB PHY QFN-32
1 | LSM6DSRXTR | U7 | IMU accel+gyro LGA-14
1 | USB4105-GF-A | J1 | USB-C receptacle
1 | B2B-PH-SM4-TB(LF)(SN) | J3 | JST PH 2-pin battery connector
1 | MEM2052-00-195-00-A | J6 | microSD card socket push-push
1 | ASTX-H11-16.000MHZ-T | Y1 | TCXO 16MHz STM32 HSE
1 | ASTX-H11-24.000MHZ-T | Y2 | TCXO 24MHz USB3300

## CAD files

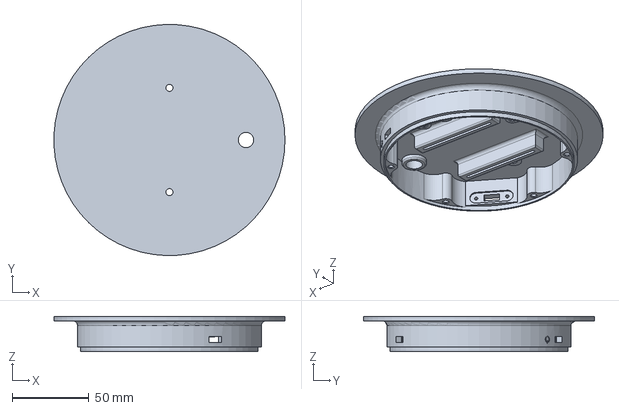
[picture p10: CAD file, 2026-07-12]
3d/GroundPlaneLowerCoverDisk-120.FCStd
150.7 x 150.7 x 23.0 mm

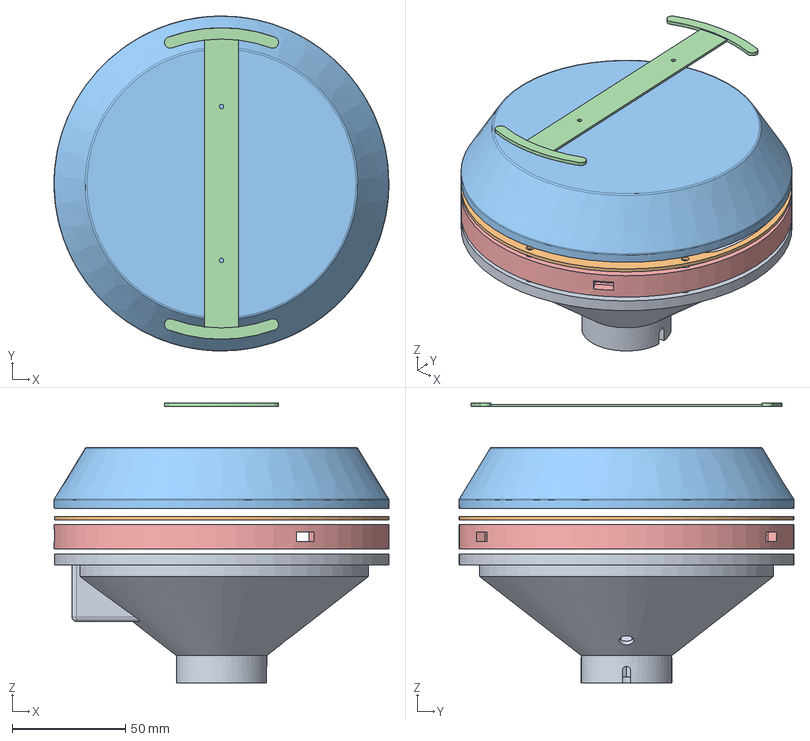
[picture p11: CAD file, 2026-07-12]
3d/AntennaCover-Brass4.FCStd
148.0 x 148.0 x 123.5 mm
BottomCover
ShimPlate
TopCover
GroundPlaneHoleMarkoutHelper
CarrierPlate

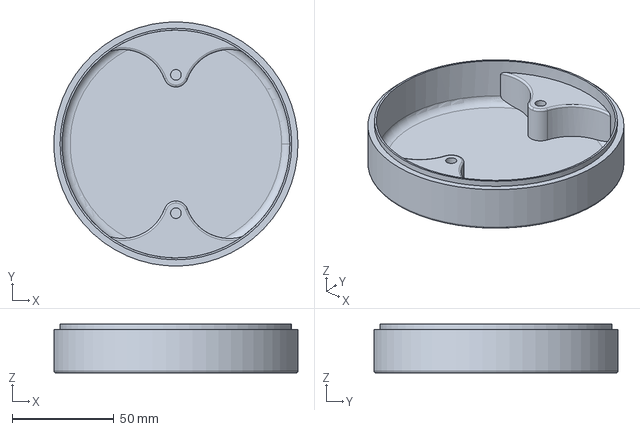
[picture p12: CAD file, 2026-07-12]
3d/AntennaCover-120.FCStd
119.9 x 120.0 x 24.0 mm

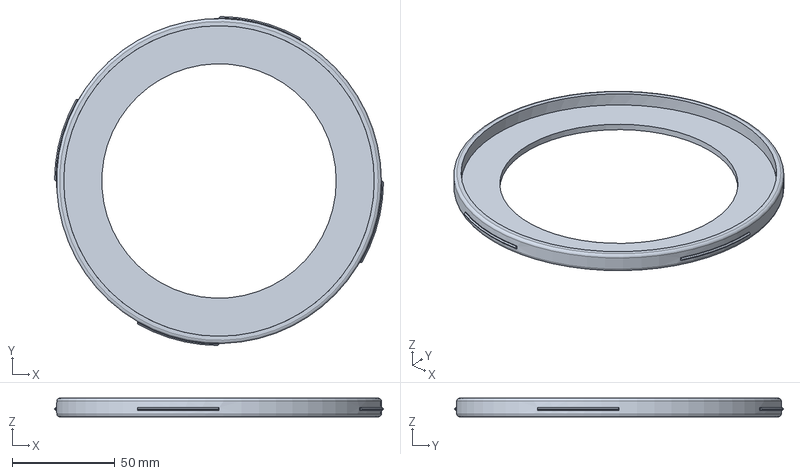
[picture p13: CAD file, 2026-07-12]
3d/GroundPlaneCoverDisk-120.FCStd
160.0 x 160.0 x 9.10 mm

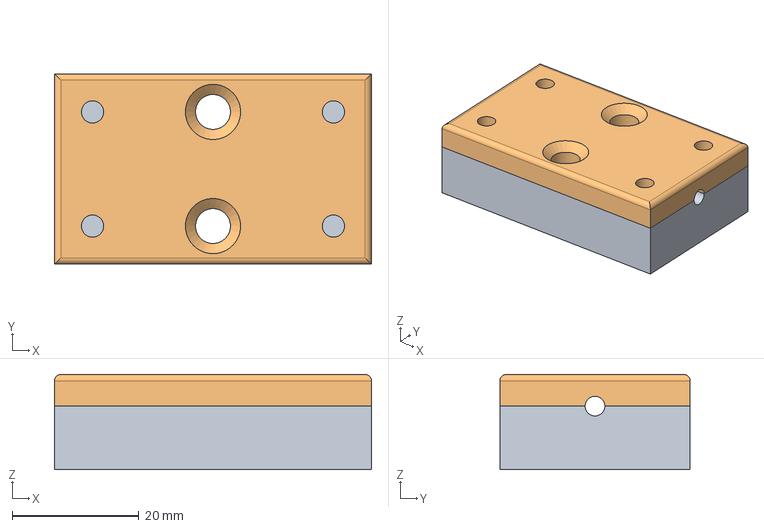
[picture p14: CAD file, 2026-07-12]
3d/RG174Clamp.FCStd
50.0 x 30.0 x 15.0 mm
LowerClamp
UpperClamp

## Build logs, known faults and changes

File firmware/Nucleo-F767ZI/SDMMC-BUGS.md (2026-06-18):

# STM32 SDMMC / FatFS Known Bugs and Fixes

This file documents root causes and fixes for CubeMX-generated SDMMC and
FatFS bugs discovered during development on the F767ZI sandbox board.
Each entry is tagged with a short ID so it can be cross-referenced from
source comments (e.g. `/* BUG-SDMMC-001 */`).

---

## BUG-SDMMC-001 — Boot crash when no SD card is inserted

**Symptom**
The board hits `Error_Handler()` immediately on every boot if no SD card is
in the slot.

**Root cause**
CubeMX generates `MX_SDMMC2_SD_Init()` which calls `HAL_SD_Init()` uncondi-
tionally. `HAL_SD_Init()` runs the full SD card power-up and enumeration
sequence (CMD0 → CMD8 → ACMD41/CMD41 → CMD2 → CMD3). If no card is present,
no response is received, the HAL returns `HAL_ERROR`, and the generated code
calls `Error_Handler()`.

**Fix**
Add a CD pin poll in `USER CODE BEGIN SDMMC2_Init 0` (the earliest USER CODE
slot, before any field assignments or HAL calls).  A single instantaneous read
is unreliable — if the card was re-inserted just before reset, the mechanical
CD contact may still be bouncing and reads HIGH even though the card is seated.
Poll for up to 50 ms so any bounce settles before deciding:

```c
/* USER CODE BEGIN SDMMC2_Init 0 */
{
    uint32_t t = HAL_GetTick();
    while (HAL_GPIO_ReadPin(SDMMC_CD_GPIO_Port, SDMMC_CD_Pin) == GPIO_PIN_SET) {
        if ((HAL_GetTick() - t) >= 50U)
            return;  /* No card after 50 ms — skip init. */
    }
}
/* USER CODE END SDMMC2_Init 0 */
```

`HAL_GetTick()` works here because `HAL_Init()` has already been called.
The 50 ms overhead only applies when no card is present.  When a card IS
seated the CD contact asserts within a few ms (typical contact bounce < 10 ms)
and the poll exits immediately.  When a card was just inserted during reset,
the 50 ms window lets the contact settle before the check completes.

The companion fix is BUG-SDMMC-005: `BSP_SD_Init()` (app.c override) never
calls `HAL_SD_Init()`.  Instead, `sd_late_init()` (called from `app_init()`
after `HAL_Delay(500)`) is the second and final chance to enumerate the card
while OTA is still not running.  If the card has not been enumerated by the
time `f_mount()` calls `BSP_SD_Init()`, `BSP_SD_Init()` returns `MSD_ERROR`
immediately without blocking.

**Affected section**
`Core/Src/main.c` → `MX_SDMMC2_SD_Init()`

---

## BUG-SDMMC-005 — Double HAL_SD_Init() blocks OTA for seconds on some cards

**Symptom**
When a card is present at boot and `f_mount()` is subsequently called, OTA
packets stop flowing for several seconds (or permanently if the card's ACMD41
loop takes long enough to let an in-progress TX complete while blocked).

**Root cause**
At boot, `MX_SDMMC2_SD_Init()` calls `HAL_SD_Init()` (after the CD-pin guard
passes), which runs the full SD power-up enumeration: CMD0 → CMD8 → ACMD41
loop → CMD2 → CMD3. This sets `hsd2.State = HAL_SD_STATE_READY`.

Later, when `f_mount()` is called from application code, FatFS calls
`disk_initialize()` → `BSP_SD_Init()`. The original `BSP_SD_Init()` override
(in app.c, replacing the `__weak` version) called `HAL_SD_Init()` again —
another full ACMD41 enumeration sequence. On the same card used during
development (test card) this second enumeration is fast (<100 ms), so OTA
was not visibly affected. On a different card (different brand or speed class),
the ACMD41 loop can take up to `SDMMC_CMDTIMEOUT` (5000 ms) to complete.
This blocks `app_loop()` during `app_tests()`, causing OTA to stall.

**Fix**
In `BSP_SD_Init()`, check `hsd2.State == HAL_SD_STATE_READY`. If true, the
card was already enumerated at boot; skip `HAL_SD_Init()` entirely and only
send CMD13 (GetCardState) to confirm the card is still responsive (~100 µs).
Only call `HAL_SD_Init()` when `hsd2.State == HAL_SD_STATE_RESET` (i.e., no
card was present at boot and this is the first-ever init).

```c
uint8_t BSP_SD_Init(void)
{
    extern SD_HandleTypeDef hsd2;
    if (BSP_SD_IsDetected() != SD_PRESENT)
        return MSD_ERROR_SD_NOT_PRESENT;
    if (hsd2.State == HAL_SD_STATE_READY) {
        return (HAL_SD_GetCardState(&hsd2) == HAL_SD_CARD_TRANSFER) ? MSD_OK : MSD_ERROR;
    }
    if (HAL_SD_Init(&hsd2) != HAL_OK) {
        HAL_SD_DeInit(&hsd2);
        return MSD_ERROR;
    }
    return MSD_OK;
}
```

**Affected section**
`Core/Src/app.c` → `BSP_SD_Init()` override

---

## BUG-SDMMC-002 — Card does not remount after eject and reinsertion

**Symptom**
After a card is physically removed and reinserted, `f_mount()` fails or the
filesystem is not accessible. The problem does not occur on a fresh power
cycle.

**Root cause**
*(Under investigation — to be confirmed with FatFS middleware enabled.)*
Likely candidates from prior experience with this hardware:
- `HAL_SD_Init()` is not re-called after insertion; the HAL handle state is
  left in `HAL_SD_STATE_READY` referencing the old card's RCA/CID.
- The SDMMC peripheral is not fully reset between eject and re-init; residual
  clock gating or CMD/DAT line state confuses the new card's power-up.
- FatFS `f_mount()` with `opt=1` (immediate mount) does not trigger a fresh
  `HAL_SD_Init()` if the HAL handle is already initialised.

**Fix**
*(Pending — to be documented once confirmed.)*

**Affected section**
TBD — likely `MX_SDMMC2_SD_Init()`, application card-detect handler, and/or
FatFS `diskio.c`.

---

## BUG-SDMMC-003 — HAL_SD_ERROR_RX_OVERRUN in polling mode (ClockDiv=0)

**Symptom**
`f_mount()` returns `FR_DISK_ERR (1)`. Adding `hsd2.ErrorCode` logging shows
`0x00000020 = HAL_SD_ERROR_RX_OVERRUN` — the SDMMC RX FIFO overflowed during
the first sector read.

**Root cause**
STM32F7 errata (ES0334): the SDMMC hardware flow-control feature is not
correctly implemented and must not be used. Without hardware flow control, the
CPU must drain the RX FIFO fast enough by polling to prevent overflow.
At ClockDiv=0 the SDMMC_CK is 24 MHz; in 4-bit mode data arrives at 12 MB/s,
filling the 128-byte FIFO in ~10.7 μs. Any interrupt latency or pipeline stall
can cause an overrun before the polling loop drains the FIFO.

**Fix**
Superseded by BUG-SDMMC-004: switching to 1-bit mode (which skips
`HAL_SD_ConfigWideBusOperation`) removes the 4-bit FIFO pressure entirely.
In 1-bit mode the FIFO fills 4× slower for the same SDMMC_CK, so ClockDiv=0
(24 MHz, ~3 MB/s) is safe in polling mode without any clock reduction needed.

If 4-bit mode is ever restored (once wiring is fixed), keep ClockDiv ≥ 6
(SDMMC_CK ≤ 8 MHz) for polling safety, or switch to the DMA template.

**DMA note (if 4-bit + full speed is ever needed)**
Enable "Use dma template" in CubeMX FatFS settings and configure DMA2 Stream 0
Channel 11 for SDMMC2. DMA removes the FIFO-drain constraint entirely and
allows ClockDiv=0 in 4-bit mode. Note: F7 D-Cache is enabled — add
`SCB_InvalidateDCache_by_Addr()` after DMA reads and
`SCB_CleanDCache_by_Addr()` before DMA writes in `sd_diskio.c` USER CODE
sections.

**Affected section**
`Core/Src/main.c` → `MX_SDMMC2_SD_Init()`

---

## BUG-SDMMC-004 — DATA_CRC_FAIL in 4-bit mode; D1/D2/D3 wiring fault on SD BOB

**Symptom**
After fixing BUG-SDMMC-003 (ClockDiv), `f_mount()` still returns
`FR_DISK_ERR (1)` with `hsd2.ErrorCode = 0x00000002 (HAL_SD_ERROR_DATA_CRC_FAIL)`.
Switching to 1-bit mode (override `BSP_SD_Init()` to skip
`HAL_SD_ConfigWideBusOperation()`) makes everything work: mount, write, read
all succeed.

**Root cause**
4-bit data CRC is calculated across all four DAT lines simultaneously by the
SDMMC hardware. A floating or disconnected DAT1, DAT2, or DAT3 line causes
corrupted data on that lane, failing the CRC on every block read. CMD/response
(which run on the CMD line only, in 1-bit mode during init) are unaffected, so
`HAL_SD_Init()` and `HAL_SD_ConfigWideBusOperation()` both return `HAL_OK`
— the fault is invisible until the first actual data transfer in 4-bit mode.

Affected pins: PG10 (SDMMC2_D1), PG11 (SDMMC2_D2), PG12 (SDMMC2_D3).
Check wiring from these Morpho header pins to the SD breakout board.

**Fix**
Inspect and re-seat the D1/D2/D3 wires on the SD breakout board. Once fixed,
remove the `BSP_SD_Init()` override in `Core/Src/app.c` to restore 4-bit mode.

As a workaround until the wiring is fixed (or if 1-bit mode is sufficient for
the application — ~570 KB/s at ClockDiv=40 is far more than needed for RTCM
logging), the override in `app.c` forces 1-bit mode:

```c
uint8_t BSP_SD_Init(void)  /* strong override of __weak in bsp_driver_sd.c */
{
    extern SD_HandleTypeDef hsd2;
    if (BSP_SD_IsDetected() != SD_PRESENT)
        return MSD_ERROR_SD_NOT_PRESENT;
    return (HAL_SD_Init(&hsd2) == HAL_OK) ? MSD_OK : MSD_ERROR;
}
```

**Affected section**
`FATFS/Target/bsp_driver_sd.c` → `BSP_SD_Init()` (override in
`Core/Src/app.c`)

---

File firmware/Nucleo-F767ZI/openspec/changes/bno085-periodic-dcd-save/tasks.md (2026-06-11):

## 1. Constants and declaration

- [x] 1.1 Add `BNO085_COMMAND_DCD_PERIODIC_SAVE` (`0x09`) constant to
      `bno085.h`, alongside `BNO085_COMMAND_SAVE_DCD` and
      `BNO085_COMMAND_ME_CALIBRATION`.
- [x] 1.2 Declare `bno085_set_periodic_dcd_save(bno085_t *p, uint8_t
      enable)` in `bno085.h` with a Doxygen comment documenting the
      `{enable ? 0x00 : 0x01, ...}` parameter mapping and the no-response
      behaviour per SH-2 Reference Manual section 6.4.7.

## 2. Implementation

- [x] 2.1 Implement `bno085_set_periodic_dcd_save()` in `bno085.c`:
      build `params = {enable ? 0x00 : 0x01, 0,0,0,0,0,0,0,0}`, call
      `bno085_send_command(p, BNO085_COMMAND_DCD_PERIODIC_SAVE, params)`,
      and return its result directly (no
      `bno085_read_command_response()` call).

## 3. Wire-up and review

- [x] 3.1 In `Core/Src/app.c`'s `app_init()`, after the existing
      `bno085_set_me_calibration()` call, add a call to
      `bno085_set_periodic_dcd_save(&bno, 1)` and print
      `bno085_set_periodic_dcd_save OK` (or the failure status) over
      USART3, following the existing feature-enable print style.
- [x] 3.2 Bench-test on hardware: verify
      `bno085_set_periodic_dcd_save OK` is printed at startup, and
      observe whether `rv: status` / `mag: status` change behaviour
      (over a longer run, and/or after a power cycle) compared to the
      stuck `status=0` baseline from bno085-magnetic-field-report.

      Result: `bno085_set_periodic_dcd_save OK` printed at startup,
      confirming the command sends successfully. `mag: status` remained
      stuck at `0` throughout a ~30-line run (field magnitude stable at
      ~38-40uT). One `seq` discontinuity (229 -> 7) was observed
      mid-run, possibly an internal sensor hub reset, but `status`
      stayed `0` on both sides of it. Periodic DCD save alone does not
      unstick the calibration confidence classifier; left as further
      follow-up (e.g. Simple/Turntable Calibration command 0x0C, which
      requires a structured 180-degree motion).

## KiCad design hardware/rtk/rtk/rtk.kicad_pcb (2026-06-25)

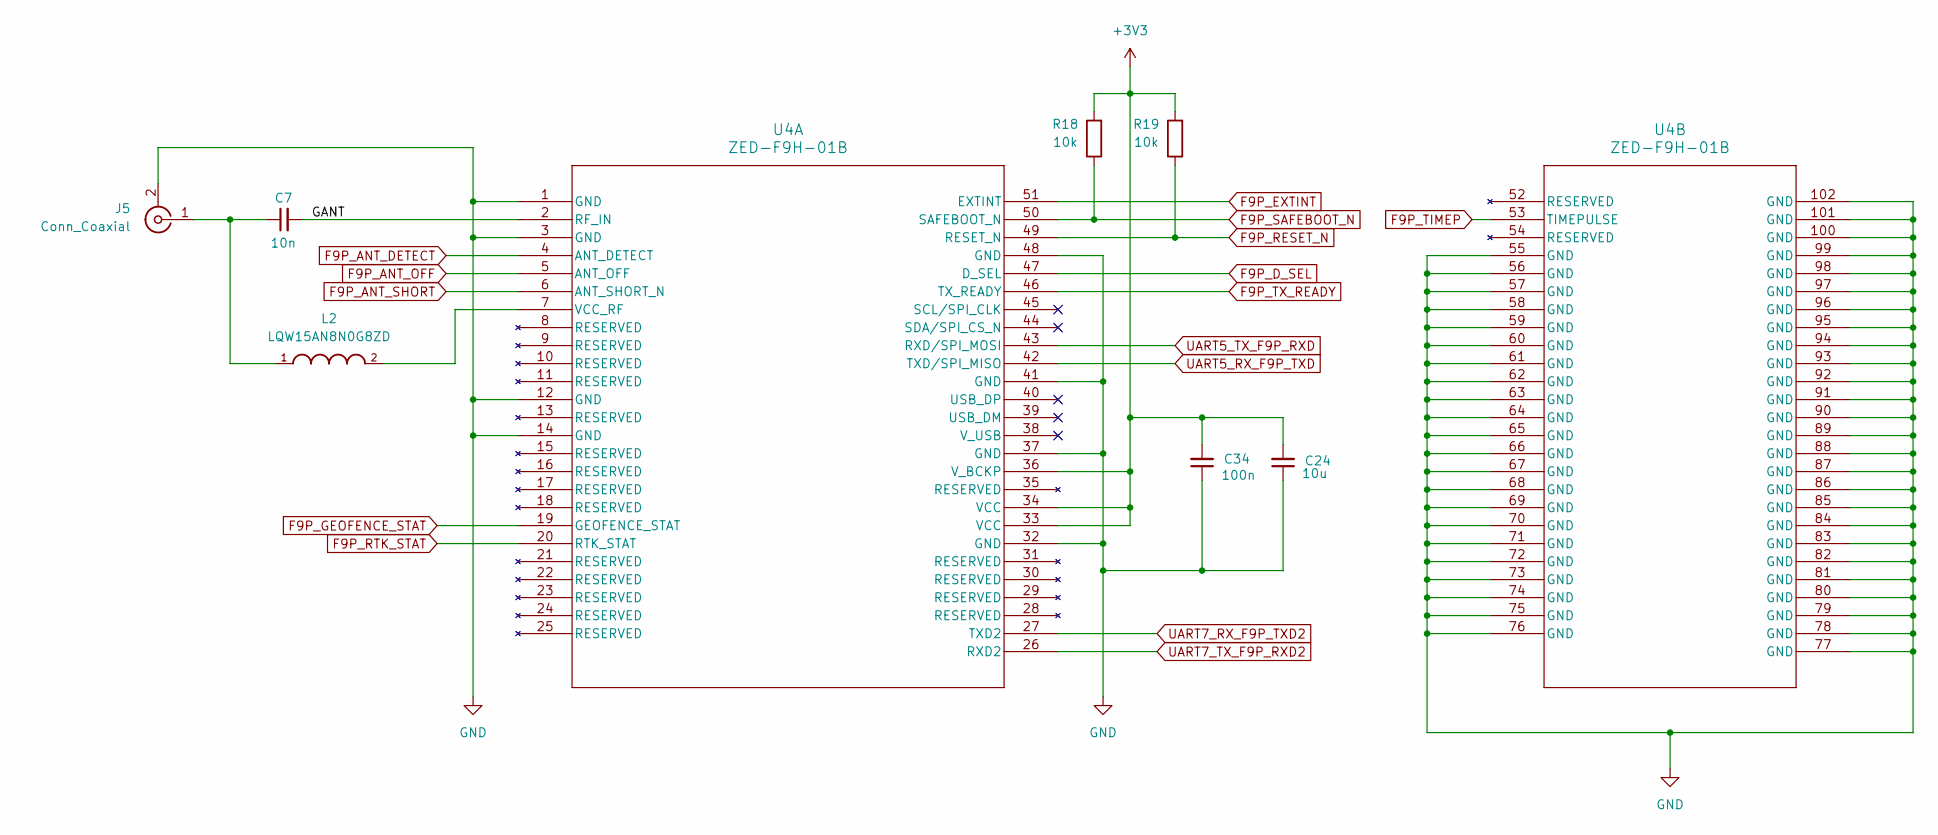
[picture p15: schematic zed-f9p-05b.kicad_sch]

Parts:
C7: 10n; C_0603_1608Metric_Pad1.08x0.95mm_HandSolder
C24: 10u; C_0805_2012Metric_Pad1.18x1.45mm_HandSolder
C34: 100n; C_0603_1608Metric_Pad1.08x0.95mm_HandSolder
J5: Conn_Coaxial; SMA_BAT_Wireless_BWSMA-KWE-Z001
L2: LQW15AN8N0G8ZD; INDC1006X60N
R18, R19: 10k; R_0805_2012Metric_Pad1.20x1.40mm_HandSolder
U4: ZED-F9H-01B; MOD54_ZED-F9H_UBL

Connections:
+3V3: C24.2, C34.2, R18.2, R19.2, U4.33 (VCC), U4.34 (VCC), U4.36 (V_BCKP); also elsewhere on the board
/ZED-F9P-05B/GANT: C7.2, U4.2 (RF_IN)
F9P_ANT_DETECT: U4.4 (ANT_DETECT); also elsewhere on the board
F9P_ANT_OFF: U4.5 (ANT_OFF); also elsewhere on the board
F9P_ANT_SHORT: U4.6 (ANT_SHORT_N); also elsewhere on the board
F9P_D_SEL: U4.47 (D_SEL); also elsewhere on the board
F9P_EXTINT: U4.51 (EXTINT); also elsewhere on the board
F9P_GEOFENCE_STAT: U4.19 (GEOFENCE_STAT); also elsewhere on the board
F9P_RESET_N: R19.1, U4.49 (RESET_N); also elsewhere on the board
F9P_RTK_STAT: U4.20 (RTK_STAT); also elsewhere on the board
F9P_SAFEBOOT_N: R18.1, U4.50 (SAFEBOOT_N); also elsewhere on the board
F9P_TIMEP: U4.53 (TIMEPULSE); also elsewhere on the board
F9P_TX_READY: U4.46 (TX_READY); also elsewhere on the board
GND: C24.1, C34.1, J5.2 (Ext), U4.1 (GND), U4.3 (GND), U4.12 (GND), U4.14 (GND), U4.32 (GND), U4.37 (GND), U4.41 (GND), U4.48 (GND), U4.55 (GND), U4.56 (GND), U4.57 (GND), U4.58 (GND), U4.59 (GND), U4.60 (GND), U4.61 (GND), U4.62 (GND), U4.63 (GND), U4.64 (GND), U4.65 (GND), U4.66 (GND), U4.67 (GND), U4.68 (GND), U4.69 (GND), U4.70 (GND), U4.71 (GND), U4.72 (GND), U4.73 (GND), U4.74 (GND), U4.75 (GND), U4.76 (GND), U4.77 (GND), U4.78 (GND), U4.79 (GND), U4.80 (GND), U4.81 (GND), U4.82 (GND), U4.83 (GND), U4.84 (GND), U4.85 (GND), U4.86 (GND), U4.87 (GND), U4.88 (GND), U4.89 (GND), U4.90 (GND), U4.91 (GND), U4.92 (GND), U4.93 (GND), U4.94 (GND), U4.95 (GND), U4.96 (GND), U4.97 (GND), U4.98 (GND), U4.99 (GND), U4.100 (GND), U4.101 (GND), U4.102 (GND); also elsewhere on the board
unnamed: C7.1, J5.1 (In), L2.1
unnamed: L2.2, U4.7 (VCC_RF)
UART5_RX_F9P_TXD: U4.42 (TXD/SPI_MISO); also elsewhere on the board
UART5_TX_F9P_RXD: U4.43 (RXD/SPI_MOSI); also elsewhere on the board
UART7_RX_F9P_TXD2: U4.27 (TXD2); also elsewhere on the board
UART7_TX_F9P_RXD2: U4.26 (RXD2); also elsewhere on the board

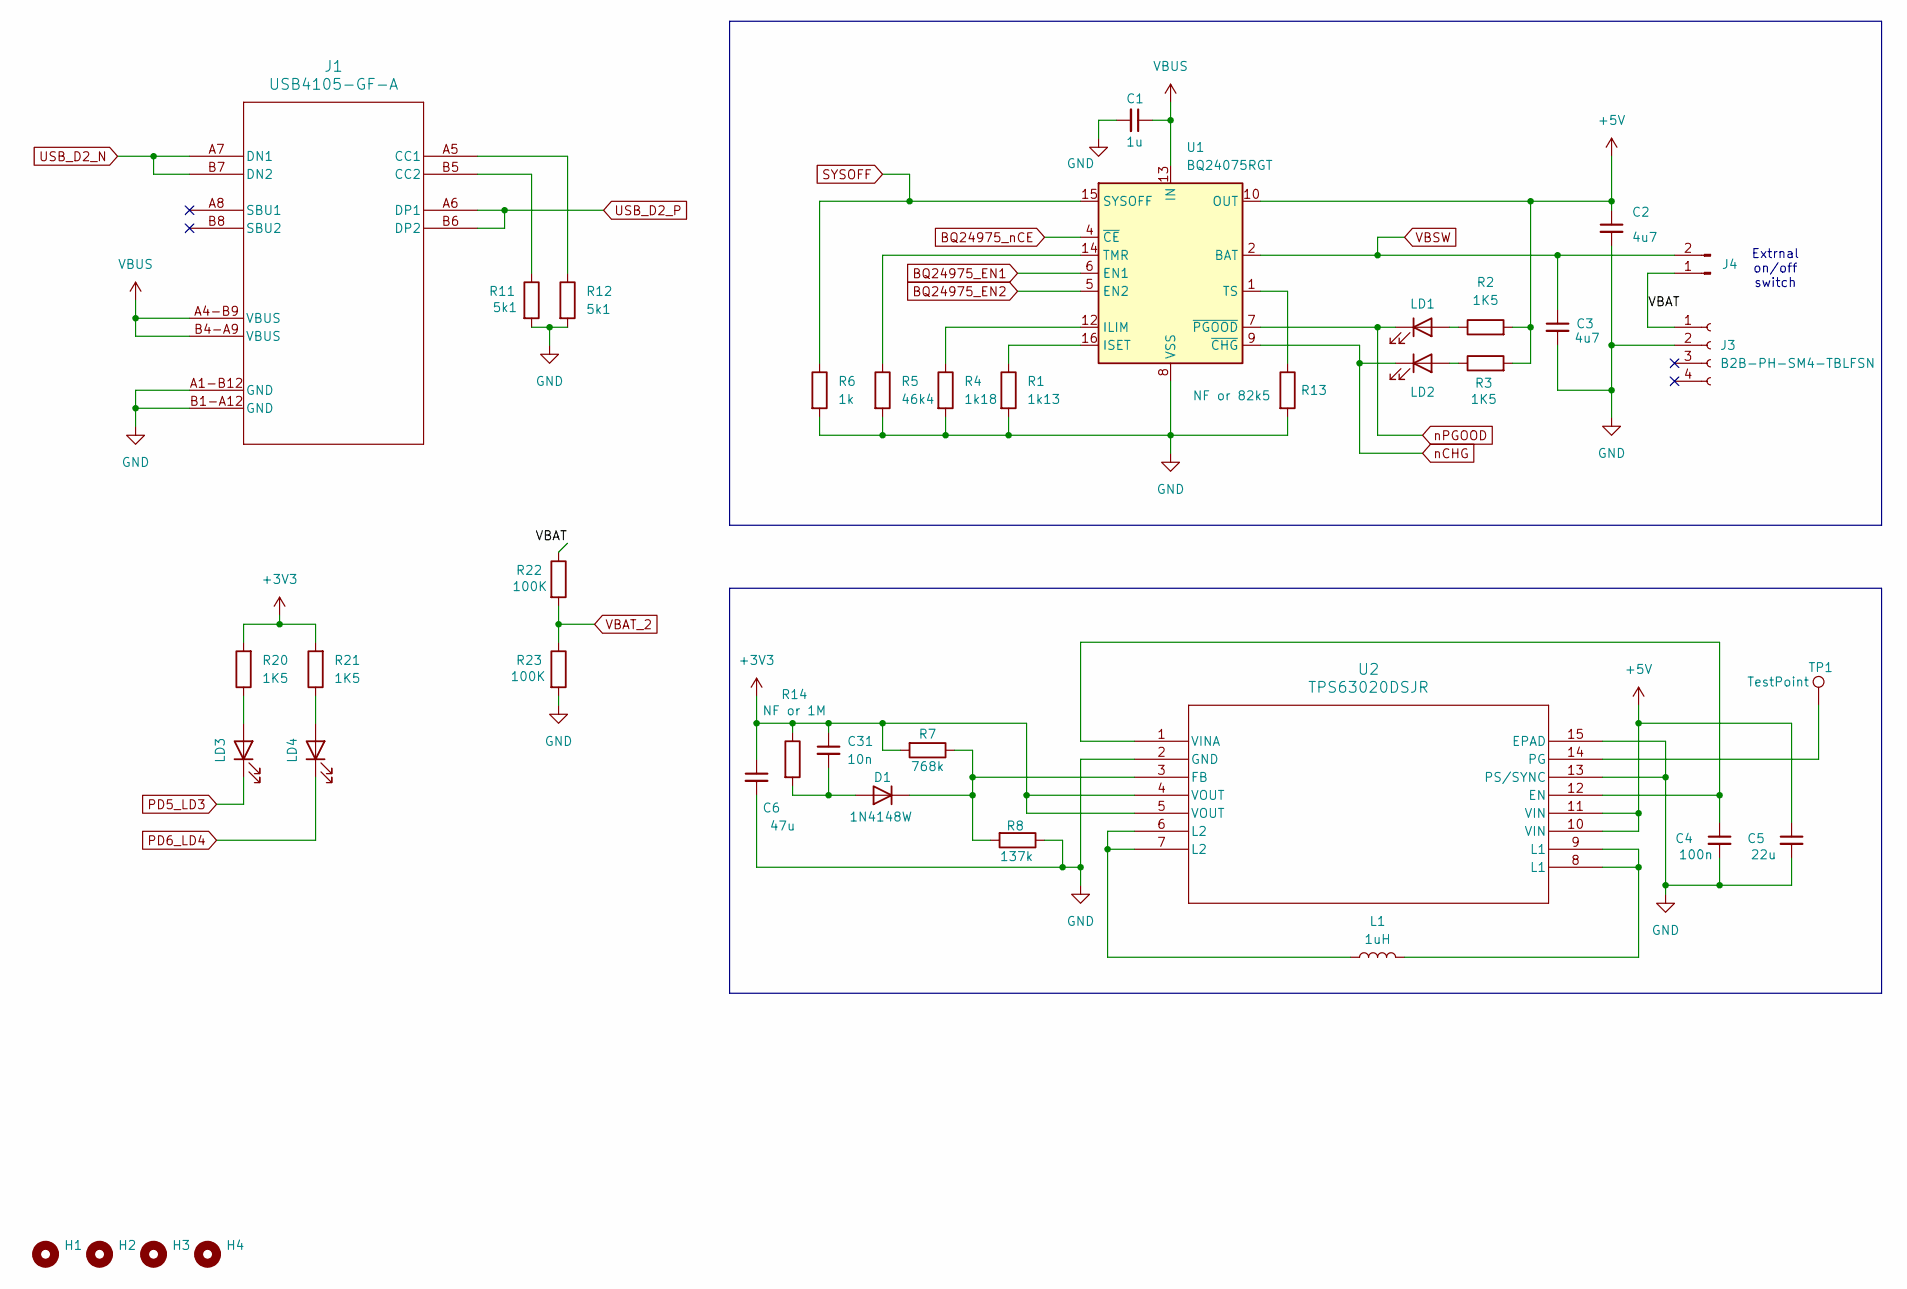
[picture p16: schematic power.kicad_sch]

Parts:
C1: 1u; C_0805_2012Metric_Pad1.18x1.45mm_HandSolder
C2, C3: 4u7; C_0805_2012Metric_Pad1.18x1.45mm_HandSolder
C4: 100n; C_0603_1608Metric_Pad1.08x0.95mm_HandSolder
C5: 22u; C_0603_1608Metric_Pad1.08x0.95mm_HandSolder
C6: 47u; C_0805_2012Metric_Pad1.18x1.45mm_HandSolder
C31: 10n; C_0805_2012Metric_Pad1.18x1.45mm_HandSolder
D1: 1N4148W; D_SOD-123
H1, H2, H3, H4: MountingHole; MountingHole_2.7mm
J1: USB4105-GF-A; USB4105_GCT
J3: B2B-PH-SM4-TBLFSN; CONN_B2B-PH-SM4-TBLFSN_JST
J4: Conn_01x02_Pin; PinHeader_1x02_P2.54mm_Vertical
L1: 1uH; IND_DFE2016_2X1P6_MUR
LD1, LD2, LD3, LD4: LED; LED_0805_2012Metric_Pad1.15x1.40mm_HandSolder
R1: 1k13; R_0805_2012Metric_Pad1.20x1.40mm_HandSolder
R2, R3, R20, R21: 1K5; R_0805_2012Metric_Pad1.20x1.40mm_HandSolder
R4: 1k18; R_0805_2012Metric_Pad1.20x1.40mm_HandSolder
R5: 46k4; R_0805_2012Metric_Pad1.20x1.40mm_HandSolder
R6: 1k; R_0805_2012Metric_Pad1.20x1.40mm_HandSolder
R7: 768k; R_0805_2012Metric_Pad1.20x1.40mm_HandSolder
R8: 137k; R_0805_2012Metric_Pad1.20x1.40mm_HandSolder
R11, R12: 5k1; R_0805_2012Metric_Pad1.20x1.40mm_HandSolder
R13: NF or 82k5; R_0805_2012Metric_Pad1.20x1.40mm_HandSolder
R14: NF or 1M; R_0805_2012Metric_Pad1.20x1.40mm_HandSolder
R22, R23: 100K; R_0805_2012Metric_Pad1.20x1.40mm_HandSolder
TP1: TestPoint; PinHeader_1x01_P2.54mm_Vertical
U1: BQ24075RGT; VQFN-16-1EP_3x3mm_P0.5mm_EP1.6x1.6mm
U2: TPS63020DSJR; DSJ14_2P85X1P58

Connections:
+3V3: C6.1, C31.1, R7.2, R14.1, R20.2, R21.2, U2.4 (VOUT), U2.5 (VOUT); also elsewhere on the board
+5V: C2.1, C5.1, R2.2, R3.2, U1.10 (OUT), U1.11 (OUT), U2.10 (VIN), U2.11 (VIN)
/Power/VBAT: J3.1, J4.1, R22.1
BQ24975_EN1: U1.6 (EN1); also elsewhere on the board
BQ24975_EN2: U1.5 (EN2); also elsewhere on the board
BQ24975_nCE: U1.4 (~CE); also elsewhere on the board
GND: C1.2, C2.2, C3.2, C4.2, C5.2, C6.2, J1.A1-B12 (GND), J1.B1-A12 (GND), J3.2, R1.2, R4.2, R5.2, R6.2, R8.1, R11.2, R12.2, R13.2, R23.2, U1.8 (VSS), U1.17 (VSS), U2.2 (GND), U2.13 (PS/SYNC), U2.15 (EPAD); also elsewhere on the board
unnamed: C31.2, D1.2 (A), R14.2
unnamed: D1.1 (K), R7.1, R8.2, U2.3 (FB)
unnamed: J1.A5 (CC1), R12.1
unnamed: J1.B5 (CC2), R11.1
unnamed: L1.1, U2.6 (L2), U2.7 (L2)
unnamed: L1.2, U2.8 (L1), U2.9 (L1)
unnamed: LD1.2 (A), R2.1
unnamed: LD2.2 (A), R3.1
unnamed: LD3.2 (A), R20.1
unnamed: LD4.2 (A), R21.1
unnamed: R4.1, U1.12 (ILIM)
unnamed: R1.1, U1.16 (ISET)
unnamed: R5.1, U1.14 (TMR)
unnamed: R13.1, U1.1 (TS)
unnamed: C4.1, U2.1 (VINA), U2.12 (EN)
unnamed: TP1.1 (1_1), U2.14 (PG)
PD5_LD3: LD3.1 (K); also elsewhere on the board
PD6_LD4: LD4.1 (K); also elsewhere on the board
SYSOFF: R6.1, U1.15 (SYSOFF); also elsewhere on the board
USB_D2_N: J1.A7 (DN1), J1.B7 (DN2); also elsewhere on the board
USB_D2_P: J1.A6 (DP1), J1.B6 (DP2); also elsewhere on the board
VBAT_2: R22.2, R23.1; also elsewhere on the board
VBSW: C3.1, J4.2, U1.2 (BAT), U1.3 (BAT)
VBUS: C1.1, J1.A4-B9 (VBUS), J1.B4-A9 (VBUS), U1.13 (IN); also elsewhere on the board
nCHG: LD2.1 (K), U1.9 (~CHG); also elsewhere on the board
nPGOOD: LD1.1 (K), U1.7 (~PGOOD); also elsewhere on the board

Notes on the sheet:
Extrnal on/off switch

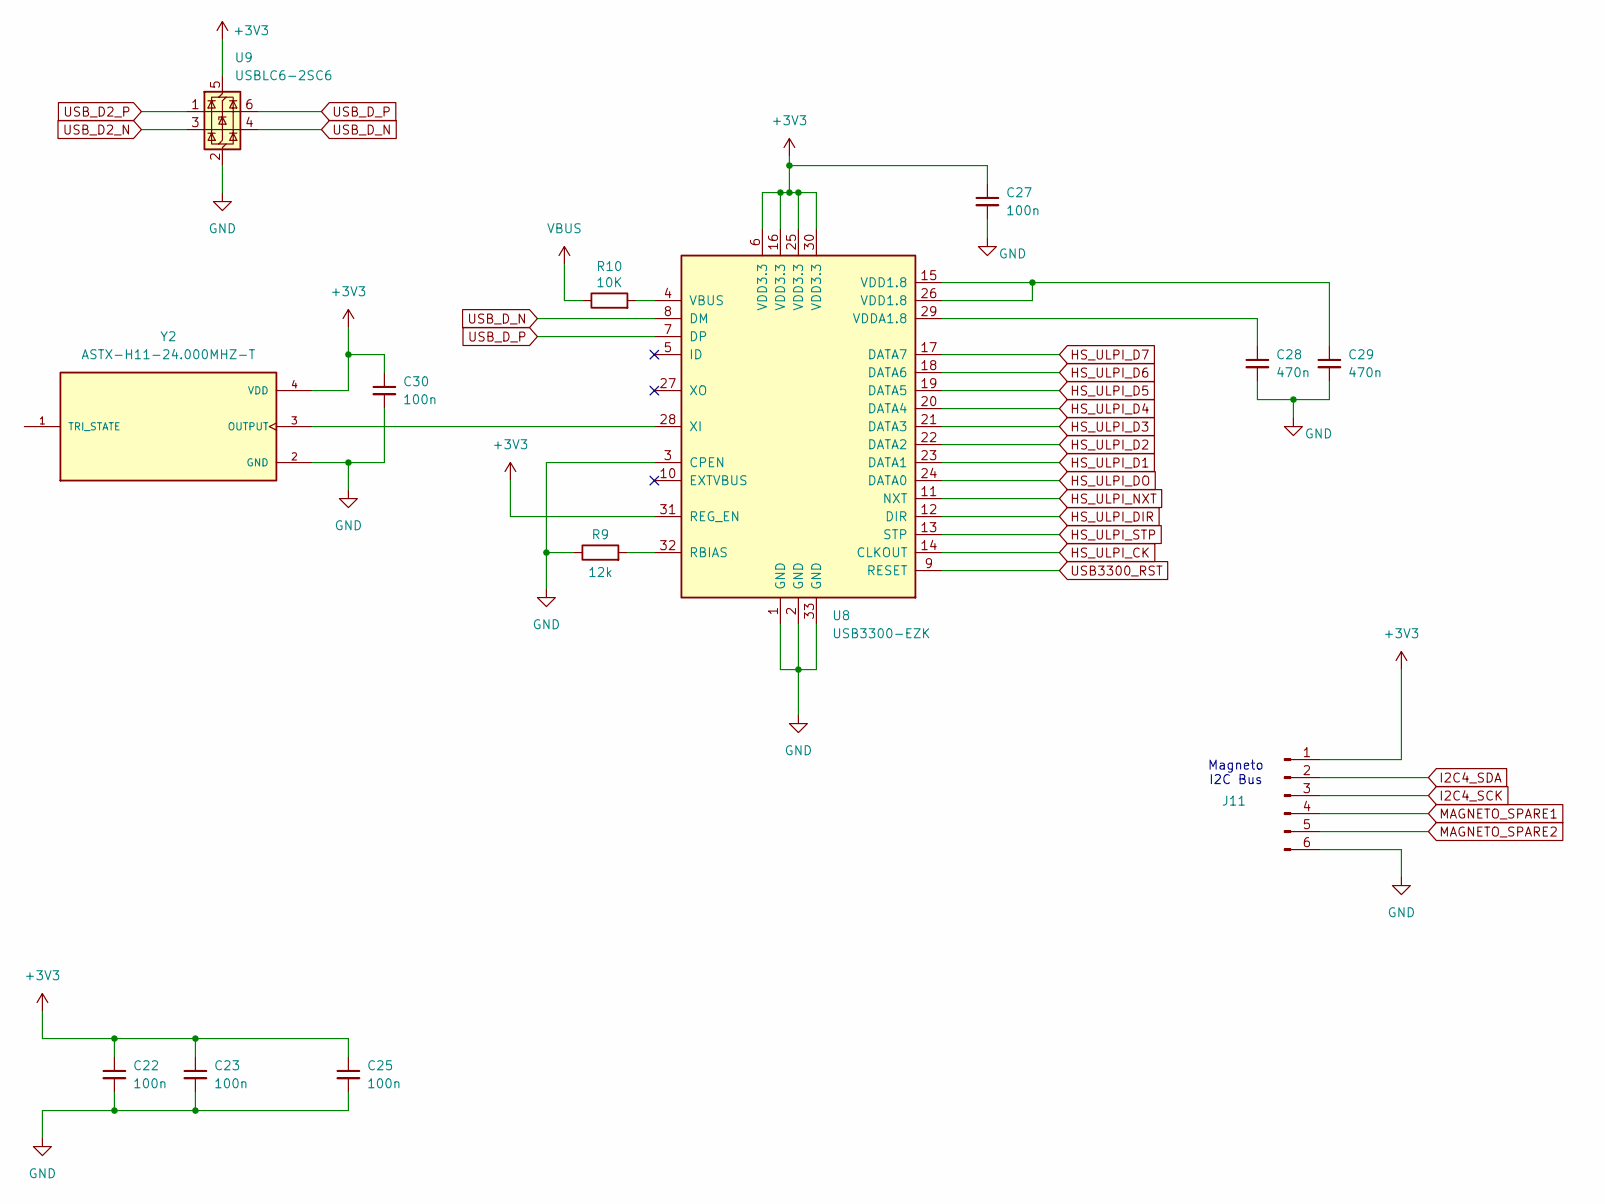
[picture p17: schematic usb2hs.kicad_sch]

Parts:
C22, C23, C25, C27, C30: 100n; C_0805_2012Metric_Pad1.18x1.45mm_HandSolder
C28, C29: 470n; C_0805_2012Metric_Pad1.18x1.45mm_HandSolder
J11: Conn_01x06_Pin; PinHeader_1x06_P2.54mm_Vertical
R9: 12k; R_0805_2012Metric_Pad1.20x1.40mm_HandSolder
R10: 10K; R_0805_2012Metric_Pad1.20x1.40mm_HandSolder
U8: USB3300-EZK; QFN-32-1EP_5x5mm_P0.5mm_EP3.45x3.45mm
U9: USBLC6-2SC6; SOT-23-6
Y2: ASTX-H11-24.000MHZ-T; XTAL_ASTX-H11-16.000MHZ-T; PARTREV 05.13.15

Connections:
+3V3: C22.1, C23.1, C25.1, C27.1, C30.1, J11.1, U8.6 (VDD3.3), U8.16 (VDD3.3), U8.25 (VDD3.3), U8.30 (VDD3.3), U8.31 (REG_EN), U9.5 (VBUS), Y2.4 (VDD); also elsewhere on the board
GND: C22.2, C23.2, C25.2, C27.2, C28.2, C29.2, C30.2, J11.6, R9.1, U8.1 (GND), U8.2 (GND), U8.3 (CPEN), U8.33 (GND), U9.2 (GND), Y2.2 (GND); also elsewhere on the board
HS_ULPI_CK: U8.14 (CLKOUT); also elsewhere on the board
HS_ULPI_D1: U8.23 (DATA1); also elsewhere on the board
HS_ULPI_D2: U8.22 (DATA2); also elsewhere on the board
HS_ULPI_D3: U8.21 (DATA3); also elsewhere on the board
HS_ULPI_D4: U8.20 (DATA4); also elsewhere on the board
HS_ULPI_D5: U8.19 (DATA5); also elsewhere on the board
HS_ULPI_D6: U8.18 (DATA6); also elsewhere on the board
HS_ULPI_D7: U8.17 (DATA7); also elsewhere on the board
HS_ULPI_DIR: U8.12 (DIR); also elsewhere on the board
HS_ULPI_DO: U8.24 (DATA0); also elsewhere on the board
HS_ULPI_NXT: U8.11 (NXT); also elsewhere on the board
HS_ULPI_STP: U8.13 (STP); also elsewhere on the board
I2C4_SCK: J11.3; also elsewhere on the board
I2C4_SDA: J11.2; also elsewhere on the board
MAGNETO_SPARE1: J11.4; also elsewhere on the board
MAGNETO_SPARE2: J11.5; also elsewhere on the board
unnamed: C29.1, U8.15 (VDD1.8), U8.26 (VDD1.8)
unnamed: R9.2, U8.32 (RBIAS)
unnamed: R10.2, U8.4 (VBUS)
unnamed: C28.1, U8.29 (VDDA1.8)
unnamed: U8.28 (XI), Y2.3 (OUTPUT)
USB3300_RST: U8.9 (RESET); also elsewhere on the board
USB_D2_N: U9.3 (I/O2); also elsewhere on the board
USB_D2_P: U9.1 (I/O1); also elsewhere on the board
USB_D_N: U8.8 (DM), U9.4 (I/O2)
USB_D_P: U8.7 (DP), U9.6 (I/O1)
VBUS: R10.1; also elsewhere on the board

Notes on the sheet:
Magneto I2C Bus

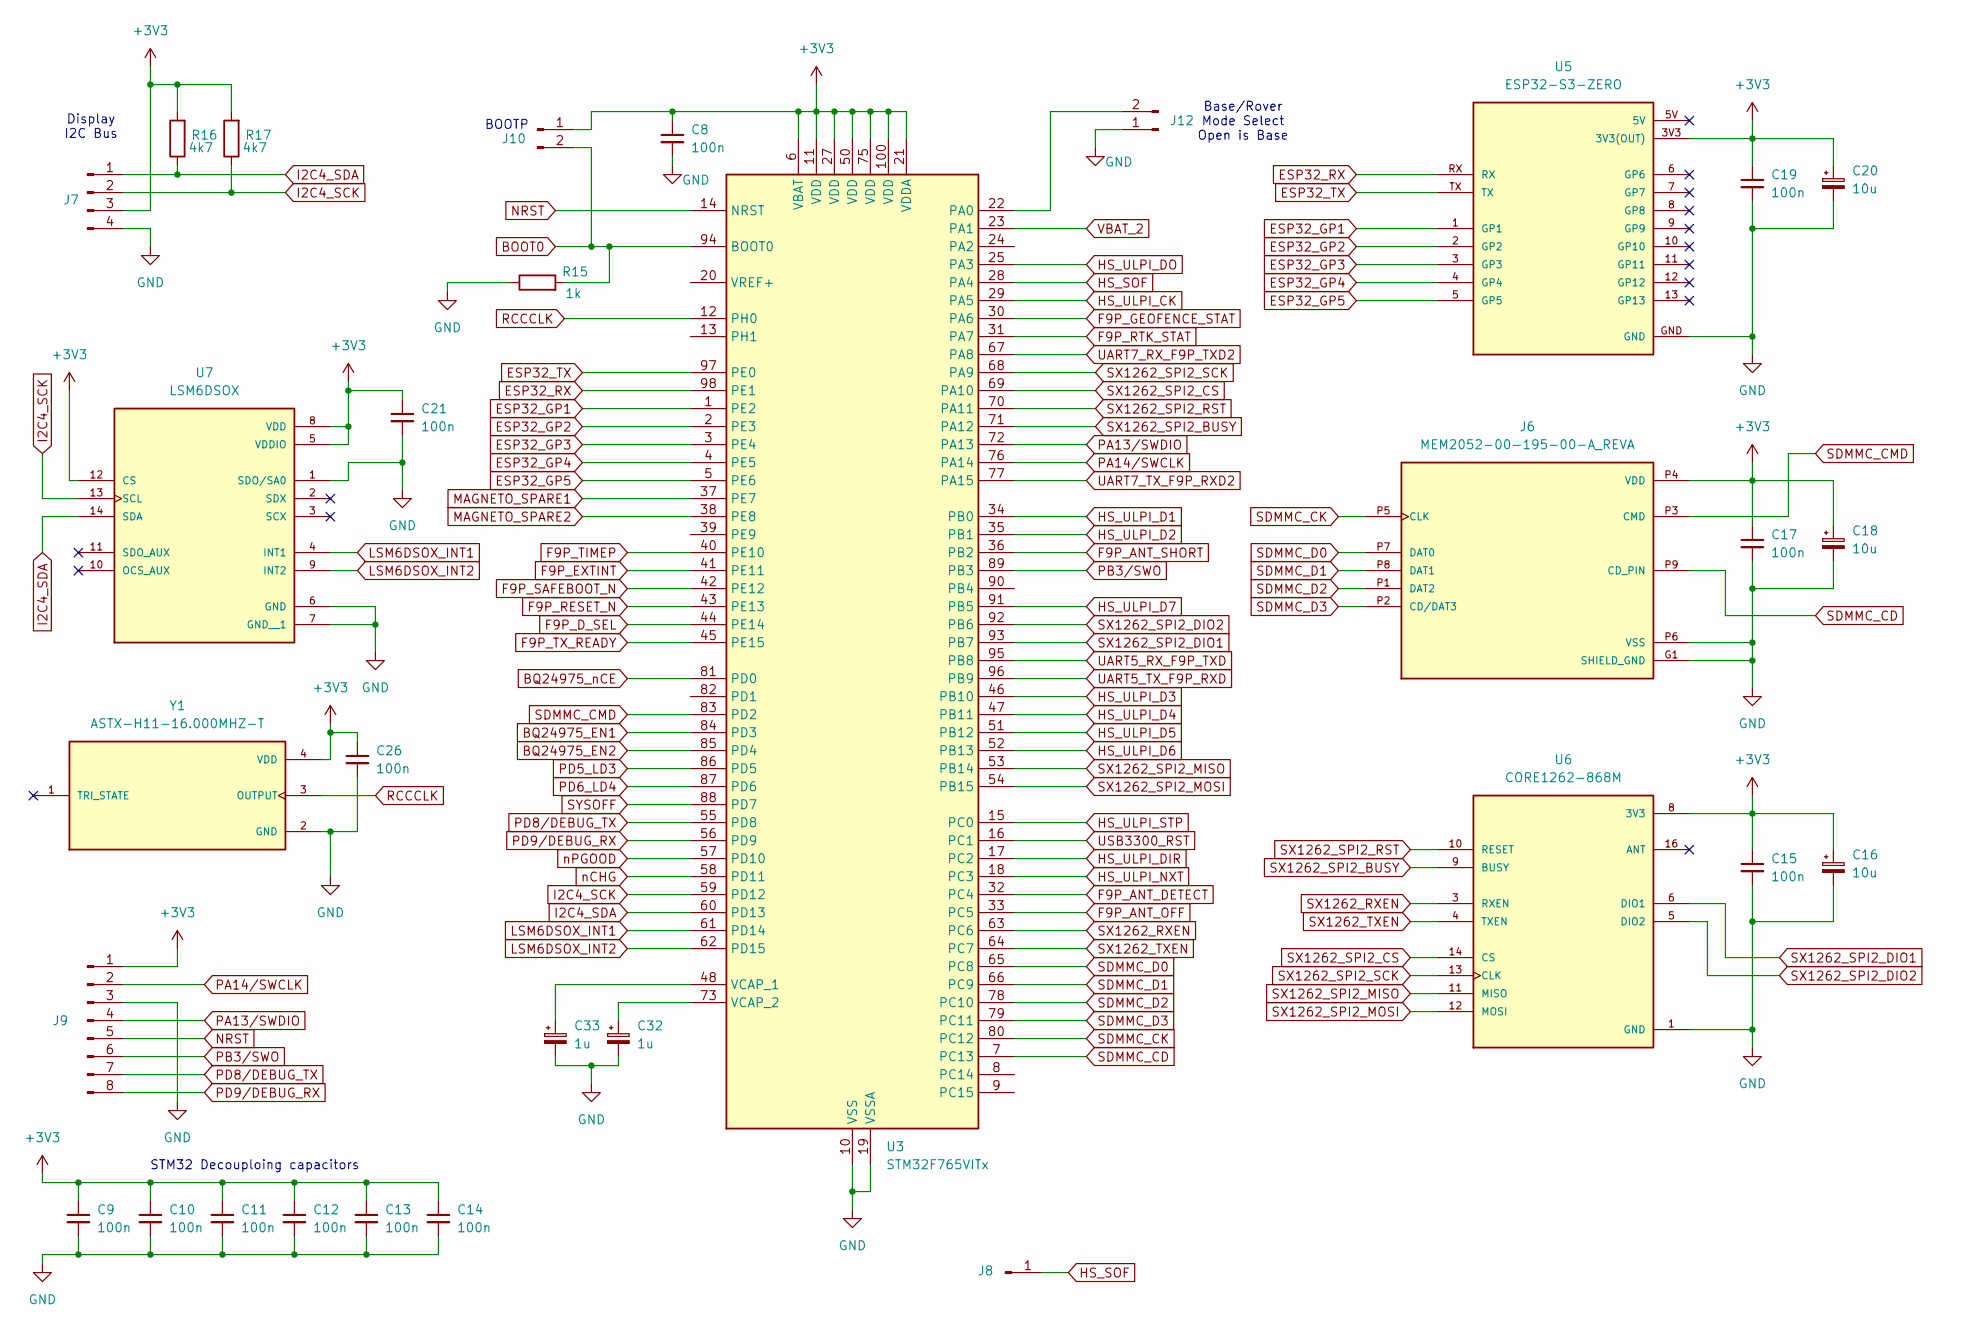
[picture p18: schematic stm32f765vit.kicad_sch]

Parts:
C8, C9, C10, C11, C12, C13, C14, C15, C17, C19, C21, C26: 100n; C_0805_2012Metric_Pad1.18x1.45mm_HandSolder
C16, C18, C20: 10u; C_0805_2012Metric_Pad1.18x1.45mm_HandSolder
C32, C33: 1u; C_0805_2012Metric_Pad1.18x1.45mm_HandSolder
J6: MEM2052-00-195-00-A_REVA; GCT_MEM2052-00-195-00-A_REVA; PARTREV A
J7: Conn_01x04_Pin; PinHeader_1x04_P2.54mm_Vertical
J8: Conn_01x01_Pin; PinHeader_1x01_P2.54mm_Vertical
J9: Conn_01x08_Pin; PinHeader_1x08_P2.54mm_Vertical
J10, J12: Conn_01x02_Pin; PinHeader_1x02_P2.54mm_Vertical
R15: 1k; R_0805_2012Metric_Pad1.20x1.40mm_HandSolder
R16, R17: 4k7; R_0805_2012Metric_Pad1.20x1.40mm_HandSolder
U3: STM32F765VITx; LQFP-100_14x14mm_P0.5mm
U5: ESP32-S3-ZERO; MODULE_ESP32-S3-ZERO; PARTREV NA
U6: CORE1262-868M; XCVR_CORE1262-868M; PARTREV N/A
U7: LSM6DSOX; PQFN50P250X300X86-14N; PARTREV 3.0
Y1: ASTX-H11-16.000MHZ-T; XTAL_ASTX-H11-16.000MHZ-T; PARTREV 05.13.15

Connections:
+3V3: C8.1, C9.1, C10.1, C11.1, C12.1, C13.1, C14.1, C15.1, C16.1, C17.1, C18.1, C19.1, C20.1, C21.1, C26.1, J6.P4 (VDD), J7.3, J9.1, J10.1, R16.2, R17.2, U3.6 (VBAT), U3.11 (VDD), U3.21 (VDDA), U3.27 (VDD), U3.50 (VDD), U3.75 (VDD), U3.100 (VDD), U5.3V3 (3V3(OUT)), U6.8 (3V3), U7.5 (VDDIO), U7.8 (VDD), U7.12 (CS), Y1.4 (VDD); also elsewhere on the board
BOOT0: J10.2, R15.2, U3.94 (BOOT0)
BQ24975_EN1: U3.84 (PD3); also elsewhere on the board
BQ24975_EN2: U3.85 (PD4); also elsewhere on the board
BQ24975_nCE: U3.81 (PD0); also elsewhere on the board
ESP32_GP1: U3.1 (PE2), U5.1 (GP1)
ESP32_GP2: U3.2 (PE3), U5.2 (GP2)
ESP32_GP3: U3.3 (PE4), U5.3 (GP3)
ESP32_GP4: U3.4 (PE5), U5.4 (GP4)
ESP32_GP5: U3.5 (PE6), U5.5 (GP5)
ESP32_RX: U3.98 (PE1), U5.RX
ESP32_TX: U3.97 (PE0), U5.TX
F9P_ANT_DETECT: U3.32 (PC4); also elsewhere on the board
F9P_ANT_OFF: U3.33 (PC5); also elsewhere on the board
F9P_ANT_SHORT: U3.36 (PB2); also elsewhere on the board
F9P_D_SEL: U3.44 (PE14); also elsewhere on the board
F9P_EXTINT: U3.41 (PE11); also elsewhere on the board
F9P_GEOFENCE_STAT: U3.30 (PA6); also elsewhere on the board
F9P_RESET_N: U3.43 (PE13); also elsewhere on the board
F9P_RTK_STAT: U3.31 (PA7); also elsewhere on the board
F9P_SAFEBOOT_N: U3.42 (PE12); also elsewhere on the board
F9P_TIMEP: U3.40 (PE10); also elsewhere on the board
F9P_TX_READY: U3.45 (PE15); also elsewhere on the board
GND: C8.2, C9.2, C10.2, C11.2, C12.2, C13.2, C14.2, C15.2, C16.2, C17.2, C18.2, C19.2, C20.2, C21.2, C26.2, C32.2, C33.2, J6.G1 (SHIELD_GND), J6.G2 (SHIELD_GND), J6.G3 (SHIELD_GND), J6.G4 (SHIELD_GND), J6.P6 (VSS), J7.4, J9.3, J12.1, R15.1, U3.10 (VSS), U3.19 (VSSA), U3.26 (VSS), U3.49 (VSS), U3.74 (VSS), U3.99 (VSS), U5.GND, U6.1 (GND), U6.2 (GND), U6.7 (GND), U6.15 (GND), U7.1 (SDO/SA0), U7.6 (GND), U7.7 (GND__1), Y1.2 (GND); also elsewhere on the board
HS_SOF: J8.1 (Pin_1_1), U3.28 (PA4)
HS_ULPI_CK: U3.29 (PA5); also elsewhere on the board
HS_ULPI_D1: U3.34 (PB0); also elsewhere on the board
HS_ULPI_D2: U3.35 (PB1); also elsewhere on the board
HS_ULPI_D3: U3.46 (PB10); also elsewhere on the board
HS_ULPI_D4: U3.47 (PB11); also elsewhere on the board
HS_ULPI_D5: U3.51 (PB12); also elsewhere on the board
HS_ULPI_D6: U3.52 (PB13); also elsewhere on the board
HS_ULPI_D7: U3.91 (PB5); also elsewhere on the board
HS_ULPI_DIR: U3.17 (PC2); also elsewhere on the board
HS_ULPI_DO: U3.25 (PA3); also elsewhere on the board
HS_ULPI_NXT: U3.18 (PC3); also elsewhere on the board
HS_ULPI_STP: U3.15 (PC0); also elsewhere on the board
I2C4_SCK: J7.2, R17.1, U3.59 (PD12), U7.13 (SCL); also elsewhere on the board
I2C4_SDA: J7.1, R16.1, U3.60 (PD13), U7.14 (SDA); also elsewhere on the board
LSM6DSOX_INT1: U3.61 (PD14), U7.4 (INT1)
LSM6DSOX_INT2: U3.62 (PD15), U7.9 (INT2)
MAGNETO_SPARE1: U3.37 (PE7); also elsewhere on the board
MAGNETO_SPARE2: U3.38 (PE8); also elsewhere on the board
NRST: J9.5, U3.14 (NRST)
unnamed: J12.2, U3.22 (PA0)
unnamed: C33.1, U3.48 (VCAP_1)
unnamed: C32.1, U3.73 (VCAP_2)
PA13/SWDIO: J9.4, U3.72 (PA13)
PA14/SWCLK: J9.2, U3.76 (PA14)
PB3/SWO: J9.6, U3.89 (PB3)
PD5_LD3: U3.86 (PD5); also elsewhere on the board
PD6_LD4: U3.87 (PD6); also elsewhere on the board
PD8/DEBUG_TX: J9.7, U3.55 (PD8)
PD9/DEBUG_RX: J9.8, U3.56 (PD9)
RCCCLK: U3.12 (PH0), Y1.3 (OUTPUT)
SDMMC_CD: J6.P9 (CD_PIN), U3.7 (PC13)
SDMMC_CK: J6.P5 (CLK), U3.80 (PC12)
SDMMC_CMD: J6.P3 (CMD), U3.83 (PD2)
SDMMC_D0: J6.P7 (DAT0), U3.65 (PC8)
SDMMC_D1: J6.P8 (DAT1), U3.66 (PC9)
SDMMC_D2: J6.P1 (DAT2), U3.78 (PC10)
SDMMC_D3: J6.P2 (CD/DAT3), U3.79 (PC11)
SX1262_RXEN: U3.63 (PC6), U6.3 (RXEN)
SX1262_SPI2_BUSY: U3.71 (PA12), U6.9 (BUSY)
SX1262_SPI2_CS: U3.69 (PA10), U6.14 (CS)
SX1262_SPI2_DIO1: U3.93 (PB7), U6.6 (DIO1)
SX1262_SPI2_DIO2: U3.92 (PB6), U6.5 (DIO2)
SX1262_SPI2_MISO: U3.53 (PB14), U6.11 (MISO)
SX1262_SPI2_MOSI: U3.54 (PB15), U6.12 (MOSI)
SX1262_SPI2_RST: U3.70 (PA11), U6.10 (RESET)
SX1262_SPI2_SCK: U3.68 (PA9), U6.13 (CLK)
SX1262_TXEN: U3.64 (PC7), U6.4 (TXEN)
SYSOFF: U3.88 (PD7); also elsewhere on the board
UART5_RX_F9P_TXD: U3.95 (PB8); also elsewhere on the board
UART5_TX_F9P_RXD: U3.96 (PB9); also elsewhere on the board
UART7_RX_F9P_TXD2: U3.67 (PA8); also elsewhere on the board
UART7_TX_F9P_RXD2: U3.77 (PA15); also elsewhere on the board
USB3300_RST: U3.16 (PC1); also elsewhere on the board
VBAT_2: U3.23 (PA1); also elsewhere on the board
nCHG: U3.58 (PD11); also elsewhere on the board
nPGOOD: U3.57 (PD10); also elsewhere on the board

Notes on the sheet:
Base/Rover Mode Select Open is Base
STM32 Decouploing capacitors
Display I2C Bus
BOOTP

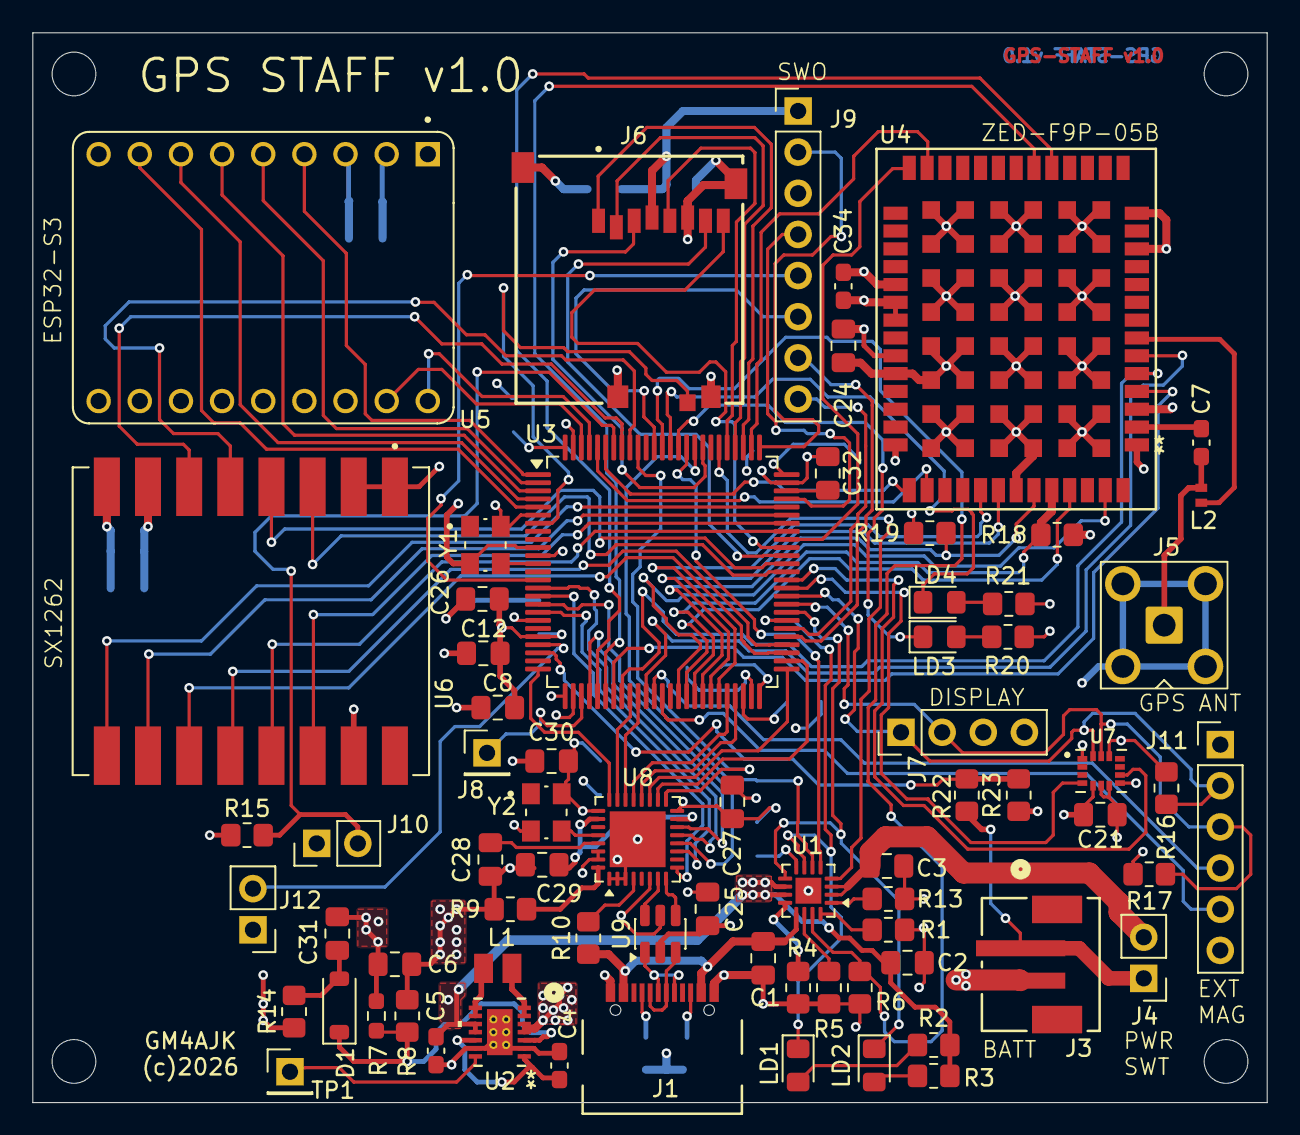
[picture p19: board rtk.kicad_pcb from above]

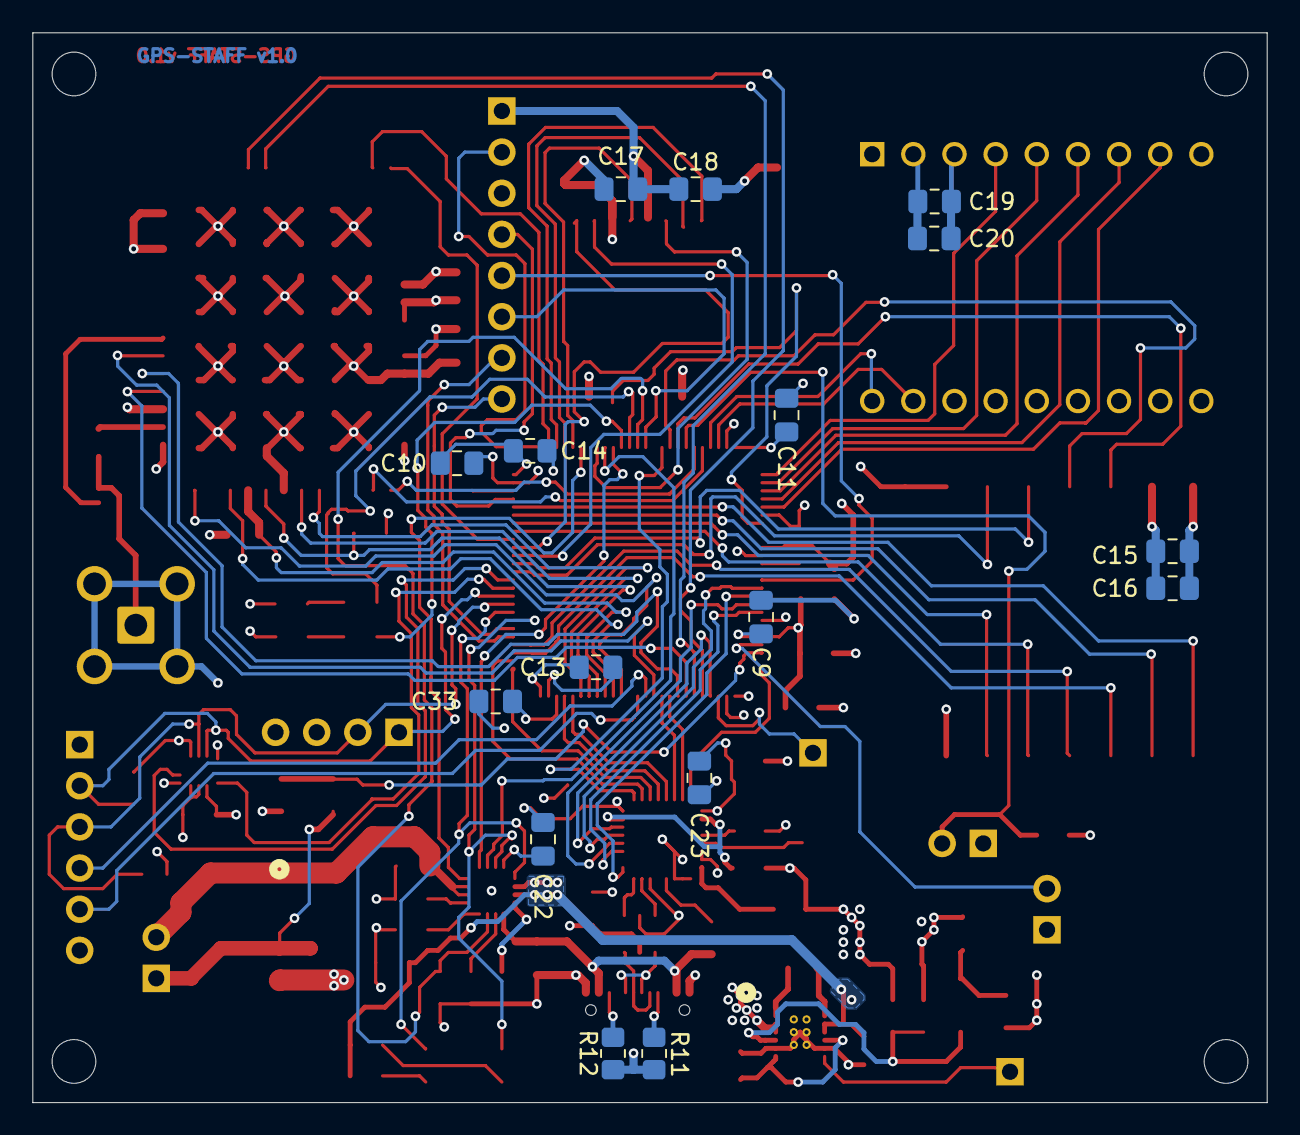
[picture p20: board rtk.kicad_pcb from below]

Board: 4 copper layers, 76.2 x 66.0 mm, 91 parts (16 on the bottom side), 113 nets.

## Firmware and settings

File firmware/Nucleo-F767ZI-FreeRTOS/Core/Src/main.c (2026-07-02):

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
/* Includes ------------------------------------------------------------------*/
#include "main.h"
#include "cmsis_os.h"
#include "fatfs.h"

/* USER CODE BEGIN Includes */
#include "task_logger.h"
#include "task_display.h"
#include "task_ota.h"
#include "task_sdcard.h"
#include "ili9341.h"
/* USER CODE END Includes */


I2C_HandleTypeDef hi2c1;

SD_HandleTypeDef hsd2;
DMA_HandleTypeDef hdma_sdmmc2_rx;
DMA_HandleTypeDef hdma_sdmmc2_tx;

SPI_HandleTypeDef hspi2;
SPI_HandleTypeDef hspi3;
DMA_HandleTypeDef hdma_spi3_tx;

TIM_HandleTypeDef htim14;

UART_HandleTypeDef huart2;
UART_HandleTypeDef huart3;

/* Definitions for defaultTask */
osThreadId_t defaultTaskHandle;
const osThreadAttr_t defaultTask_attributes = {
  .name = "defaultTask",
  .stack_size = 512 * 4,
  .priority = (osPriority_t) osPriorityNormal,
};
/* USER CODE BEGIN PV */
SemaphoreHandle_t hi2c1_mutex;
/* USER CODE END PV */

void SystemClock_Config(void);
static void MPU_Config(void);
static void MX_GPIO_Init(void);
static void MX_DMA_Init(void);
static void MX_USART3_UART_Init(void);
static void MX_I2C1_Init(void);
static void MX_TIM14_Init(void);
static void MX_SPI2_Init(void);
static void MX_USART2_UART_Init(void);
static void MX_SDMMC2_SD_Init(void);
static void MX_SPI3_Init(void);
void StartDefaultTask(void *argument);

/* USER CODE BEGIN PFP */
static void blink_task(void *arg);
/* USER CODE END PFP */

/**
  * @brief  The application entry point.
  * @retval int
  */
int main(void)
{

  /* MPU Configuration--------------------------------------------------------*/
  MPU_Config();

  /* MCU Configuration--------------------------------------------------------*/

  /* Reset of all peripherals, Initializes the Flash interface and the Systick. */
  HAL_Init();

  /* Configure the system clock */
  SystemClock_Config();

  /* USER CODE BEGIN SysInit */
  /* Enable DWT cycle counter for firmware-wide cycle-accurate timestamps.
   * Must be after SystemClock_Config so SystemCoreClock is correct. */
  CoreDebug->DEMCR |= CoreDebug_DEMCR_TRCENA_Msk;
  DWT->CYCCNT = 0;
  DWT->CTRL  |= DWT_CTRL_CYCCNTENA_Msk;
  /* USER CODE END SysInit */

  /* Initialize all configured peripherals */
  MX_GPIO_Init();
  MX_DMA_Init();
  MX_USART3_UART_Init();
  MX_I2C1_Init();
  MX_TIM14_Init();
  MX_SPI2_Init();
  MX_USART2_UART_Init();
  MX_SDMMC2_SD_Init();
  MX_FATFS_Init();
  MX_SPI3_Init();
  /* Init scheduler */
  osKernelInitialize();

  /* USER CODE BEGIN RTOS_MUTEX */
  hi2c1_mutex = xSemaphoreCreateMutex();
  configASSERT(hi2c1_mutex);
  /* USER CODE END RTOS_MUTEX */

  /* USER CODE BEGIN RTOS_SEMAPHORES */
  /* add semaphores, ... */
  /* USER CODE END RTOS_SEMAPHORES */

  /* USER CODE BEGIN RTOS_TIMERS */
  /* start timers, add new ones, ... */
  /* USER CODE END RTOS_TIMERS */

  /* USER CODE BEGIN RTOS_QUEUES */
  /* add queues, ... */
  /* USER CODE END RTOS_QUEUES */

  /* Create the thread(s) */
  /* creation of defaultTask */
  defaultTaskHandle = osThreadNew(StartDefaultTask, NULL, &defaultTask_attributes);

  /* USER CODE BEGIN RTOS_THREADS */
  xTaskCreate(blink_task, "blink", 128, NULL, tskIDLE_PRIORITY + 1, NULL);
  /* USER CODE END RTOS_THREADS */

  /* USER CODE BEGIN RTOS_EVENTS */
  /* add events, ... */
  /* USER CODE END RTOS_EVENTS */

  /* Start scheduler */
  osKernelStart();

  /* We should never get here as control is now taken by the scheduler */

  /* Infinite loop */
  /* USER CODE BEGIN WHILE */
  while (1)
  {
    /* USER CODE END WHILE */

    /* USER CODE BEGIN 3 */
  }
  /* USER CODE END 3 */
}

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
/* USER CODE BEGIN 4 */
void HAL_SD_ErrorCallback(SD_HandleTypeDef *hsd)
{
    sdcard_on_hal_error(hsd);
}

void HAL_SPI_TxCpltCallback(SPI_HandleTypeDef *hspi)
{
    if (hspi->Instance == SPI3)
        ili9341_spi_tx_cplt();
}

static void blink_task(void *arg)
{
    (void)arg;
    for (;;) {
        HAL_GPIO_TogglePin(LD1_GPIO_Port, LD1_Pin);
        vTaskDelay(pdMS_TO_TICKS(500));
    }
}
/* USER CODE END 4 */

/* USER CODE BEGIN Header_StartDefaultTask */
/**
  * @brief  Function implementing the defaultTask thread.
  * @param  argument: Not used
  * @retval None
  */
/* USER CODE END Header_StartDefaultTask */
void StartDefaultTask(void *argument)
{
  /* USER CODE BEGIN 5 */
  logger_init();
  display_init();
  task_sdcard_init();
  task_ota_init();

  /* Allow externally connected devices time to power up */
  vTaskDelay(pdMS_TO_TICKS(500));

  logger_log("\r\n\r\nF767ZI FreeRTOS starting\r\n");
  logger_log("heap free: %u  min-ever: %u  of %u\r\n",
             xPortGetFreeHeapSize(),
             xPortGetMinimumEverFreeHeapSize(),
             configTOTAL_HEAP_SIZE);

  display_clear();
  display_string(0, 0, &ssd130x_font5x7, "F767ZI FreeRTOS");
  display_flush();

  static ili9341_t lcd;
  ili9341_init(&lcd, &hspi3,
               ILI9341_CS_GPIO_Port,   ILI9341_CS_Pin,
               ILI9341_DC_GPIO_Port,   ILI9341_DC_Pin,
               ILI9341_RST_GPIO_Port,  ILI9341_RST_Pin,
               ILI9341_Lite_GPIO_Port, ILI9341_Lite_Pin);
  ili9341_bringup(&lcd);
  ili9341_backlight(&lcd, 1);
  ili9341_dma_init();

  for (;;) {
    ili9341_fill(&lcd, ILI9341_RED);
    vTaskDelay(pdMS_TO_TICKS(500));
    ili9341_fill(&lcd, ILI9341_GREEN);
    vTaskDelay(pdMS_TO_TICKS(500));
  }
  /* USER CODE END 5 */
}

 /* MPU Configuration */

void MPU_Config(void)
{
  MPU_Region_InitTypeDef MPU_InitStruct = {0};

  /* Disables the MPU */
  HAL_MPU_Disable();

  /** Initializes and configures the Region and the memory to be protected
  */
  MPU_InitStruct.Enable = MPU_REGION_ENABLE;
  MPU_InitStruct.Number = MPU_REGION_NUMBER0;
  MPU_InitStruct.BaseAddress = 0x0;
  MPU_InitStruct.Size = MPU_REGION_SIZE_4GB;
  MPU_InitStruct.SubRegionDisable = 0x87;
  MPU_InitStruct.TypeExtField = MPU_TEX_LEVEL0;
  MPU_InitStruct.AccessPermission = MPU_REGION_NO_ACCESS;
  MPU_InitStruct.DisableExec = MPU_INSTRUCTION_ACCESS_DISABLE;
  MPU_InitStruct.IsShareable = MPU_ACCESS_SHAREABLE;
  MPU_InitStruct.IsCacheable = MPU_ACCESS_NOT_CACHEABLE;
  MPU_InitStruct.IsBufferable = MPU_ACCESS_NOT_BUFFERABLE;

  HAL_MPU_ConfigRegion(&MPU_InitStruct);
  /* Enables the MPU */
  HAL_MPU_Enable(MPU_PRIVILEGED_DEFAULT);

}

/**
  * @brief  Period elapsed callback in non blocking mode
  * @note   This function is called  when TIM6 interrupt took place, inside
  * HAL_TIM_IRQHandler(). It makes a direct call to HAL_IncTick() to increment
  * a global variable "uwTick" used as application time base.
  * @param  htim : TIM handle
  * @retval None
  */
void HAL_TIM_PeriodElapsedCallback(TIM_HandleTypeDef *htim)
{
  if (htim->Instance == TIM6)
  {
    HAL_IncTick();
  }
  /* USER CODE BEGIN Callback 1 */
  if (htim->Instance == TIM6) {
      ms_sd_card();
  }
  /* USER CODE END Callback 1 */
}

/**
  * @brief  This function is executed in case of error occurrence.
  * @retval None
  */
void Error_Handler(void)
{
  /* USER CODE BEGIN Error_Handler_Debug */
  /* User can add his own implementation to report the HAL error return state */
  __disable_irq();
  while (1)
  {
  }
  /* USER CODE END Error_Handler_Debug */
}
#ifdef USE_FULL_ASSERT
/**
  * @brief  Reports the name of the source file and the source line number
  *         where the assert_param error has occurred.
  * @param  file: pointer to the source file name
  * @param  line: assert_param error line source number
  * @retval None
  */
void assert_failed(uint8_t *file, uint32_t line)
{
  /* USER CODE BEGIN 6 */
  /* User can add his own implementation to report the file name and line number,
     ex: printf("Wrong parameters value: file %s on line %d\r\n", file, line) */
  /* USER CODE END 6 */
}
#endif /* USE_FULL_ASSERT */

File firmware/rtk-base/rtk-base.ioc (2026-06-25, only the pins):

Mcu.UserName=STM32F765VITx
PA0/WKUP.GPIO_Label=BASE_ROVER_MODE_SELECT
PA0/WKUP.Signal=GPIO_Input
PA1.GPIO_Label=VBATT_IN
PA1.Signal=ADCx_IN1
PA10.GPIO_Label=SX1262_SPI2_CS
PA10.Signal=GPIO_Output
PA11.GPIO_Label=SX1262_SPI2_RST
PA11.Signal=GPIO_Output
PA12.GPIO_Label=SX1262_SPI2_BUSY
PA12.Signal=GPIO_Input
PA13.Signal=SYS_JTMS-SWDIO
PA14.Signal=SYS_JTCK-SWCLK
PA15.GPIO_Label=UART7T_X_F9P_RXD2
PA15.Signal=UART7_TX
PA3.Signal=USB_OTG_HS_ULPI_D0
PA4.Signal=USB_OTG_HS_SOF
PA5.Signal=USB_OTG_HS_ULPI_CK
PA6.GPIO_Label=F9P_GEOFENCH_STAT
PA6.Signal=GPIO_Input
PA7.GPIO_Label=F9P_RTK_STAT
PA7.Signal=GPIO_Input
PA8.GPIO_Label=UART7_RX_F9P_TXD2
PA8.Signal=UART7_RX
PA9.GPIO_Label=SX1262_SPI_CLK
PA9.Signal=SPI2_SCK
PB0.Signal=USB_OTG_HS_ULPI_D1
PB1.Signal=USB_OTG_HS_ULPI_D2
PB10.Signal=USB_OTG_HS_ULPI_D3
PB11.Signal=USB_OTG_HS_ULPI_D4
PB12.Signal=USB_OTG_HS_ULPI_D5
PB13.Signal=USB_OTG_HS_ULPI_D6
PB14.GPIO_Label=SX1262_SPI_MISO
PB14.Signal=SPI2_MISO
PB15.GPIO_Label=SX1262_SPI_MOSI
PB15.Signal=SPI2_MOSI
PB2.GPIO_Label=F9P_ANT_SHORT_N
PB2.Signal=GPIO_Input
PB3.Signal=SYS_JTDO-SWO
PB5.Signal=USB_OTG_HS_ULPI_D7
PB6.GPIO_Label=SX1262_SPI2_DIO2
PB6.Signal=GPIO_Output
PB7.GPIO_Label=SX1262_SPI2_DIO1
PB7.Signal=GPIO_Input
PB8.GPIO_Label=F9P_RX
PB8.Signal=UART5_RX
PB9.GPIO_Label=F9P_TX
PB9.Signal=UART5_TX
PC0.Signal=USB_OTG_HS_ULPI_STP
PC1.GPIO_Label=USB3300_RST
PC1.Signal=GPIO_Output
PC10.Signal=SDMMC1_D2
PC11.Signal=SDMMC1_D3
PC12.Signal=SDMMC1_CK
PC13.GPIO_Label=SDMMC_CD
PC13.Signal=GPIO_Input
PC2.Signal=USB_OTG_HS_ULPI_DIR
PC3.Signal=USB_OTG_HS_ULPI_NXT
PC4.GPIO_Label=F9P_ANT_DETECT
PC4.Signal=GPIO_Input
PC5.GPIO_Label=F9P_ANT_OFF
PC5.Signal=GPIO_Output
PC6.GPIO_Label=SX1262_RXEN
PC6.Signal=GPIO_Output
PC7.GPIO_Label=SX1262T_XEN
PC7.Signal=GPIO_Output
PC8.Signal=SDMMC1_D0
PC9.Signal=SDMMC1_D1
PD0.GPIO_Label=BQ24975_nCE
PD0.Signal=GPIO_Output
PD10.GPIO_Label=nPGOOD
PD10.Signal=GPIO_Input
PD11.GPIO_Label=nCHG
PD11.Signal=GPIO_Input
PD12.Signal=I2C4_SCL
PD13.Signal=I2C4_SDA
PD14.GPIO_Label=LSM6DSOX_INT1
PD14.Signal=GPIO_Input
PD15.GPIO_Label=LSM6DSOX_INT2
PD15.Signal=GPIO_Input
PD2.Signal=SDMMC1_CMD
PD3.GPIO_Label=BQ24975_EN1
PD3.Signal=GPIO_Output
PD4.GPIO_Label=BQ24975_EN2
PD4.Signal=GPIO_Output
PD5.GPIO_Label=PD5_LD3
PD5.Signal=GPIO_Output
PD6.GPIO_Label=PD6_LD4
PD6.Signal=GPIO_Output
PD7.GPIO_Label=SYSOFF
PD7.Signal=GPIO_Output
PD8.GPIO_Label=DEBUG_TX
PD8.Signal=USART3_TX
PD9.GPIO_Label=DEBUG_RX
PD9.Signal=USART3_RX
PE0.Signal=UART8_RX
PE1.Signal=UART8_TX
PE10.GPIO_Label=F9P_TIMEP
PE10.Signal=GPXTI10
PE11.GPIO_Label=F9P_EXTINT
PE11.Signal=GPXTI11
PE12.GPIO_Label=F9P_SAFEBOOT_N
PE12.Signal=GPIO_Output
PE13.GPIO_Label=F9P_RESET_N
PE13.Signal=GPIO_Output
PE14.GPIO_Label=F9P_D_SEL
PE14.Signal=GPIO_Output
PE15.GPIO_Label=F9P_TX_READY
PE15.Signal=GPXTI15
PE2.GPIO_Label=ESP32_GP1
PE2.Signal=GPIO_Output
PE3.GPIO_Label=ESP32_GP2
PE3.Signal=GPIO_Output
PE4.GPIO_Label=ESP32_GP3
PE4.Signal=GPIO_Output
PE5.GPIO_Label=ESP32_GP4
PE5.Signal=GPIO_Output
PE6.GPIO_Label=ESP32_GP5
PE6.Signal=GPIO_Output
PE7.GPIO_Label=MAGNETO_SPARE1
PE7.Signal=GPIO_Output
PE8.GPIO_Label=MAGNETO_SPARE2
PE8.Signal=GPIO_Output
PH0/OSC_IN.Signal=RCC_OSC_IN
PH1/OSC_OUT.Signal=RCC_OSC_OUT

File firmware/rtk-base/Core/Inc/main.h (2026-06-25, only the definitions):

#define ESP32_GP1_Pin GPIO_PIN_2
#define ESP32_GP1_GPIO_Port GPIOE
#define ESP32_GP2_Pin GPIO_PIN_3
#define ESP32_GP2_GPIO_Port GPIOE
#define ESP32_GP3_Pin GPIO_PIN_4
#define ESP32_GP3_GPIO_Port GPIOE
#define ESP32_GP4_Pin GPIO_PIN_5
#define ESP32_GP4_GPIO_Port GPIOE
#define ESP32_GP5_Pin GPIO_PIN_6
#define ESP32_GP5_GPIO_Port GPIOE
#define SDMMC_CD_Pin GPIO_PIN_13
#define SDMMC_CD_GPIO_Port GPIOC
#define USB3300_RST_Pin GPIO_PIN_1
#define USB3300_RST_GPIO_Port GPIOC
#define BASE_ROVER_MODE_SELECT_Pin GPIO_PIN_0
#define BASE_ROVER_MODE_SELECT_GPIO_Port GPIOA
#define VBATT_IN_Pin GPIO_PIN_1
#define VBATT_IN_GPIO_Port GPIOA
#define F9P_GEOFENCH_STAT_Pin GPIO_PIN_6
#define F9P_GEOFENCH_STAT_GPIO_Port GPIOA
#define F9P_RTK_STAT_Pin GPIO_PIN_7
#define F9P_RTK_STAT_GPIO_Port GPIOA
#define F9P_ANT_DETECT_Pin GPIO_PIN_4
#define F9P_ANT_DETECT_GPIO_Port GPIOC
#define F9P_ANT_OFF_Pin GPIO_PIN_5
#define F9P_ANT_OFF_GPIO_Port GPIOC
#define F9P_ANT_SHORT_N_Pin GPIO_PIN_2
#define F9P_ANT_SHORT_N_GPIO_Port GPIOB
#define MAGNETO_SPARE1_Pin GPIO_PIN_7
#define MAGNETO_SPARE1_GPIO_Port GPIOE
#define MAGNETO_SPARE2_Pin GPIO_PIN_8
#define MAGNETO_SPARE2_GPIO_Port GPIOE
#define F9P_TIMEP_Pin GPIO_PIN_10
#define F9P_TIMEP_GPIO_Port GPIOE
#define F9P_EXTINT_Pin GPIO_PIN_11
#define F9P_EXTINT_GPIO_Port GPIOE
#define F9P_SAFEBOOT_N_Pin GPIO_PIN_12
#define F9P_SAFEBOOT_N_GPIO_Port GPIOE
#define F9P_RESET_N_Pin GPIO_PIN_13
#define F9P_RESET_N_GPIO_Port GPIOE
#define F9P_D_SEL_Pin GPIO_PIN_14
#define F9P_D_SEL_GPIO_Port GPIOE
#define F9P_TX_READY_Pin GPIO_PIN_15
#define F9P_TX_READY_GPIO_Port GPIOE
#define SX1262_SPI_MISO_Pin GPIO_PIN_14
#define SX1262_SPI_MISO_GPIO_Port GPIOB
#define SX1262_SPI_MOSI_Pin GPIO_PIN_15
#define SX1262_SPI_MOSI_GPIO_Port GPIOB
#define DEBUG_TX_Pin GPIO_PIN_8
#define DEBUG_TX_GPIO_Port GPIOD
#define DEBUG_RX_Pin GPIO_PIN_9
#define DEBUG_RX_GPIO_Port GPIOD
#define nPGOOD_Pin GPIO_PIN_10
#define nPGOOD_GPIO_Port GPIOD
#define nCHG_Pin GPIO_PIN_11
#define nCHG_GPIO_Port GPIOD
#define LSM6DSOX_INT1_Pin GPIO_PIN_14
#define LSM6DSOX_INT1_GPIO_Port GPIOD
#define LSM6DSOX_INT2_Pin GPIO_PIN_15
#define LSM6DSOX_INT2_GPIO_Port GPIOD
#define SX1262_RXEN_Pin GPIO_PIN_6
#define SX1262_RXEN_GPIO_Port GPIOC
#define SX1262T_XEN_Pin GPIO_PIN_7
#define SX1262T_XEN_GPIO_Port GPIOC
#define UART7_RX_F9P_TXD2_Pin GPIO_PIN_8
#define UART7_RX_F9P_TXD2_GPIO_Port GPIOA
#define SX1262_SPI_CLK_Pin GPIO_PIN_9
#define SX1262_SPI_CLK_GPIO_Port GPIOA
#define SX1262_SPI2_CS_Pin GPIO_PIN_10
#define SX1262_SPI2_CS_GPIO_Port GPIOA
#define SX1262_SPI2_RST_Pin GPIO_PIN_11
#define SX1262_SPI2_RST_GPIO_Port GPIOA
#define SX1262_SPI2_BUSY_Pin GPIO_PIN_12
#define SX1262_SPI2_BUSY_GPIO_Port GPIOA
#define UART7T_X_F9P_RXD2_Pin GPIO_PIN_15
#define UART7T_X_F9P_RXD2_GPIO_Port GPIOA
#define BQ24975_nCE_Pin GPIO_PIN_0
#define BQ24975_nCE_GPIO_Port GPIOD
#define BQ24975_EN1_Pin GPIO_PIN_3
#define BQ24975_EN1_GPIO_Port GPIOD
#define BQ24975_EN2_Pin GPIO_PIN_4
#define BQ24975_EN2_GPIO_Port GPIOD
#define PD5_LD3_Pin GPIO_PIN_5
#define PD5_LD3_GPIO_Port GPIOD
#define PD6_LD4_Pin GPIO_PIN_6
#define PD6_LD4_GPIO_Port GPIOD
#define SYSOFF_Pin GPIO_PIN_7
#define SYSOFF_GPIO_Port GPIOD
#define SX1262_SPI2_DIO2_Pin GPIO_PIN_6
#define SX1262_SPI2_DIO2_GPIO_Port GPIOB
#define SX1262_SPI2_DIO1_Pin GPIO_PIN_7
#define SX1262_SPI2_DIO1_GPIO_Port GPIOB
#define F9P_RX_Pin GPIO_PIN_8
#define F9P_RX_GPIO_Port GPIOB
#define F9P_TX_Pin GPIO_PIN_9
#define F9P_TX_GPIO_Port GPIOB

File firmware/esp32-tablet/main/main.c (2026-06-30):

#include "freertos/FreeRTOS.h"
#include "freertos/task.h"
#include "esp_log.h"
#include "esp_timer.h"
#include "lvgl.h"
#include "bsp.h"
#include "theme.h"
#include "screen_home.h"
#include "screen_base_config.h"
#include "screen_wifi_networks.h"

static const char *TAG = "main";

// ── LVGL tick ─────────────────────────────────────────────────────────────────

#define LVGL_TICK_MS 5

static void lvgl_tick_cb(void *arg)
{
    (void)arg;
    lv_tick_inc(LVGL_TICK_MS);
}

// ── LVGL flush callback (single-buffer direct mode) ───────────────────────────
// The RGB peripheral DMA reads the framebuffer directly; nothing to transfer.

static void lvgl_flush_cb(lv_display_t *disp, const lv_area_t *area, uint8_t *px_map)
{
    (void)area;
    (void)px_map;
    lv_display_flush_ready(disp);
}

// ── LVGL handler task ─────────────────────────────────────────────────────────

static void lvgl_task(void *arg)
{
    (void)arg;
    while (1) {
        uint32_t delay = lv_timer_handler();
        if (delay > 100) delay = 100;
        vTaskDelay(pdMS_TO_TICKS(delay));
    }
}

// ── Touch input device ────────────────────────────────────────────────────────

static esp_lcd_touch_handle_t s_touch;

static void touch_input_cb(lv_indev_t *indev, lv_indev_data_t *data)
{
    (void)indev;
    esp_lcd_touch_read_data(s_touch);

    esp_lcd_touch_point_data_t pt;
    uint8_t cnt = 0;
    esp_err_t ret = esp_lcd_touch_get_data(s_touch, &pt, &cnt, 1);

    if (ret == ESP_OK && cnt > 0) {
        data->point.x = (int32_t)pt.x;
        data->point.y = (int32_t)pt.y;
        data->state   = LV_INDEV_STATE_PRESSED;
    } else {
        data->state = LV_INDEV_STATE_RELEASED;
    }
}

// ── app_main ──────────────────────────────────────────────────────────────────

void app_main(void)
{
    ESP_LOGI(TAG, "GPS Staff esp32-tablet starting");

    // ── Hardware bring-up ──────────────────────────────────────────────────
    esp_lcd_panel_handle_t panel;
    ESP_ERROR_CHECK(bsp_init(&panel, &s_touch));

    // ── PSRAM framebuffer ─────────────────────────────────────────────────
    void *fb = NULL;
    ESP_ERROR_CHECK(bsp_lcd_get_frame_buffer(panel, &fb));
    ESP_LOGI(TAG, "Framebuffer at %p (%u bytes)",
             fb, BSP_LCD_H_RES * BSP_LCD_V_RES * 2);

    // ── LVGL init ──────────────────────────────────────────────────────────
    lv_init();

    lv_display_t *disp = lv_display_create(BSP_LCD_H_RES, BSP_LCD_V_RES);
    lv_display_set_color_format(disp, LV_COLOR_FORMAT_RGB565);
    lv_display_set_flush_cb(disp, lvgl_flush_cb);
    lv_display_set_buffers(disp, fb, NULL,
                           BSP_LCD_H_RES * BSP_LCD_V_RES * sizeof(lv_color16_t),
                           LV_DISPLAY_RENDER_MODE_DIRECT);

    // LVGL tick via esp_timer
    const esp_timer_create_args_t tick_args = {
        .callback = lvgl_tick_cb,
        .name     = "lvgl_tick",
    };
    esp_timer_handle_t tick_timer;
    ESP_ERROR_CHECK(esp_timer_create(&tick_args, &tick_timer));
    ESP_ERROR_CHECK(esp_timer_start_periodic(tick_timer, LVGL_TICK_MS * 1000));

    // ── Touch input device ─────────────────────────────────────────────────
    lv_indev_t *indev = lv_indev_create();
    lv_indev_set_type(indev, LV_INDEV_TYPE_POINTER);
    lv_indev_set_read_cb(indev, touch_input_cb);

    // ── Build screens (all at boot, in PSRAM) ─────────────────────────────
    lv_obj_t *home         = screen_home_create(&theme_dark);
    lv_obj_t *base_config  = screen_base_config_create(&theme_dark);
    lv_obj_t *wifi_networks = screen_wifi_networks_create(&theme_dark);

    // Wire up navigation
    screen_home_set_nav_base(base_config);
    screen_base_config_set_nav_back(home);
    screen_base_config_set_nav_wifi(wifi_networks);
    screen_wifi_networks_set_nav_back(base_config);

    lv_scr_load(home);

    // ── LVGL handler task ─────────────────────────────────────────────────
    xTaskCreate(lvgl_task, "lvgl", 8192, NULL, 5, NULL);

    ESP_LOGI(TAG, "Running");
}

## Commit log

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2026-06-08 Add two new initial codebases for base and rover
    CubeIDE-generated STM32F765 starter projects for the base and rover
    firmware (HAL drivers, linker scripts, .ioc configs). Build artifacts
    under Debug/ are excluded -- fixed the generated .gitignore pattern
    (*/Debug/* -> Debug/*, which didn't match a Debug/ folder sitting
    alongside the .gitignore itself).
    [main.c, main.h, rtk-base.ioc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]
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2026-06-08 Strip rtk-base .ioc to minimal: RCC + USART3 only
    CubeMX regenerated with only RCC, SYS, NVIC, and USART3 (115200 baud,
    PB10/PB11). All other peripheral scaffolding removed — SPI1, USART1/2,
    SDMMC1/DMA, USB OTG HS HAL drivers and MX_*_Init() calls gone. App-owned
    peripherals will be brought up at register level as needed.
    Also removed stale hand-written externs from main.h USER CODE EC block;
    replaced with just extern UART_HandleTypeDef huart3.
    [main.c, main.h, rtk-base.ioc]
2026-06-08 Add SWO to rtk-base .ioc and fix stale USB spec text (#33)
    PB3 (SYS_JTDO-SWO) added to the CubeMX config with SWO debug interface
    mode enabled (2 MHz SWV frequency). Resolves the spec gap flagged by
    spec-review: SWO is one of the four CubeMX-owned items per the peripheral
    init spec.
    Updates the stale TinyUSB sentence in sdd/README.md to reflect that
    TinyUSB brings up USB OTG hardware via its own DWC2 driver, not via
    CubeMX-generated init.
    [rtk-base.ioc]
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2026-06-09 Nucleo-F767ZI: switch clock to HSI, disable USB peripheral (#38)
    The on-board ST-LINK section was cut, so the default HSE source (8 MHz
    MCO from ST-LINK MCU via SB112/SB149) is absent. USB_OTG_FS requires
    HSE to generate an accurate 48 MHz clock; with HSE gone, HAL_RCC_OscConfig
    spun indefinitely waiting for HSERDY.
    Fix: disable USB_OTG_FS in CubeMX and switch PLL source to HSI (16 MHz).
    PLLM=8 → VCO_in = 2 MHz
    PLLN=216 → VCO_out = 432 MHz
    PLLP=2 → SYSCLK = 216 MHz
    PLLQ=9 → 48 MHz output (unused until HSE is restored)
    ETH remains configured; Ethernet MAC timing will be imprecise at HSI
    until an 8 MHz crystal is fitted to the X3 footprint and HSE is re-enabled.
    Board c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
    [Nucleo-F767ZI.ioc, main.c, main.h]
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2026-06-09 Nucleo-F767ZI: replace ETH with I2C1 (PB8/PB9) for sensor bus (#40)
    Disabled the ETH peripheral (not needed for the sandbox) and added
    I2C1 on PB8 (SCL) / PB9 (SDA) with internal pull-ups, ahead of bringing
    up the first I2C device library. ETH HAL driver files removed; LL I2C
    header added by CubeMX.
    Note: the old RMII pins remain configured as inert GPIO_AF11_ETH
    alternate-function pins in MX_GPIO_Init -- harmless leftover from the
    .ioc, to be cleaned up in a later pin audit.
    [Nucleo-F767ZI.ioc, main.c]
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2026-06-10 Nucleo-F767ZI: add BNO085 SPI bring-up driver (#67)
    Adds bno085_init()/bno085_bringup() (reset pulse, wait for INT, single
    SHTP packet read over SPI1) and a one-shot demo in app_init() that
    reports the parsed SHTP header and raw rx buffer over USART3. Bench
    verified: HAL_OK, len=276 chan=0 seq=0, SH-2 advertisement payload.
    [main.h]
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2026-06-11 Remove SPI1/BNO085 GPIO config via CubeMX regeneration
    CubeIDE-regenerated peripheral config after removing SPI1 and the
    BNO085 GPIO pins (CS/RST/WAKE/INT) from the .ioc. HAL_SPI_MODULE_ENABLED
    is now disabled and the SPI HAL/LL driver sources are removed.
    As a side effect of the SPI1/NVIC changes, CubeMX selected TIM14 as the
    new HAL timebase source, adding the TIM HAL driver sources and a
    TIM8_TRG_COM_TIM14 IRQ handler. Flashed and verified the SSD1309 display
    still works correctly.
    [Nucleo-F767ZI.ioc, main.c, main.h]
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2026-06-12 Add BNO085 compass bearing display and revert I2C1 to 100kHz
    Enable Rotation Vector and Magnetic Field Calibrated reports, enable
    continuous ME calibration, and show a bearing/direction, field
    strength and accuracy estimates on the OLED. Apply a fixed 180 degree
    offset to match this board's silkscreen orientation. Move per-loop
    exec timing from the OLED to a 1-second averaged UART log.
    Revert I2C1 from 400kHz back to 100kHz with internal pull-ups enabled
    on PB6/PB7 after a 400kHz attempt locked up both I2C devices.
    [Nucleo-F446RE.ioc, main.c]
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2026-06-13 Remove BNO085 from Nucleo-F446RE; bring up SX1262 SPI2 transport
    BNO085 is no longer fitted to this board, so remove its driver, test
    harness, and notes, and restore app.c to the OLED-only startup. Add an
    SX1262 GPIO/reset/GetStatus driver skeleton and a looping bench test
    in app_loop(), and regenerate SPI2 (2.5MHz, mode 0) via CubeMX.
    Confirmed working on the bench: GetStatus returns 0x2A (STBY_RC,
    stable) once MOSI/MISO were wired the correct way round.
    [Nucleo-F446RE.ioc, main.c, main.h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]
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2026-06-14 Bring up SX1262 SPI2 transport on Nucleo-F767ZI
    Adds the SX1262 GPIO/reset/GetStatus driver skeleton (sx1262.h/.c) and
    looping bench test (test_sx1262.c), ported unchanged from the F446RE
    (PR #95). Wires sx1262_init() into app_init() and the test into
    app_loop() gated on flag_get_100MS().
    Includes the CubeMX regeneration for SPI2 (PB11 RESET, PB12 CS, PB13
    SCLK, PB15 MOSI, PC0 BUSY, PC2 MISO; 8-bit, mode 0, 1.6875MHz) following
    the pin remap to cluster the SX1262 SPI lines onto PB11-15.
    [Nucleo-F767ZI.ioc, main.c, main.h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]
2026-06-14 Raise SPI2 clock for SX1262 on both Nucleo boards
    Bring-up used deliberately slow SPI clocks; now that the transport is
    proven, raise to roughly 10MHz on each board (still well under the
    SX1262's 16MHz max):
    - F446RE: prescaler 16 -> 4 (2.5MHz -> 10MHz exact)
    - F767ZI: prescaler 32 -> 8 (1.6875MHz -> 6.75MHz)
    Confirmed stable GetStatus=0x2A (STBY_RC) on both at these speeds. The
    F767ZI was also tried at prescaler 4 (13.5MHz), which worked but showed
    a flipped reserved bit (0xAA vs 0x2A) - likely breadboard signal
    integrity, so settled on 6.75MHz as the cleaner/more conservative step.
    [Nucleo-F446RE.ioc, Nucleo-F767ZI.ioc, main.c]
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2026-06-14 Add CalibrateImage(430-440MHz); fixes SetTx/SetRx failing in STBY_RC
    The diagnostic added in the previous commit showed chip mode=2
    (STBY_RC), cmd status=5 ("failure to execute command") after both
    SetTx and SetRx - the chip never left STBY_RC. Root cause: the
    factory-default image calibration only covers 902-928MHz, but we're
    operating at 434MHz. test_sx1262_config() now calls CalibrateImage
    (0x98) for the 430-440MHz band after SetRfFrequency, so the PLL can
    lock and SetTx/SetRx can actually enter TX/RX mode.
    [sx1262.c, sx1262.h]
2026-06-14 Add GetDeviceErrors diagnostic to TX/RX bench test
    CalibrateImage didn't change the cmd status=5 ("failure to execute
    command") seen on both boards after SetTx/SetRx. GetDeviceErrors
    (0x17) reports the OpError register directly (calibration/PLL/XOSC
    failure flags), which should narrow down why the chip can't leave
    STBY_RC.
    [sx1262.c, sx1262.h]
2026-06-14 Add SetDIO3AsTCXOCtrl; fixes XOSC_START_ERR preventing TX/RX
    GetDeviceErrors reported errors=0x0020 (XOSC_START_ERR) on both
    boards. Per the Core1262-LF schematic, the 32MHz reference is a TCXO
    (Q1) powered via DIO3, not a passive crystal on XTA/XTB - without
    SetDIO3AsTCXOCtrl the TCXO never gets power, the chip can't lock the
    PLL, and SetTx/SetRx fail (chip mode stays STBY_RC, cmd status =
    failure to execute). test_sx1262_config() now configures DIO3 for
    1.8V/5ms first thing after reset and clears the resulting (expected,
    per datasheet) error flag.
    [sx1262.c, sx1262.h]
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2026-06-14 Wire SX1262 DIO1 as EXTI rising-edge interrupt on both boards
    Configure DIO1 (PC9) as GPIO_MODE_IT_RISING with EXTI9_5_IRQn enabled
    on both Nucleo-F767ZI and Nucleo-F446RE, mirrored in the .ioc files.
    SetDioIrqParams now routes TxDone/RxDone/Timeout to DIO1. A new
    HAL_GPIO_EXTI_Callback sets a flag that app_loop logs, to verify the
    interrupt fires before reworking the tx/rx polling loops to use it.
    [Nucleo-F446RE.ioc, Nucleo-F767ZI.ioc, main.c]
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2026-06-14 Fix empty SNR in rx done log (nano-newlib lacks printf %f)
    GetPacketStatus's SnrPkt is now returned raw (int8_t, 0.25dB steps)
    instead of as a float, and test_sx1262_rx_done() formats it with
    integer math - app_log()'s vsnprintf otherwise printed nothing for
    %f. Also includes CubeIDE's printf-float linker option enabled on both
    projects (harmless, no longer required by this fix but left in for
    future float debugging).
    [sx1262.c, sx1262.h]
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2026-06-14 Replace app_log dependency in sx1262.c with a logger callback
    sx1262.c no longer includes app.h. Instead, sx1262_t gains an optional
    logger field (void(*)(const char *buf, int len)) set via
    sx1262_set_logger_callback(), invoked by an internal vsnprintf-based
    helper for error/timeout/RxDone/TxDone messages. The whole mechanism
    (struct field, setter, helper and format calls) is wrapped in
    #ifdef SX1262_WITH_LOGGING so it compiles out entirely when undefined.
    app.c registers a small adapter that forwards to the existing debug
    UART.
    [sx1262.c, sx1262.h]
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2026-06-15 Add DWT cycle counter timestamps to SX1262 TX/RX logs
    Enables the DWT cycle counter in app_init() on both boards and adds
    cyc=<DWT->CYCCNT> to the rx done / tx done / tx timeout log lines, to
    help diagnose the LoRa missed-ping pattern by comparing real elapsed
    time between events on each board. Drops the per-second "rx timeout"
    log line since it just clutters the output and DWT timestamps on the
    rx done/tx done lines give better timing data anyway.
    Also includes the F446RE CubeMX regeneration bumping SYSCLK to 180MHz
    (PLLN 80->180, APB1 prescaler DIV2->DIV4) and associated .ioc/.cproject
    changes.
    [Nucleo-F446RE.ioc, main.c, main.h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]
2026-06-15 Revert F446RE clock config (.ioc/CubeMX regen) to main
    The 180MHz SYSCLK experiment broke the F446RE bring-up; revert the
    .ioc and its generated files (main.c, main.h, stm32f4xx_it.h,
    .cproject) back to main's clock config. DWT timing changes are
    unaffected.
    [Nucleo-F446RE.ioc, main.c, main.h]
2026-06-15 Sync F446RE generated code with reverted .ioc
    CubeIDE regen after the .ioc revert: replaces raw GPIOC with the
    SX1262_SPI_DIO1/DIO2_GPIO_Port macros and adds the EXTI9_5_IRQn/
    EXTI9_5_IRQHandler declarations - same pins/port, no functional change.
    [main.c, main.h]
2026-06-15 Sync F446RE .ioc/.cproject to 180MHz SYSCLK
    main.c already has PLLN=180 (180MHz) from re-applying this after the
    power-cycle fix; bring the .ioc/.cproject back in sync so CubeIDE
    regen doesn't fight it. 180MHz gives rx done cyc deltas matching the
    F767ZI's 10.000s TX cadence to within ~0.1% (HSI tolerance).
    [Nucleo-F446RE.ioc]
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2026-06-15 Fix F446 RX permanently stalling on non-RxDone DIO1 IRQs
    sx1262_set_rx() puts the radio in Rx Single mode, which exits RX on
    any DIO1 IRQ (RxDone, timeout, CRC/header error, etc.), but app_loop()
    only re-armed RX when sx1262_service_rx() returned true (RxDone). Any
    other IRQ left the radio in standby with no further DIO1 events,
    silently stalling reception - reproduced when bumping the LoRa test
    payload to 255 bytes. Now re-arm RX after servicing any DIO1 IRQ, and
    log the IRQ bits when RxDone wasn't set for diagnosis.
    [sx1262.c]
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2026-06-15 Drop GFSK packets that fail the SX1262 CRC check
    sx1262_service_rx() only checked RX_DONE, so corrupted-air packets
    (CRC16 failure, no FEC in GFSK) were logged and dispatched to rx_done
    as if valid. Now logs a CRC error and skips the payload read/callback
    when CRC_ERR is set alongside RX_DONE.
    [sx1262.c]
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2026-06-16 Add rtcm3 module: IRQ-driven UART receive with CRC24Q validation (#134)
    * Add rtcm3 module: IRQ-driven UART receive with CRC24Q validation
    Replaces the previous polling f9p_service() with a proper interrupt-
    driven RTCM3 framing layer. rtcm3_uart_in_irq() runs from the USART2
    RxCplt callback, assembles complete frames into a 4-slot × 2048-byte
    buffer pool, and signals rtcm3_loop() via a ready bitmask. The loop
    validates CRC24Q and logs "RTCM3 message received, CRC OK/FAIL".
    * Fix rtcm3 USART2 IRQ wiring: CubeMX NVIC enable + direct ISR call
    Enable USART2_IRQn via CubeMX (HAL_NVIC_SetPriority/EnableIRQ in
    MspInit). Call rtcm3_uart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
    [Nucleo-F767ZI.ioc]
2026-06-16 OTA chunking module: rtcm3 → ota → sx1262 TX chain (base side) (#136)
    * Add OTA chunking module and wire rtcm3 → ota → sx1262 TX chain
    - rtcm3: replace uart_dbg with on_frame callback; rtcm3_loop() fires callback
    on CRC-valid frames and silently drops failures
    - ota: new module that memcpy's the frame, splits into 255-byte chunks
    (5-byte header + 250 bytes data), and drives sx1262 TX sequentially via
    the tx_done callback chain; static ota_instance used since sx1262_t has
    no user_data field
    - app: wire on_rtcm3_frame() → ota_push_frame(); DIO1 service moved out
    of TEST_SX1262 guard; PING test scaffolding removed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
    [sx1262.c, sx1262.h]
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2026-06-16 F446RE rover: add USART3 for RTCM3 output; defer TX to after radio re-arm
    Adds USART3 (PC10 TX → G431 PA10 RX, 115200 8N1) for forwarding
    reassembled RTCM3 frames to the Fake-F9P-Rover.
    The TX is deliberately deferred: on_rtcm3_frame (called from inside
    sx1262_service_rx) copies the frame into a pending buffer instead of
    transmitting immediately. app_loop transmits after sx1262_set_rx so
    a slow or broken UART can never block radio re-arming and cause CRC
    errors on subsequent receptions.
    Includes CubeIDE-regenerated files for the USART3 peripheral addition.
    [Nucleo-F446RE.ioc, main.c, main.h]
2026-06-16 F446RE rover: disable SX1262_WITH_LOGGING to fix missing 1005 frame
    SX1262_WITH_LOGGING adds ~6.5ms of blocking UART output per packet
    inside sx1262_service_rx, before set_rx re-arms the radio. When
    combined with the 47.8ms UART TX for the 1124 frame, the total
    blocking window was ~66ms — long enough for a 434 MHz ISM interferer
    to arrive and displace the 1005 OTA packet in the SX1262 ring buffer.
    Disabling the logging reduces the blocking window to ~51ms, which is
    below the ~61ms point at which the interferer consistently appears.
    The radio is re-armed early enough to capture 1005 before ISM arrives.
    Also includes:
    - F446RE main.h: CubeMX-generated USART3 pin-name aliases (USART3_RX_F9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
    [main.h, sx1262.h]
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2026-06-16 sx1262: rename callback struct fields to on_ prefix for consistency
    rtcm3_t and ota_rx_t already use on_frame; sx1262_t used bare names
    (rx_done, tx_done, rx_timeout, tx_timeout, logger). Rename all to
    on_rx_done, on_tx_done, on_rx_timeout, on_tx_timeout, on_log so every
    callback field in every module follows the same on_ convention.
    Also fixes two stale comments: ota_init() → ota_tx_init() in
    sx1262_config_gfsk doc, and ota.h → ota_tx.h in ota_rx.h.
    No logic changes.
    [sx1262.c, sx1262.h]
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2026-06-17 Add AT24C256-backed persistent config module to F446RE (#150)
    * Add AT24C256-backed persistent config module to F446RE
    config.h/c maintains a 64-byte config_data_t in RAM loaded from the
    AT24C256 EEPROM at startup. Getters give fast RAM reads; setters update
    RAM, recompute CRC-16/CCITT, and write the full page back to EEPROM,
    polling ACK for write-cycle completion. Blank or corrupt EEPROM falls
    back to factory defaults (zero hard-iron, identity soft-iron matrix).
    Initially holds LIS3MDL hard-iron offset vector and soft-iron 3x3
    correction matrix, with 4 bytes of padding reserved for future fields.
    * Wire config_init/config_load in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
    [config.c]
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2026-06-18 Add SDMMC2 Card Detect GPIO and improve startup identification logs (#155) (#155)
    Keep PG13 (SDMMC_CD) as a pull-up GPIO input on F767ZI after rolling back
    the SDMMC2 peripheral — the pin wiring is done and will be needed when
    SDMMC2 is re-added for SD card development. Add "F767ZI starting" log before
    OLED init so the early boot sequence is visible on the serial monitor even
    if OLED bringup fails. Label Fake-F9P-Base TX log as "Fake-F9P-Base:" to
    match the board identification convention used on the other boards.
    [Nucleo-F767ZI.ioc, main.c, main.h]
2026-06-18 Add SDMMC2/FatFS to F767ZI sandbox with bench-verified SD write/read (#156)
    * Add SDMMC2/FatFS to F767ZI sandbox with bench-verified SD write/read (#156)
    Enables SDMMC2 in CubeMX with FatFS middleware and bench-tests a full
    write/read cycle on the SD card breakout board. OTA (USART2 → SX1262 GFSK)
    continues to work throughout with card inserted.
    Key findings documented in SDMMC-BUGS.md:
    - BUG-SDMMC-001 (prior): boot crash without card — fixed with CD pin guard
    - BUG-SDMMC-003: HAL_SD_ERROR_RX_OVERRUN in 4-bit polling mode at 24 MHz;
    root cause is STM32F7 SDMMC HW flow-control errata (ES0334). In 1-bit mode
    the FIFO fills 4× slower so ClockDiv=0 (24 MHz, ~3 MB/s) is safe.
    - BUG-SDM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
    [Nucleo-F767ZI.ioc, main.c, main.h]
2026-06-18 Remove FatFS SD card test from F767ZI base firmware (#157)
    * Remove FatFS SD card test from F767ZI base firmware (#151)
    FatFS proved unreliable on STM32 SDMMC — impossible to get robust
    boot behaviour across card-present / card-absent / cold-power-cycle
    scenarios without intermittently killing OTA. Rip out all application-
    level SD code rather than continue debugging.
    - app.c: remove BSP_SD_Init override, sd_late_init, #ifdef TEST_SDCARD
    blocks, FatFS/BSP includes, and the now-empty app_tests() scaffolding
    - main.c: remove CD-pin bounce-poll from MX_SDMMC2_SD_Init USER CODE
    - sd_diskio.c: retain timeout guards (SDMMC_DATATIMEOUT 5000 ms, bounded
    GetCardState loops) and SDMMC-BUGS.md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
    [Nucleo-F767ZI.ioc, main.c, main.h]
2026-06-18 Revert F767ZI to pre-SDMMC/FatFS state (restore to #147) (#158)
    SDMMC/FatFS work (PRs #155–#157) broke the SSD1309 OLED — white screen
    on every boot. Restore firmware/Nucleo-F767ZI/ to the state at commit
    06c760a ("Label F767ZI base startup message", #147), before any SD card
    work was introduced.
    [Nucleo-F767ZI.ioc, main.c, main.h]
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2026-06-19 Add OLED display task to F767ZI FreeRTOS project (#160)
    * Add OLED display task to F767ZI FreeRTOS project
    display_task owns hi2c1/SSD1309 and accepts CLEAR/STRING/FLUSH
    messages via a queue. Callers compose a screen update as a sequence
    of display_send() calls with no direct driver access.
    ssd1309.c/.h copied verbatim from the reference project. logger.c
    indentation fixed to tabs.
    * Rename task source files to task_xxxx.c/.h convention
    display.c/.h → task_display.c/.h
    logger.c/.h → task_logger.c/.h
    All includes updated in main.c and the task source files themselves.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
    [main.c, task_display.c]
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2026-06-19 Add display_clear/string/flush helpers; make msg struct internal (#163)
    * Add display_clear/string/flush helpers; make msg struct internal
    Callers no longer construct display_msg_t directly. display_string()
    is variadic so formatted text works without a separate snprintf.
    display_msg_t and display_send() are now private to task_display.c.
    * Split display_string into safe and va variants
    display_string() takes const char* — no va_list, stack-safe for
    production callers. display_va_string() retains the variadic form
    for debug use; the name flags the stack risk.
    * Add doc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
    [main.c, task_display.c]
2026-06-19 Log heap watermark at startup (#164)
    Prints free, min-ever, and total heap after all tasks and queues are
    created. If free == min-ever the heap has only grown, never shrunk —
    confirming the allocation watermark is fixed for the run.
    [main.c]
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2026-06-19 SD card Step 4: MOUNTING state — f_mount + open_next_file (#167)
    * Add SD card logging task to F767ZI FreeRTOS base station (#166)
    Adds task_sdcard: FatFS-based RTCM3 frame logger to SD card with
    hot-eject recovery. Includes DWT cycle counter enable in main.c for
    firmware-wide ms timestamps, SDMMC2 peripheral + DMA init via CubeMX,
    and the full FatFS + DMA RTOS driver stack.
    Active debugging: f_mount fails with FR_DISK_ERR (~10 s) on hot-eject
    remount; adds two volatile diagnostic probes (diag_bsi_enter at
    BSP_SD_Init entry, diag_sdr_enter at SD_read entry) captured in a
    single post-f_mount log so the delay can be located without relying on
    droppable logger queue messages.
    Co-Authored-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
    [Nucleo-F767ZI-FreeRTOS.ioc, main.c, main.h]
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2026-06-20 Increase SDMMC2 clock speed and make sd_diskio.c regen-safe (#169)
    * Increase SDMMC2 clock speed and make sd_diskio.c regen-safe (#169)
    Bump SDMMC2 ClockDiv from 12 → 4 in the .ioc (tested working at the
    higher speed). The CubeMX regen overwrote the sd_diskio.c function
    bodies with its osMessageQueue approach; fix that vulnerability by
    placing #define rename macros in the beforeFunctionSection USER CODE
    block that redirect every CubeMX-generated body to a _cx_* dead-code
    symbol, with real DMA + semaphore implementations in lastSection.
    cmsis_os stubs in firstSection allow the dead-code bodies to compile
    in this bare FreeRTOS project. All USER CODE sections survive regen,
    so re-applying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
    [Nucleo-F767ZI-FreeRTOS.ioc, main.c, main.h]
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2026-06-20 Migrate F446RE Rover from super-loop to FreeRTOS (#171)
    * Migrate F446RE Rover from super-loop to FreeRTOS (#171)
    Enable FreeRTOS (CMSIS-RTOS V2, TIM6 as HAL timebase) via CubeMX regen
    and replace the bare-metal app_init/app_loop architecture with two tasks:
    task_logger — queue-based non-blocking UART2 logging (replaces app_log)
    task_ota_rx — blocks on binary semaphore from DIO1 EXTI ISR; services
    sx1262_service_rx, re-arms RX, and forwards complete RTCM3
    frames to UART3 via blocking HAL_UART_Transmit in task
    context (no busy-flag needed)
    All drivers (sx1262, ota_rx, ssd1309, lsm6dsrx, config) are unchanged.
    flags.c/h and app.c/h are dele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
    [Nucleo-F446RE.ioc, lsm6dsrx.c, main.c]
2026-06-20 Fix main.c FreeRTOS headers and remaining app.h includes in F446RE (#172)
    Add #include FreeRTOS.h + semphr.h to main.c USER CODE Includes so
    SemaphoreHandle_t and xSemaphoreCreateMutex resolve cleanly.
    Remove stale #include app.h from ota_rx.c and stm32f4xx_it.c.
    [main.c]
2026-06-20 Extract task_display for F446RE rover (#174)
    * Extract task_display for F446RE rover, matching F767ZI pattern
    Add task_display.c/h — queue-based SSD1309 owner (display_init,
    display_clear, display_string, display_va_string, display_flush).
    Remove OLED ownership from task_ota_rx: ssd1309_t and bringup move
    into the display task; RSSI/SNR and no-signal updates use display_*
    API instead of inline I2C calls. Also fixes a latent race: config_load
    now runs under hi2c1_mutex so it can't collide with the display task's
    bringup I2C traffic.
    * Fix missing extern hi2c1_mutex in task_display.c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
    [main.c, task_display.c]
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2026-06-20 Add DMA-driven ILI9341 fill and image display on F767ZI (#175) (#176)
    SPI3 TX DMA (DMA1 Stream5 Ch0) configured in CubeMX. fill_rect replaced
    with a multi-row DMA loop using a 32-row SRAM bounce buffer (15 KB),
    reducing context switches from 320 to 10 per full-screen fill. draw_image
    added for displaying pre-packed RGB565 byte arrays, also via the SRAM
    bounce buffer (DMA cannot source directly from Flash on Cortex-M7 AXIM).
    HAL_SPI_TxCpltCallback in main.c signals a binary semaphore to pace
    successive DMA transfers. Red/green alternating fill used as bringup test.
    [Nucleo-F767ZI-FreeRTOS.ioc, main.c]
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

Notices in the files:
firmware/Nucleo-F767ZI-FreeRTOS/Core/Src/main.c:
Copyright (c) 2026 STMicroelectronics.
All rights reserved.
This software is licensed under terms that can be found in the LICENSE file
